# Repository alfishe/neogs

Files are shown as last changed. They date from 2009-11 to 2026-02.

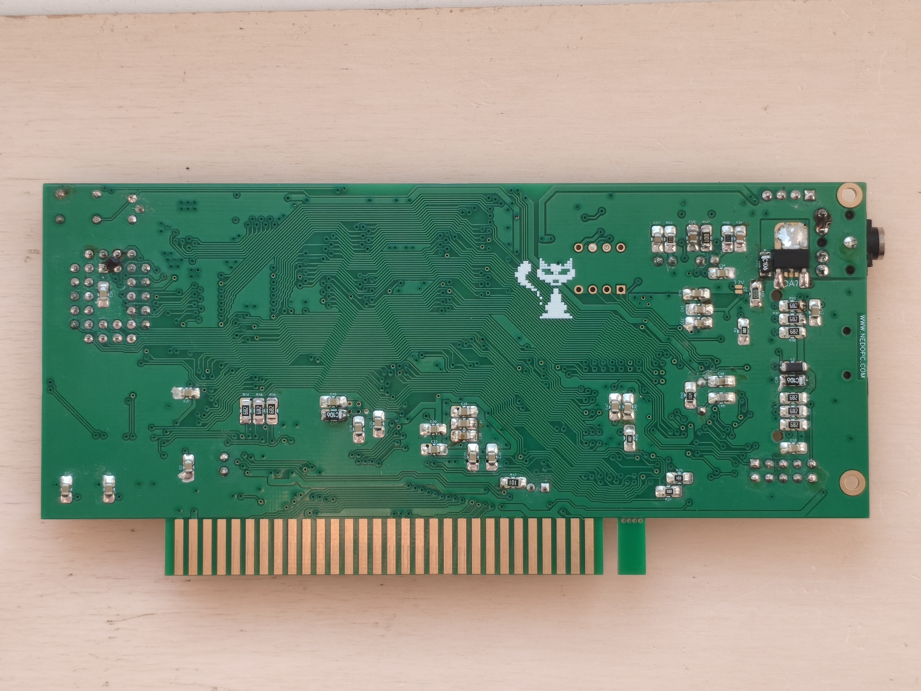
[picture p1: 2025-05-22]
docs/photo/revC-VS/IMG_20250522_185913.jpg

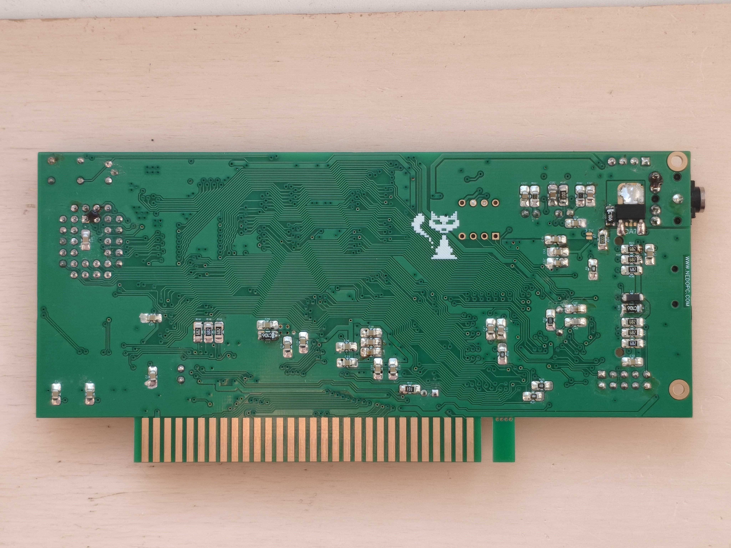
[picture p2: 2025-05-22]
docs/photo/revC-VS/IMG_20250522_185911.jpg

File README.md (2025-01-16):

Музыкальная карта NeoGS для ZXBUS     

#### Музыкальная карта NeoGS для ZXBUS!

#### [english](ngs_eng.php)

**ВНИМАНИЕ!** **Изделие поставляется независимым производителем. Обращаться по поводу приобретения к Виталию [tetroid@inbox.ru](mailto:tetroid@inbox.ru).**

- - -

_Автор фотографий: Алексей Курепин._

NGS rev.C front (http://nedopc.com/gs/neogs_c_front.jpg) NGS rev.C back (http://nedopc.com/gs/neogs_c_back.jpg)  

Звуковая плата **NeoGS** предназначена для проигрывания трекерной (MOD) и сжатой (MP3) музыки на Spectrum-совместимом компьютере оснащенным слотом ZXBUS.

**Разработка:**  
hardware: Вадим Акимов (LVD), Чунин Роман (CHRV), Вячеслав Савенков (Savelij), Жабин Алексей (KOE), Василий Климов (JTN);  
software: Вячеслав Савенков (Savelij).

### Характеристики:

*   полная программная совместимость с General Sound (далее GS);
*   гибкая архитектура, основанная на fpga (Altera EP1K30);
*   собственная память 4 мегабайта RAM, 512 килобайт flash-ROM;
*   расширенные способы адресации памяти: 2 окна проецирования, полное исключение ROM из адресного пространства;
*   Z80 с переключаемой частотой (10, 12, 20 и 'турбо'-24 МГц);
*   8 аппаратных звуковых каналов с громкостями (в 2 раза больше, чем у GS);
*   mp3-декодер (аналог vs1011) с аппаратным SPI для пересылки данных;
*   интерфейс SD-card с аппаратным SPI для пересылки данных;
*   DMA-доступ спектрума в память NeoGS (пересылка данных между спектрумом и NeoGS командами LDI, LDIR и подобными);
*   возможность полностью автономной работы (проигрывание модулей и mp3-файлов с SD-карточки по плейлисту, при этом сброс спектрума не влияет на NeoGS).

### Обновления:

Апгрейд прошивки от 15.06.2013 [здесь](up130615.zip).  
Ускорена конвертация загруженного модуля. Частота процессора всегда 20 МГц вместо стандартных 12 МГц, выставляется загрузчиком.

Апгрейд прошивки от 19.01.2011 [здесь](up110119.zip).  
Поддержка версий с 4Мb RAM.

Апгрейд прошивки от 03.07.2009 [здесь](up090703.zip).  
Поддержан DMA режим работы. Также появился загрузчик кода с SD карты. Описание загрузчика в прилагаемом с флашером документе.

Апгрейд прошивки от 03.11.2008 [здесь](up081103.zip).

### Документация:

_Форум поддержки пользователей **[здесь](http://forum.nedopc.com)**_.

Принципиальная схема (revision C) [здесь](scheme.pdf).

Монтажная схема (revision C) [здесь](montage.pdf).

Руководство пользователя для печати (revision C) [здесь](ngs_c.pdf).

Руководство по сборке платы (revision C) [здесь](ngs_c_soldering.pdf).

Документация для производства [здесь](ngs_c.zip) \[PCAD\] (использование в коммерческих целях только по договоренности с представителями [NedoPC](/aboutus.php)).

О прошивке NeoGS (revision C) [здесь](ngs_c_flash.pdf).

Бинарные файлы прошивок (revision C) [здесь](ngs_c_roms.zip).

Руководство программиста NeoGS [здесь](ngspgm_01a.pdf) и заголовочный файл с описанием портов NeoGS [здесь](ports.zip).

Руководство программиста General Sound [здесь](gs_prog.pdf).

Зеркало исходников (SVN) доступно на сайте [**ZXEVO.RU**.](http://svn.zxevo.ru/listing.php?repname=ngs)

Файл прошивки для записи в ПЗУ из SVN: [**full\_ngs.rom**.](http://svn.zxevo.ru/filedetails.php?repname=ngs&path=%2Fz80%2Fcreate_update%2Ffull_ngs.rom)

**ЦЕНЫ:** [здесь](tetroid.nedopc.com).

### Software:

Программа **Neo Player Light** для проигрывания mp3 музыки на NeoGS [здесь](npl.php).

Программа **Neo8Tracker** трекер/редактор для NeoGS [здесь](neo8tracker/neo_tracker.php).

Программа **Z-PLAYER** проигрыватель mod'ов для GS и NeoGS [здесь](zplayer/zplayer.php).

Страничка с General Sound играми и утилитами на VTRDOS [здесь](http://vtrdos.ru/gs.php).

Страничка с образами дисков с музыкой на ZXAAA [здесь](http://zxaaa.untergrund.net/DISKAAA4.html).

### История версий:

**Revision C:**

*   Уменьшена высота платы (до 61мм без учета разъема).
*   Увеличен размер памяти до 4Мб.
*   Добавлен джампер RESET для разрешения сброса карты при сбросе компьютера.
*   Изменена элементная база (совместимость по прошивкам fpga сохранена).

**[Revision B:](ngsb.zip)**  
_Спонсоры:_ GoodBoy, Valeron, Mick!

*   Исправлены ошибки первой версии.
*   Добавлен 3.5' аудио разьем.
*   Убрана кнопка горячего старта.

**Revision A:**

*   Первая версия, опытная.

- - -

Email: [nedopc@mail.ru](mailto:nedopc@mail.ru), [nedopc@yandex.ru](mailto:nedopc@yandex.ru).

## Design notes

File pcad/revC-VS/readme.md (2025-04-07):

# NeoGS revision C-VS

NeoGS с возможностью установки mp3 декодеров серии VS10xx (VLSI solutions).

Добавлена поддержка следующих чипов:
- VS1001
- VS1011
- VS1003
- VS1053
- VS1063

**Внимание:** Файлы проекта подготовлены в системе PCAD2006

## Изменения в схеме NeoGS.sch (по сравнению с revision C):
- добавлена резистивная нагрузка для чипов VS10xx
- добавлены DA1' и DA7\*' (LDO в SOT23-5) как альтернатива к DA1 и DA7 
- добавлен microSD разъем XSD1\* как альтернатива к SD разъему
- добавлен D8\* для mp3 декодеров в LQFP8 от VLSI
- добавлены shorts J2 для выбора питания чипов
- добавлен DA7\* (нужно только для VS чипов с питанием отличным от 3.3V)
- заменен X2 на классический аудио-разъем (как на TurboFMpro)
- у резисторов буквы номинала переведены в верхний регистр (вместо k теперь K)
- исправлены направления портов для цепей sd карты
- исправлены направления портов для некоторых цепей (например RD0..RD7 теперь отображаются как двунаправленные)
- выделены части схемы в блоки
- шрифты изменены в ttf 

## Изменения в схеме NeoGS.lib (по сравнению с revision C):
- добавлен элемент ME6211B (LDO SOT23-5)
- добавлен элемент MICROSD
- добавлен элемент классического аудио-разъема 
- исправлен элемент ECAPCHIP (+ вместо черточки)
- исправлен элемент ECAPCHIPB (+ вместо черточки, отверстие с метализацией)

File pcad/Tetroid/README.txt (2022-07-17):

Михаил:

Изменения в монтажной схеме NeoGS Rev. C3 по сравнению с Rev. C

Резистор R22 перенесен на место между R30 и L2

Конденсатор C11 повернут на 90 градусов

Резистор R17 устанавливать 1 Ком

Резисторы R48 и R51 устанавливать 680 Ом

Изменен разъем SD-карты

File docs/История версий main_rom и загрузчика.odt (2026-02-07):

История версий основной прошивки NeoGS

07.02.2026 Версия 1.11

- исправлено несоответствие версий основной прошивки.

11.12.2024 Версия 1.11

- переделано определения количества страниц памяти, теперь определяет размер памяти 512К, 2048К, 4096К.

08.08.2014 Версия 1.10

- внесено исправление команды 9xx.

18.06.2013 Версия 1.09 (1.06-1.08)

- ускорена конвертация загруженного модуля.

- частота процессора всегда 20 МГц вместо стандартных 12 МГц, выставляется загрузчиком.

- автоматическое определение количества памяти 2 или 4 мегабайта.

- еще что-то по мелочи.

История версий загрузчика.

07.02.2026 Версия 0.21

- только пересобрана в процессе тестирования.

18.06.2013 Версия 0.21

- исправлены недоработки FAT драйвера.

- добавлена возможность изменения частоты работы процессора и считывания текущей установленной частоты для работы основной прошивки.

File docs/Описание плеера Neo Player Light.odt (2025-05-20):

Neo Player Light v0.60

Системные требования:

ZX-Spectrum;

48 Кб памяти;

наличие звуковой платы NeoGS c MP3 декодером на борту. Поддерживаются чипы:

VS1001, VS1011, VS1003, VS1053, VS1063.

ПРЕДУПРЕЖДЕНИЯ.

Для замены карты сначала нажать клавишу «0» и только потом менять SD карту. Замена карты при проигрывании файла вызовет зависание внутреннего плеера и самой программы.

Выход из программы со сбросом в BASIC 128.

Цветная полоса под названием и версией отображает цветом тип установленного MP3 чипа на плате NeoGS. На правой стороне отображается номер возвращаемый самим чипом.

Программа Neo Player Light предназначена для проигрывания файлов MP3 и MOD с использованием звуковой платы NeoGS на компьютере ZX-Spеctrum. Проигрываются все найденные на SD карте MP3 файлы с зацикливанием по кругу. Показывается имя файла только для текущего проигрываемого файла. Поддерживаются длинные имена файлов (только RUS и ENG). Просмотр содержимого SD карты не предусмотрен.

Проигрывание осуществляется со встроенной SD карты. Поддерживаются все разновидности карт (стандартные, микро и мини SD), максимальный объем ограничен спецификацией на SD карточки версии 2.0 и составляет 32 гигабайта. Поддерживаются карты отформатированные для файловой системы FAT 12/16/32.

Программа состоит из двух частей: внутренний плеер с внешним управлением загружаемый непосредственно на NeoGS и блок управления работающий со стороны компьютера.

Внутренний плеер полностью независим. После запуска на проигрывание из программы можно выйти. Возможно управление путем подачи команды записью в порт GS (смотреть в конце описания).

Блок управления предназначен для подачи команд на внутренний плеер загруженный в звуковую плату и отображения состояния загруженного плеера. Отображается: количество найденных файлов, номер и имя проигрываемого файла, при проигрывании MP3 отображается: время проигрывания, состояние встроенного в MP3-декодер простенького Treble/Bass, Virtual Surround, состояние функции MUTE. При проигрывании MOD отображается длина модуля, текущая проигрывамая позиция и нота.

Управление осуществляется цифрами 0-9, SS+1, SS+5, Space, Enter др.

Управляющие клавиши:

1-перейти к предыдущему файлу

SS+1-перейти к первому файлу предыдущей директории

2-начать воспроизведение файла

3-поставить плеер на паузу

4-остановить воспроизведение

5-перейти к следующему файлу

SS+5-перейти к первому файлу следующей директории

6-уменьшить громкость

7-увеличить громкость

8-включить/выключить Virtual Surround (только для MP3)

9-включить/выключить Treble/Bass (только для MP3)

0-поменять SD карту

Enter-включить/выключить режим MUTE (играть молча) :)

Space-выйти из программы без остановки проигрывания.

SS+Z-(Hidden Key, в меню на экране не отображена) переключение режима перезапуска перед воспроизведение нового файла.

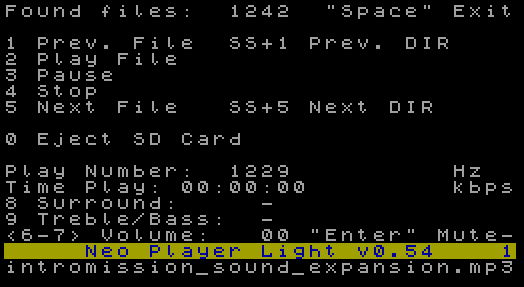
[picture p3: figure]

Внешний вид плеера

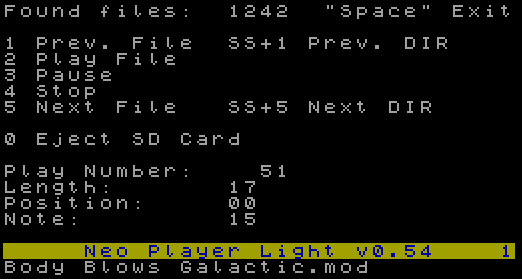
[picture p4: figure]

при проигрывании MOD при проигрывании MP3

Вверху указывается количество найденных MP3 и MOD файлов во всех директориях. В связи с тем что плеер занимает и использует одну большую страницу (32 килобайта) максимальное количество файлов найденных на встроенной карточке примерно 6000 штук, количество найденных файлов зависит от количества директорий. Чем большее количество директорий, тем меньше файлов будет найдено. Файлы в корневой директории ищутся в последнюю очередь и возможна ситуация, при большом количестве файлов близком к максимальному, когда файлы корневого каталога будут недоступны.

В середине экрана указывается номер проигрываемого файла, строкой ниже отображается время проигрывания файла. В режиме проигрывания MP3 отображается режим проигрываемого файла (может принимать значения stereo, joint stereo, dual channel, mono), битрейт и частота файла. В режиме проигрывания MOD длина модуля, текущая позиция и нота. Ниже названия программы и версии выводится название текущего файла. Длина выводимого имени до 255 символов, для названия отведена нижняя треть экрана полностью.

Воспроизведение каждого нового MP3 файла начинается с перезапуска MP3 чипа. По умолчанию перезапуск программный для устранения щелчков. При проблемах с MP3 чипом можно переключить на полный сброс чипа, что будет сопровождаться щелчками между воспроизводимыми файлами. Индикация текущего режима сброса осуществляется в правом верхнем углу в надписи «Space». Если надпись имеет вид «Space», то включен режим по умолчанию (программный). Если надпись имеет вид «SPACE», то включен полный сброс.

При первом запуске программы после включения компьютера позиция проигрывания устанавливается на первый найденный файл. Местоположения файлов значения не имеет. Поиск производится по всем директориям любого уровня вложенности.

Проигрывание осуществляется по кругу. После воспроизведения последнего файла осуществляется переход на первый файл.

При переходе к следующему файлу клавишей «5» после последнего файла произойдет переход на первый, при переходе к предыдущему клавишей «1» после первого произойдет переход на последний.

При переходе сочетанием клавиш «SS+1» и «SS+5» директории так же зациклены по кругу, воспроизведение начинается с первого файла в директории. Переход не будет осуществляться, если найдена одна директория с файлами или файл только один.

По клавише «Space» осуществляется сброс компьютера с выходом в Basic128. Если на звуковой плате запущен загруженный плеер, то при повторном запуске программы будет отображено состояние плеера. Выходить из программы сбросом компьютера не рекомендуется, так как воспроизведение может остановиться из-за попадания сброса в цикл обмена между программой и внутренним плеером.

При запуске программы и удержании клавиши «SS» принудительно загружается внутренний плеер на звуковую плату. При не нажатой клавише SS программа пытается обнаружить загруженный плеер и установить с ним связь.

При запуске программы и удержании клавиши «CS» на Пентагоне v2.2 программа будет запущена при отключенном турбо режиме. По умолчанию и не нажатой клавише программа запустится с включенным турбо режимом.

История версий плеера Neo Player Light

20.05.2025 Версия 0.60

- добавлена поддержка чипов VS1003, VS1053, VS1063.

11.12.2024 Версия 0.59

- в сборке под Sprinter добавлено принудительное отключение турбо режима.

03.09.2024 Версия 0.58

- добавлена поддержка новых чипов.

- переделан детект типа MP3 чипа.

26.04.2023 Версия 0.57

- исправлено, не работало на картах более 4Gb. Переделан поиск директорий и файлов.

22.04.2023 Версия 0.56

- добавлена сборка (адаптация) для компьютера Sprinter в виде EXE файла.

- мелкое исправления в FAT драйвер внутреннего плеера.

20.02.2022 Версия 0.55

- в Basic загрузчике исправлен адрес запуска кодового блока из-за переноса плеера в другой адрес.

- переделана инициализация переменных FAT.

28.05.2021 Версия 0.54

- исправлено зависание выхода/перезапуска плеера при отсутствии SD карты в NeoGS

29.09.2014 Версия 0.53 Исправление

- исправлена проблема неправильного возвращения кода при выходе из FAT драйвера внутреннего плеера из-за чего при большом размере кластера происходило принудительное переопределение SD карты.

08.08.2014 Версия 0.52 Исправление

- исправлена ошибка при загрузке MOD файлов размером более 2Мб приводящая к зависанию внутреннего плеера.

17.06.2013 Версия 0.51 Обновление

- добавлено проигрывание MOD файлов.

- исправлены ошибки FAT драйвера.

- добавлен вывод номера установленного чипа, выводится на цветной полосе справа.

- цвет полосы зависит от номера чипа (0-3) и устанавливается от белого (для 0) до зеленого (для 3).

- сделан таймаут на ожидание обмена, теперь сброс Спектрума не подвешивает плеер.

08.03.2009 Версия 0.44. Добавлена инфа о проигрываемом файле.

- сделан вывод инфы о проигрываемом файле: частота дискретизации, битрейт, режим stereo/joint stereo/dual channel/mono.

- регулировка тембров для VS1011 пока оставлена ради эксперимента, вдруг у кого заработает.

- немного переделана обработка нажатых клавиш. Теперь по быстрее на нажатия реагирует.

14.02.2009 Версия 0.43. Экспериментальная версия.

- собрал пробную версию с регулировкой тембров для VS1011. Не понятно отсутствие регулировки по высоким, басы регулируются нормально.

15.01.2009 Версия 0.42. Исправление мелких недостатков и добавлен автодетект.

-сделан автодетект какой MP3 чип установлен на NeoGS.

-сделал индикацию чипа в виде цветной полосы на которой печатается версия плеера: белый цвет для VS1001, желтый цвет для VS1011.

-снизил рабочую частоту обратно до 12 МГц из-за подглюкивания счетчика времени на MP3 чипе VS1011.

17.11.2008 Версия 0.41. Исправление мелкого недостатка процедуре SOFT RESET.

-в процедуру SOFT RESET добавлено передача 2048 байт нуля перед сбросом и передача одного нуля после сброса.

15.11.2008 Версия 0.4. Добавлено управление.

-сделан переход по директориям содержащими файлы MP3.

-добавлены соответствующие надписи в экранное меню.

-добавлено в меню строка названия плеера и версии.

-изменен запуск программы для правильного определения с каким GS запущен плеер. Теперь сброс GS/NeoGS производится принудительно только при удержании клавиши «SS» при запуске плеера. Сделано для принудительного обновления кода плеера на GS.

-помимо упаковки программы код для GS тоже упакован, так как размер внутреннего плеера уже не вписывается в диапазон адресов #5100-#5FFF. Новое место дислокации изменено на #4600.

13.11.2008 Версия 0.35. Отлов ошибок.

-неправильно обсчитывался последний кластер, из-за чего при нахождении последнего сектора файла в последнем секторе кластера происходило зависание.

-сделана блокировка для случая, когда размер файла кратен количеству кластеров.

12.11.2008 Версия 0.34. Переделано играние MP3 файла.

-играние переделано с точностью до сектора, а не как в предыдущих версиях с точностью до кластера, из-за чего прихватывало хвосты старых перезаписанных MP3 файлов и выдавало левые звуки в конце файла.

11.11.2008 Версия 0.33. Переделка автодетекта.

-изменен автодетект.

-автодетект оторван от HARD RESET и сделан отдельной функцией в драйвере SD карты.

-сделано управление частотой NeoGS по номеру 0-3 в порядке возрастания, добавлено в драйвер SD карты.

09.11.2008. Версия 0.32. В связи с предоставлением доступа к старому GS у КОЕ сделал новую версию.

-сделан автодетект определения GS/NeoGS. Сборка с автодетектом предварительная. При проверке под Unreal 0.37.0 пока вешается, на реале работает нормально. Будет дорабатываться.

08.11.2008 Версия 0.31. В связи с выходом новой прошивки для NeoGS от 03.11.2008 сделал новую экспериментальную версию.

-внутренний плеер переведен на работу на частоте 24 МГц по умолчанию. Все предыдущие версии работали на 12 МГц.

-сделана возможность переключать какой сброс делать перед воспроизведением каждого файла SOFT или HARD (для MP3 чипа).

04.11.2008 Версия 0.3. При опробовании новых версий Unrel Speccy обнаружены некоторые ошибки.

-исправлена ошибка при отсутствии на SD карте MP3 файлов.

-дописано определение наличия/отсутствия MBR и определение разрядности FAT при отсутствии таковой.

-переделана последовательность действий при смене SD карты.

-добавлен индикатор жизни плеера при длительном поиске файлов на карточке.

-определился с упаковщиком. Теперь пакую Hrust'ом, проблем пока не наблюдается.

-сделано определение наличия/отсутствия MP3 декодера на GS/NeoGS. Не проверено, так как не на чем. На NeoGS на реале работает, проблем не наблюдается.

24.10-26.10.2008 Версия 0.2. В связи с обнаруженными зависаниями сделано несколько тестовых программ на базе плеера версии 0.11.

-исправлены ошибки ФАТ драйвера.

-исправлен поиск директорий и файлов.

-из-за непонятных глюков упаковщика PCD программа временно поставляется не упакованной. Проводятся поиски альтернативы не нарушающей работу программы.

-во внутренний плеер добавлен переводчик HEX2DEC и перегон в текстовый вид для одно и двух байтовых чисел с передачей на Спек готовых данных для печати на экране.

23.10.2008 Версия 0.11. В связи с обнаруженным CHRV зависаний на Пентагоне 1.4 попытался исправить ошибки.

-исправлена ошибка в FAT драйвере.

-внесены исправления в поисковик директорий и файлов.

-исправлено несоответствие описания и реальной реализации (клавиша SS).

-добавлена возможность запуска в турбо/не турбо режиме для Пентагона v2.2 (клавиша CS).

-немного переделан запуск и определение наличия NeoGS. При отсутствии платы запуск происходит с задержкой.

22.10.2008 Плеер переименован, присвоена версия 0.1.

-в процессе обновления и дописания умудрился накодить нечто, что повесило NeoGS до состояния, когда перестал мигать светодиод на плате. Спецэффект повторить не удалось.((

-в процессе отладки удалось завесить звуковую плату до состояния, когда запись в порт сброса отсутствовала какая-либо реакция. Возврат в рабочее состояние удалось осуществить только кнопкой.))

-обновлена версия ФАТ драйвера.

-добавлен поиск всех директорий.

-добавлен поиск всех MP3 файлов.

-изменена последовательность смены SD карты.

??.07-28.08.2008 Первая версия, рабочее название Play_NGS.

-первое явление на всеобщее обозрение CC'08.

-освоена SD карта и MP3-декодер, встроенные в NeoGS.

-написан драйвер по аналогии с драйвером Z-контроллера, в драйвер добавлены подпрограммы управления MP3-декодером.

-плеер разбит на две части: внутренний для загрузки на NeoGS и внешний блок управления. Внешней программе сделан текстовый вид с упрощенным описанием управления и отображение текущего состояния, управление по нажатию клавиш.

-расписаны и упорядоченны внутренний формат команд и команды внешнего управления. Устаканен внешний вид.

-воспроизведение MP3 файлов только из корневой директории.

-при отсутствии MBR веселые глюки и прочие спецэффекты.

-сделана возможность выхода из плеера/запуск плеера без прерывания воспроизведения.

-в последний момент перед отъездом на CC добавлен шрифт для правильного отображения русских имен файлов.

-длинные имена файлов поддержаны изначально.

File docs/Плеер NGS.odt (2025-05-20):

Внутренний плеер с внешним управлением для NeoGS v0.60

Команды и параметры для плеера подаются и снимаются через стандартные порты ГС. При передаче команды с параметрами, параметры читаются/пишутся от старшего к младшему. Команды без параметров и ожидаемых ответов можно подавать хоть из Бейсика, если код плеера уже крутится на NeoGS.

Все куски кода для работы со стороны Спека. Плеер должен быть уже загружен и запущен. Адрес загрузки в NeoGS и адрес запуска #8000. Расположение

Для подключения к плееру на лету с проверкой, что именно крутится на NeoGS использую следующий финт ушами:

LD B,#60

XOR A

OUT (GSDAT),A

LD A,#1D

OUT (GSCOM),A

LABEL1 EI

HALT

DI

DEC B

JR Z,RESET;ответа не дождались, полный сброс

IN A,(GSCOM)

RRA

JR C,LABEL1

IN A,(GSDAT)

CP #77;код плеера выдаст #77

JR Z,WARM;ответил плеер, подключаемся к загруженному коду

CP #8B

JR Z,COLD;ответила стандартная прошивка, идем грузить код

;или нет ничего, или GS/NeoGS висит. Сброс. Далее по тексту.

RESET LD A,#80

OUT (#33),A

EI

HALT

HALT

DI

LD A,#F3

OUT (GSCOM),A

LD B,#30

LABEL2 EI ;для стандартной прошивки gs105a.rom

HALT ;и старее время инициализации довольно

DI ;велико и ответа здесь не дождемся

DEC B

JP Z,NO_GS;GS не найден, ответа не дождались

IN A,(GSCOM)

RRA

JR C,LABEL2

;кто-то что-то ответил

COLD ;загрузка кода плеера в GS или NeoGS стандартными командами ;прошивки и запуск загруженного кода

WARM ;подключение к плееру на лету и прочий код

Коды команд управления внутренним плеером.

Все команды плееру подаются через порт данных (#B3), через порт команд (#BB) должен подаваться командой #1F (плеер замаскирован и управляется через пустую команду прошивки).

#00-перезапустить загруженный код без HARD RESET MP3 чипа. Останавливает воспроизведение. Без параметров.

XOR A

OUT (GSDAT),A

LD A,#1F

OUT (GSCOM),A

CALL WC

CALL WN

IN A,(GSDAT)

После инициализации выдает ответы:

#77-инициализация прошла успешно, обнаружен NeoGS, SD карта и MP3 файлы найдены. Ждет подачи команд.

#AA-файл не найден

#BB-MP3 файлов не обнаружено.

#СС-NeoGS не найден, плата OldGS.

#DD-FAT не обнаружен.

#EE-SD не прошла инициализацию или отсутствует.

#01-перейти на предыдущий трек. По умолчанию при нахождении на первом треке переходит на последний. Без параметров.

LD A,1

OUT (GSDAT),A

LD A,#1F

OUT (GSCOM),A

#02-запустить проигрывание с текущего номера файла. Без параметров.

LD A,2

OUT (GSDAT),A

LD A,#1F

OUT (GSCOM),A

#03-поставить плеер на паузу. Без параметров.

LD A,3

OUT (GSDAT),A

LD A,#1F

OUT (GSCOM),A

#04-остановить воспроизведение. Без параметров.

LD A,4

OUT (GSDAT),A

LD A,#1F

OUT (GSCOM),A

#05-перейти на следующий трек. По умолчанию при нахождении на последнем номере переходит на первый. Без параметров.

LD A,5

OUT (GSDAT),A

LD A,#1F

OUT (GSCOM),A

#06-меняет состояние Treble/Bass на противоположное. Без параметров.

LD A,6

OUT (GSDAT),A

LD A,#1F

OUT (GSCOM),A

#07-меняет состояние Virtual Surround на противоположное. Без параметров.

LD A,7

OUT (GSDAT),A

LD A,#1F

OUT (GSCOM),A

#08-увеличить громкость на единицу. Без параметров.

LD A,8

OUT (GSDAT),A

LD A,#1F

OUT (GSCOM),A

#09-уменьшить громкость на единицу. Без параметров.

LD A,9

OUT (GSDAT),A

LD A,#1F

OUT (GSCOM),A

#0A-включение/выключение громкости. Без параметров.

LD A,#0A

OUT (GSDAT),A

LD A,#1F

OUT (GSCOM),A

#0B-получить 6 байт (текст) проигранного времени переведенные в десятичный вид в формате ЧЧММСС.

LD A,#0B

OUT (GSDAT),A

LD A,#1F

OUT (GSCOM),A

CALL WC

LD E,6

LD BC,GSDAT

LD HL,куда положить

LABEL CALL WN

INI

DEC E

JR NZ,LABEL

#0C-получить текущее состояние параметров команд 6-10 и уровень громкости одним 16-битным ломтиком.

Формат ответа:

бит 15-1-включен Treble/Bass, 0-выключен.

бит 14-1-звук выключен (MUTE ON), 0-включен (MUTE OFF).

бит 13-1-пошел новый файл, 0-текущий. Устанавливается при открытии нового файла, сбрасывается после запроса имени файла.

бит 12-1-перед каждым MP3 файлом делается HARD RESET, 0-SOFT RESET

бит 11-1-\ номер установленного MP3 чипа

бит 10-1-/ 0-VS1001, 1- VS1011, 2-VS1002, 3-VS1003

бит 9-1-MOD файл, 0-MP3 файл

бит 8-1-включен Virtual Surround, 0-выключен.

биты 7-0-уровень громкости. 0-максимум, #7F-минимум, при MUTE ON отдает #FE.

По умолчанию при первом запуске все биты выставлены в «0», кроме бита 11-зависит от установленного чипа.

LD A,#0C

OUT (GSDAT),A

LD A,#1F

OUT (GSCOM),A

CALL WC

CALL WN

IN A,(GSDAT)

LD H,A;сняли старшие 8 бит

CALL WN

IN A,(GSDAT)

LD L,A;сняли младшие 8 бит

#0D-получить номер текущего проигрываемого файла. Читать 16-битное число. Без параметров.

LD A,#0D

OUT (GSDAT),A

LD A,#1F

OUT (GSCOM),A

CALL WC

CALL WN

IN A,(GSDAT)

LD H,A;сняли старшие 8 бит

CALL WN

IN A,(GSDAT)

LD L,A;сняли младшие 8 бит

#0E-подать номер для плеера. Если число больше реально найденных файлов, команда будет проигнорирована.

LD A,#0E

OUT (GSDAT),A

LD A,#1F

OUT (GSCOM),A

CALL WC

LD HL,номер описателя

LD A,H

OUT (GSDAT),A

CALL WD

LD A,L

OUT (GSDAT),A

#0F-SOFT/HARD перезапуск МР3 декодера. Зависит от включенного режима. Проверить можно по состоянию бита 12 функции #0F. Без параметров.

LD A,#0F

OUT (GSDAT),A

LD A,#1F

OUT (GSCOM),A

#10-получить тип ФАТ. Если ФАТ не определен или нет SD карты выдаст #FF. Без параметров.

LD A,#10

OUT (GSDAT),A

LD A,#1F

OUT (GSCOM),A

CALL WC

CALL WN

IN A,(GSDAT)

#11-получить длинное имя файла, если найдено. Если длинного имени нет, получить короткое имя в формате FILENAME.EXT (в виде 8.3). Подать 16-битное число и получить запрошенное. Принять 256 байт, последний байт 0.

LD A,#11

OUT (GSDAT),A

LD A,#1F

OUT (GSCOM),A

CALL WC

LD HL,номер описателя

;BIT 7,H=1 принять описатель текущего файла

;BIT 7,H=0 указанный номер в младших 15 битах

LD A,H

OUT (GSDAT),A

CALL WD

LD A,L

OUT (GSDAT),A

CALL WD

LD HL,куда положить

LD E,0

LD BC,GSDAT

LABEL CALL WN

INI

DEC E

JR NZ,LABEL;читаем сколько запросили

#12-получить описатель файла. Подать 16-битное число и получить запрошенное. Если бит 15=1, получить текущий описатель. Принять 33 байта. 32 байта описателя файла (смотреть формат описателя на FAT) и 1 байт флажков.

Формат последнего байта:

7=0-выбрана директория

7=1-выбрано директория «..»

0=0-только короткое имя

0=1-описатель имеет длинное имя

LD A,#12

OUT (GSDAT),A

LD A,#1F

OUT (GSCOM),A

CALL WC

LD HL,номер описателя

;BIT 7,H=1 принять текущий номер

;BIT 7,H=0 указанный номер в младших 15 битах

LD A,H

OUT (GSDAT),A

CALL WD

LD A,L

OUT (GSDAT),A

CALL WD

LD HL,куда положить

LD E,#21

LD BC,GSDAT

LABEL CALL WN;читаем сколько запросили

INI

DEC E

JR NZ,LABEL

#13-получить количество найденного по расширению. Читать 16-битное число. Без параметров.

LD A,#13

OUT (GSDAT),A

LD A,#1F

OUT (GSCOM),A

CALL WC

CALL WN

IN A,(GSDAT)

LD H,A;сняли старшие 8 бит

CALL WN

IN A,(GSDAT)

LD L,A;сняли младшие 8 бит

#14-передача 512 байт через порт данных GS на МР3 декодер. Применяется для передачи с внешнего носителя на декодер для проигрывания. Без параметров.

LD BC,GSDAT

LD DE,#0200;длина=1 сектор (512 байт)

LD A,#14

OUT (GSDAT),A

LD A,#1F

OUT (GSCOM),A

CALL WC

LABEL IN A,(C)

OUT (GSDAT),A

IN A,(GSCOM)

RLA

JR C,$-3

DEC DE

LD A,D

OR E

JR NZ,LABEL

#15-получить перекодированное в десятичный вид 16-битное число найденных файлов. Принять 5 байт. Без параметров.

LD A,#15;получить 5 байт перекодированного числа

OUT (GSDAT),A

LD A,#1F

OUT (GSCOM),A

CALL WC

LD E,5

LD BC,GSDAT

LD HL,куда положить

LABEL CALL WN

INI

DEC E

JR NZ LABEL

#16-получить перекодированное в десятичный вид номер текущего файла увеличенный на единицу для показа с не нулевого значения . Принять 5 байт. Без параметров.

LD A,#16;получить 5 байт перекодированного числа

OUT (GSDAT),A

LD A,#1F

OUT (GSCOM),A

CALL WC

LD E,5

LD BC,GSDAT

LD HL,куда положить

LABEL CALL WN

INI

DEC E

JR NZ LABEL

#17-переключение HARD/SOFT RESET перед каждым MP3 файлом. Узнать текущее значение можно командой #0C и проверкой бита 12. Без параметров.

LD A,#17

OUT (GSDAT),A

LD A,#1F

OUT (GSCOM),A

#18-перейти на первый файл предыдущей директории. Если директория содержащая MP3 файлы одна или файл MP3 один, перехода не будет. Без параметров.

LD A,#18

OUT (GSDAT),A

LD A,#1F

OUT (GSCOM),A

#19-перейти на первый файл следующей директории. Если директория содержащая MP3 файлы одна или файл MP3 один, перехода не будет. Без параметров.

LD A,#19

OUT (GSDAT),A

LD A,#1F

OUT (GSCOM),A

#1A-управление темброблоком. Только для чипа VS1011. Регулировка частоты и подъема/спада тембра.

TREBLE - частота изменяется от 0 до 15 с шагом 1 Кгц, диапазон регулировки от -8 до +7 с шагом 1,5 Дб.

BASS - частота регулируется от 2 до 15 с шагом 10 Гц, подъем от 0 до 15 с шагом 1 Дб.

Формат команды:

бит 6=1-изменение уровня BASS, 0-не менять

бит 4=1-изменение частоты BASS, 0-не менять

бит 2=1-изменение уровня TREBLE, 0-не менять

бит 0=1-изменение частоты TREBLE, 0-не менять

соответственно биты 7,5,3,1=1-увеличение на единицу, 0-уменьшение.

LD A,#1A

OUT (GSDAT),A

LD A #1F

OUT (GSCOM),A

CALL WC

LD A,xxxxxxxx ;соответствующие биты

OUT (GSDAT),A

#1B-получить текстовую строку (8 байт в виде 12345678) положения регуляторов тембра (только для чипа VS1011). Без параметров.

Формат строки :

12-частота TREBLE

34-уровень TREBLE

56-частота BASS

78-уровень BASS

LD A,#1B

OUT (GSDAT),A

LD A,#1F

OUT (GSCOM),A

CALL WC

LD E,8

LD BC,GSDAT

LD HL,куда положить

LABEL CALL WN

INI

DEC E

JR NZ LABEL

#1C-получить 16-битное число частоты/битрейта/режима проигрываемого файла. Без параметров.

Формат ответа:

15-12 - =0000-MP3,

=1001-WAV

=1010-ничего не проигрывается

11-8 - битрейт

7-6 - 0=stereo, 1=joint stereo, 2=dual channel, 3=mono

5-4 - 0=reserved, 1=layer III, 2=layer II, 3=layer I

3-2 - частота дискретизации

1-0 - 0=MPEG 2,5, 1=MPEG 2,5, 2=MPEG 2, 3=MPEG 1

LD A,#1C

OUT (GSDAT),A

LD A,#1F

OUT (GSCOM),A

CALL WC

CALL WN

IN A,(GSDAT)

LD H,A;сняли старшие 8 бит

CALL WN

IN A,(GSDAT)

LD L,A;сняли младшие 8 бит

Таблицы соответствия битам:

;режимы stereo/mono, биты 7-6

DB “ stereo”

DB “joint stereo”

DB “dual channel”

DB “ mono”

;частоты дикретизации, биты 3-2

DB “11025110252205044100” ;биты 3-2 =0

DB “12000120002400048000” ;биты 3-2 =1

DB “ 8000 80001600032000” ;биты 3-2 =2

;выбор таблицы зависит от layer битов 5-4

;битрейты для layer 3, биты 11-8

DB “ - 32 40 48 56 64 80 96112128160192224256320”

DB “ - 8 16 24 32 40 48 56 64 80 96112128144160”

;битрейты для layer 2, биты 11-8

DB “ - 32 48 56 64 80 96112128160192224256320384”

DB “ - 8 16 24 32 40 48 56 64 80 96112128144160”

;битрейты для layer 1, биты 11-8

DB “ - 32 64 96128160192224256288320352384416448”

DB “ - 32 48 56 64 80 96112128144160176192224256”

#1D-определение, что в ГС. Для стандартной прошивки подать байт 0 (что будет указывать на адрес #2000) и получить в ответ #8B. Код плеера отдаст в ответ #77. Нужно для определения, что крутится на NeoGS для адекватной реакции при запуске плеера со стороны Спека (делать сброс или прицепиться к плееру на «лету»).

XOR A

OUT (GSDAT),A

LD A,#1D

OUT (GSCOM),A

CALL WC

CALL WN

IN A,(GSDAT)

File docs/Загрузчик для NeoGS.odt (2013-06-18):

Загрузчик для NeoGS v 0.21

Загрузчик предназначен для загрузки прошивки (вместо зашитой в ПЗУ) со стороны Спека, со встроенной в NeoGS SD карты, загрузки кода в любую страницу ОЗУ со Спека или SD карточки и запуск на выполнение с произвольного адреса в произвольной странице, получение версии фпга в полностью текстовом виде, проверка CRC16 прошиваемого блока и его заголовка.

Последовательность работы загрузчика

- после программного сброса со стороны Спектрума делается задержка с ожиданием определенных байт через порты команд и данных.

- при превышении лимита времени ожидания делается попытка загрузить прошивку (вместо зашитой в ПЗУ) со встроенной SD карты. Файл для загрузки должен находиться на SD карте и располагаться в корне карточки и иметь имя:

NEOGS.ROM

Все имена должны быть короткими, длинные имена не поддерживаются.

- если файл не найден, то загружается и запускается прошивка зашитая в ПЗУ.

Последовательность доступа к функциям загрузчика

LD A,#80

OUT (GSCTR),A ;сброс NeoGS

NOP

NOP

NOP ;ждем 12 тактов

LD A,#55

OUT (GSDAT),A

OUT (GSCOM),A ;первый ожидаемый байт загрузчиком

CALL WC ;ждем очистки COMMAND BIT

LD A,#AA

OUT (GSDAT),A

OUT (GSCOM),A ;второй ожидаемый байт загрузчиком

CALL WC

;здесь сброса COMMAND BIT ждать несколько дольше пока переносится

;код загрузчика из ПЗУ в ОЗУ

;частота работы процессора после переноса кода устанавливается 12МГц

;при загрузке с SD карты временно устанавливается частота 24МГц

Команды загрузчика доступные в этой версии

Команды и параметры загрузчику подаются также, как и в стандартной прошивке. Сначала записывается байт параметра в порт данных (GSDAT), потом записывается байт в порт команд (GSCOM). Далее остальные байты записываются в порт данных, если они есть. Вызываемые подпрограммы WC, WD, WN такие же как и для стандартной прошивки.

WC IN A,(GSCOM)

RRCA

JR C,WC

RET

WD IN A,(GSCOM)

RLCA

JR C,WD

RET

WN IN A,(GSCOM)

RLCA

JR NC,WN

RET

#00 — загрузить со Спека 32 Кб прошивки вместо загрузки из ПЗУ. Загружает в страницу 0 в адрес 0 ОЗУ. Команда только загружает прошивку, но не запускает.

XOR A

OUT (GSCOM),A

CALL WC

LD HL,адрес откуда передается прошивка

LD DE,#8000 ;длина передачи

LD BC,GSDAT

LOOP OUTI

CALL WD

DEC DE

LD A,D

OR E

JR NZ,LOOP

#01 — запустить прошивку. Устанавливает защиту от записи в странице 0 ОЗУ, куда загружена прошивка. Также выставляет частоту процессора 20 МГц. Без параметров.

#02 — загружает и запускает прошивку из ПЗУ. Полностью соответствует старому загрузчику. Без параметров.

#03 — загружает и запускает прошивку с SD карты. Если найдет. Без параметров.

#04 — загрузка кода со Спека. Загружает в любую страницу ОЗУ в адрес #8000 (32768) до 32Кб. Для загрузки в другую страницу функцию надо вызывать еще раз.

LD A,номер страницы

OUT (GSDAT),A

LD A,4

OUT (GSCOM),A

CALL WC

LD BC,GSDAT

LD DE,размер блока (не более 32768 байт)

LD HL,адрес откуда слать

OUT (C),E

CALL WD

OUT (C),D

CALL WD

LOOP OUTI

CALL WD

DEC DE

LD A,D

OR E

JR NZ,LOOP

#05 — загрузка произвольного файла с SD карты по указанному пути. Поиск по указанному пути всегда осуществляется из корня карточки. Путь должен быть указан в виде DIR1/DIR2/FILENAME.EXT всегда в верхнем регистре.

Загружает в любую страницу ОЗУ по адресу #8000 (32768), кроме страниц 0 и 1. Для страниц 02...#7F загрузка будет производиться пока не закончатся страницы памяти или до окончания файла.

Ограничения на загрузку. В страницу 0 можно загрузить не более 32Кб. Загрузка в страницу 1 запрещена, статус загружаемого файла будет #AA-не найден. Статус загруженного файла проверять функцией 7.

Текстовая строка должна заканчиваться байтом 0, этот же байт означает окончание передачи текстовой строки.

LD A,номер страницы

OUT (GSDAT),A

LD A,5

OUT (GSCOM),A

CALL WC

LD HL,адрес текстовой строки

LD BC,GSDAT

LOOP LD A,(HL)

OUTI

EX AF,AF'

CALL WD

EX AF,AF'

AND A

JR NZ,LOOP

#06 – запуск кода в любой странице по любому адресу.

LD A,номер страницы

OUT (GSDAT),A

LD A,6

OUT (GSCOM),A

CALL WC

LD HL,адрес запуска

LD A,L

OUT (GSDAT),A

CALL WD

LD A,H

OUT (GSDAT),A

CALL WD

#07 – получить статус последнего загруженного файла. Без параметров.

Возвращает следующие байты ответа:

#00-файл загружен.

#AA-файл не найден.

#DD-FAT не обнаружен.

#EE-SD не прошла инициализацию или отсутствует.

LD A,7

OUT (GSCOM),A

CALL WC

IN A,(GSDAT)

#08 – получить распакованную текстовую строку версии страницы.

LD A,номер страницы

OUT (GSDAT),A

LD A,8

OUT (GSCOM),A

CALL WC

LD HL,куда ложить текст

LD BC,GSDAT

LOOP CALL WN

IN A,(C)

LD (HL),A

INC HL

AND A

JR NZ,LOOP

#09 – получить CRC16 заголовка, блока или количество загруженных блоков для прошивания. Подать в порт данных байт, получить 3 байта ответа.

НЕ РЕКОМЕНДУЕТСЯ ДЛЯ ПРИМЕНЕНИЯ, ИСПОЛЬЗУЕТСЯ ПРИ ПРОШИВАНИИ НОВЫХ ПРОШИВОК.

По записи в порт данных:

бит 7=1 — получить количество блоков для прошивания;

бит 7=0 — число от 0 до 7 выбранный блок в заголовке, остальные биты игнорируются

По чтению ответа:

1 – тип ошибки:

#80-все ОК, следующие 2 байта CRC16 запрошенного блока или количество блоков для прошивания. Иначе последнии 2 байта случайные.

#81-CRC16 заголовка ERROR

#82-CRC16 запрошенного блока ERROR

2 – младший байт CRC16 или количества блоков

3 – старший байт CRC16 или количества блоков

LD A,байт

OUT (GSDAT),A

LD A,9

OUT (GSCOM),A

CALL WC

IN A,(GSDAT) ;код ошибки

EX AF,AF'

CALL WN

IN A,(GSDAT) ;младший байт ответа

LD L,A

CALL WN

IN A,(GSDAT) ;старший байт ответа

LD H,A

EX AF,AF'

#0A – загрузить файл обновления. Имя файла фиксированное «NGS_ROM.UPD» Файл должен находиться в корне SD карты NeoGS. Без параметров.

#0B – установка частоты процессора. 0-частота 10 МГц, 1-частота 12 МГц, 2-частота 20 МГц, 3-частота 24 МГц. Для получения текущей частоты установить бит 7 вместо номера частоты.

LD A,номер частоты ;установка частоты по номеру

OUT (GSDAT),A

LD A,#0B

OUT (GSCOM),A

CALL WC

или

LD A,#80 ;получение текущей частоты

OUT (GSDAT),A

LD A,#0B

OUT (GSCOM),A

CALL WC

IN A,(GSDAT)

#1D - находится несколько за пределами команд загрузчика, используется по аналогии с командой #1D стандартной прошивки. Предназначена для проверки загрузчик ли сейчас на NeoGS. По этой команде возвращает через порт данных число #76. Для примера: стандартная прошивка возвращает значение #8B, мой MP3 плеер возвращает #77 когда загружен.

XOR A

OUT (GSDAT),A

LD A,#1D

OUT (GSCOM),A

CALL WC

IN A,(GSDAT)

Все остальные команды, не описанные выше, перезапускают NeoGS со стандартной прошивкой зашитой в ПЗУ.

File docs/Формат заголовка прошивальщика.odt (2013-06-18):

Формат заголовка для прошивальщика v0.11

CRC16 вычисляется по алгоритму CRC16 CCITT. Порядок байт для длины и CRC16 сначала младший байт, потом старший.

При прошивании версии для NeoGS последние 8 байт в странице описателя блока прошиваются в адрес #FFF8 указанной страницы.

Формат даты (по битам):

15=0-бета версия, 1-стабильная

14-9=год сборки (последние 2 цифры)

8-5=месяц сборки

4-0=дата сборки

Смещение Длина Описание

---Заголовок---

0 2 Длина заголовка в байтах

2 4 Текст «NGSF» для NeoGS

6 2 Дата сборки этого файла

8 16 Описатель блока для прошивания (один или несколько)

24 16*N Еще описатели, если несколько

---Далее сами блоки для прошивания---

24+(16*N) N Сам блок

---16 байтный описатель блока---

0 1 Биты 7-3 — зарезервированы для возможного расширения

Биты 2-0 — номер страницы прошивания

2 3 Смещение в байтах от начала файла.

4 2 Размер для прошивания в байтах без CRC16.

6 2 CRC16 этого блока

8 8 Версия прошивки как задумана (6 байтов текста+2 байта даты)

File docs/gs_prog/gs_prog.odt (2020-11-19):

Recoded by Evgeny Muchkin 06.10.1998

SysOp of PALLY_STATION tel: 176-74-19

Last update and correxion by Cyrax, Inc. 18.04.2002

Former GS programmer... ;) email: reptyle@mail.ru

(с) STINGER &

(с) Cyrax, Inc. - (*)

Руководство по программированию

General Sound.

Версия v1.04. Редакция 006.

(отредактировал в документ CHRV)

Оставлен полностью авторский текст за исключением

форматирования и исправления ошибок в тексте.

Добавлено описание исправлений в GS ROM v1.05.

19.11.2020

# changelog

- 2020.11.19: Дока на команду #3E (см. 5.1.60) приведена в соответствие с поведением прошивки GSCOM (Александ Коваленко)

# Краткие технические характеристики GS.

Процессор: Z80, 12MHz, без циклов wait

ROM: 32k, 27256

RAM: Static Ram 128k всего, 112k доступно для модулей и сэмплов в базовой версии

INT: 37.5 KHz Каналы: 4 независимых 8-и битных канала, каждый с 6-и битным контролем громкости.

# Краткое описание GS, или много всякой лабуды.

GS - музыкальная карточка, предназначенная для проигрывания музыкальных модулей и отдельных сэмплов (эффектов).

Модули для GS - это стандартные Амижные и PCшные 4-х канальные MOD файлы, а сэмплы - как Амижные signed sample, так и PCшные unsigned sample.

Проигрыватель MOD файлов в GS является практически полным аналогом ProTracker'а на Амиге и создавался при интенсивном использовании исходников ProTracker'a. (Исходники были из Protracker'а v2.1A by Lars "ZAP" Hamre - Amiga Freelancers)

MOD Player поддерживает все команды Pro Tracker'а, за исключением двух:

- Е01 Filter On Амига-специфичная команда, включает фильтр высоких частот.
- EFX Invert Loop я еще не видел плеера, который бы поддерживал эту команду. Возможно, она поддерживается на каких-то старых плеерах.

GS представляет из себя, по-сути, микропроцессорный комплекс со своим процессором, ПЗУ, ОЗУ и портами, и абсолютно не зависит от главного процессора Спектрума, что позволяет, например, загрузить свой любимый модуль, сбросить Спектрум, загрузить ассемблер и творить под любимую музыку. Soft внутри GS полностью берет на себя задачи проигрывания звука, интерпретации модуля и т.д. Программирование GS'а сводится к передаче байт за байтом модуля и/или сэмплов, а затем требуется только подавать команды типа: запустить модуль, установить глобальную громкость проигрывания модуля, запустить сэмпл #09 в канале #02 и т.д.

Если предполагается загрузить модуль вместе с сэмплами, то в GENERAL требуется загружать вначале модуль, а затем сэмплы.

При загрузке модуля очень рекомендуется оставить свободными 2к памяти, т.е. загружать модули длиной максимум 110K. Это условие не является необходимым, но его исполнение очень желательно в целях совместимости с последующими версиями.

Аналогично очень рекомендуется оставлять по 80 байт для каждого сэмпла, например, если требуется загрузить 63-х килобайтный модуль и 18 сэмплов, то имеем:

Total_Sample_Length=112*1024-63*1024-2*1024-18*80=46688 байт

Это суммарная длина сэмплов, которые при таком положении вещей могут быть загружены.

Если же, например, требуется вычислить, сколько поместится в память GS'а 2‑х килобайтных сэмплов, то это вычисляется следующим образом:

112*1024/(2048+80)=53 сэмпла.

В GS'е имеются 4 физических канала, которые и проигрывают звук.

Каналы 0 и 1 - левые, а 2 и 3 - правые.

# Интерфейс со Спектрумом.

На мир GS смотрит при помощи 4 регистров:

1. Command register - регистр команд, доступный для записи порт по адресу 187 (#BB). В этот регистр записываются команды.
2. Status register - регистр состояния, доступный для чтения порт по адресу 187 (#BB). Биты регистра: 7— Data bit, флаг данных 6 — Не определен 5 — Не определен 4 — Не определен 3 — Не определен 2 — Не определен 1 — Не определен 0 — Command bit, флаг команд Этот регистр позволяет определить состояние GS, в частности можно ли прочитать или записать очередной байт данных, или подать очередную команду, и т.п.
3. Data register - регистр данных, доступный для записи порт по адресу 179 (#B3). В этот регистр Спектрум записывает данные, например, это могут быть аргументы команд.
4. Output register - регистр вывода, доступный для чтения порт по адресу 179 (#B3). Из этого регистра Спектрум читает данные, идущие от GS.

Command bit в регистре состояний устанавливается аппаратно после записи команды в регистр команд. Сбрасываться в 0 он может только из GS, что сигнализирует об определенном этапе исполнения команды.

Data bit в регистре состояний может быть установлен или сброшен как по желанию Спектрума, так и по желанию GS: при записи Спектрумом в регистр данных он аппаратно устанавливается в 1, а после чтения GS'ом из этого регистра сбрасывается в 0. При записи GS в регистр вывода он (все тот же Databit) аппаратно устанавливается в 1, а после чтения из этого порта Спектрумом сбрасывается аппаратно в 0.

Несмотря на то, что регистр данных и регистр вывода расположены в пространстве адресов портов по одному и тому же адресу и воздействуют на один и тот же бит данных, они являются двумя независимыми регистрами. Значение, один раз записанное в один из этих регистров, остается неизменным в нем до новой записи.

Состояние бита данных очень часто не определено, и если в спецификации команд не определены значения этого бита на определенных этапах исполнения команды, недопустимо делать какие-либо предположения относительно значения этого бита.

# Система команд GS.

Вначале позволю себе небольшое отступление от собственно системы команд. GS, как известно, предназначен в основном для проигрывания модулей и сэмплов. В данной версии (1.04) GS ROM допускается загрузка одного модуля и/или до 32 сэмплов.

Каждый сэмпл при загрузке его в память получает свой уникальный идентификатор, который однозначно определяет обращение к данному сэмплу в командах, которые требуют номер сэмпла. Самый первый загруженный сэмпл получает номер (handle) = 1, следующий - номер 2, и т.д.

То же самое применимо и к модулям, и этот единственный загруженный модуль будет иметь handle=1 после загрузки.

Особенностью данной версии является также то, что вначале требуется загружать модуль, а затем уже сэмплы.

Особенности описания команд:

Команды описываются следующим образом:

1. Hex код команды
2. Название команды
3. Выполняемые действия при исполнении команды
4. Формат команды
5. Комментарии к команде

Формат команды описывается следующим образом:

GSCOM EQU 187

GSDAT EQU 179

SC #NN : Послать код команды в регистр команд

LD A,#NN

OUT (GSCOM),A

WC : Ожидание сброса Command bit

WCLP IN A,(GSCOM)

RRCA

JR C,WCLP

SD Data : Послать данные в регистр данных

LD A,Data

OUT (GSDAT),A

WD : Ожидание сброса Data bit, по сути, ожидание, пока GS не примет

посланные ему данные

WDLP IN A,(GSCOM)

RLCA

JR C,WDLP

GD Data : Принять данные из регистра данных

IN A,(GSDAT)

WN : Ожидание установки Data bit,по сути, ожидание очередных данных

от GS

WNLP IN A,(GSCOM)

RLCA

JR NC,WNLP

(*):

<PAUSE> - Просто небольшая задержка кадра два-три.

И напоследок — небольшая последовательность против зависания (иногда помогает)

XOR A

OUT (#B3),A

OUT (#BB),A

IN A,(#BB)

для верности можно и продублировать ;).

## Команды GS:

### #00 Reset flags

Сбрасывает флаги Data bit и Command bit.

SC #00

WC

(Data bit=0, Command bit=0)

### #01 Set silence (*)

Выводит в ЦАПы всех каналов #80. По сути устанавливает тишину.

SC #01

WC

### #02 Set low volume (*)

Устанавливает громкость ЦАПов всех каналов в ноль.

SC #02

WC

### #03 Set high volume (*)

Устанавливает громкость ЦАПов всех каналов в максимум.

SC #03

WC

### #04 Set 'E' 3bits (*)

Устанавливает в 'E' регистре GS 3 младших бита в соответствии с заданным значением (2 младших бита в сущности являются номером канала #00-#03).

SD Chan (#00-#07)

SC #04

WC

### #05 Out volume port (*)

Устанавливает громкость канала, номер которого содержится в 'E', в указанное значение. (Команда срабатывает при условии, что 'E' находится в пределах #00-#03)

SD Volume (#00-#3F)

SC #05

WC

### #06 Send to DAC (*)

Выводит байт в ЦАП канала, указываемого по 'E'.

SD Byte

SC #06

WC

### #07 Send to DAC and to volume port (*)

Выводит байт в ЦАП ('E') с заданной громкостью.

SD Byte

SC #07

WC

SD Volume

WD

### #08 - то же что и команда #00

### #09 Sets one's byte volume. (*)

Установка громкости канала, номер которого задан в 2х старших битах.

SD Byte (ccvvvvvv)

SC #09

WC

cc - Номер канала

vvvvvv - Его громкость

### #0A DAC output (*)

Еще один непосредственный вывод в ЦАП.

SD Byte

SC #0A

WC

SD Chan (#00-#03)

WD

### #0B DAC and Volume output (*)

И наконец последний вывод в ЦАП с установкой громкости.

SD Fbyte

SC #0B

WC

SD Sbyte (ccvvvvvv)

WD

Назначение битов Sbyte как и у к.#09

Команды #01- #0B служат в основном для построения различных Covox'ов и проигрывателей, при этом не слишком углубляясь во внутреннюю структуру GS.

vvvvvv - Его громкость

### #0C Call SounDrive Covox mode (*)

Вызывает режим четырехканального Ковокса, последовательно копирует регистр данных по каналам. Выход из режима автоматически после вывода четвертого байта.

SD CH1

SC #0C

WC

SD CH2

WD

SD CH3

WD

SD CH4

WD

### #0D Call Ultravox mode (*)

Вызывает режим универсального Ковокса, последовательно копирует регистр данных по каналам, число которых регулируется (1-4). В отличие от предыдущего варианта синхронизация не производится. Выход также производится автоматически по записи последнего байта.

SD CHANS

SC #0D

WC

SD CH1

SD CH2

SD CH3

SD CH4

CHANS (4-е младших бита) указывает какие каналы будут задействованы - для включения канала соответствующий бит нужно установить. Если канал выключен, то поступивший байт попадает на следующий включенный канал (если успеет :)

### #0E Go to LPT Covox mode

Переходит в режим одноканального Ковокса, напрямую копирует регистр данных в ЦАПы двух (правого и левого) каналов. Выход из этого режима - запись #00 в регистр команд.

SC #0E

WC

SD \

SD \

... Это вывод в ЦАПы

/

SD /

SC #00

WC

### #0F Go in Profi Covox mode (*)

Переходит в режим двухканального Ковокса, напрямую копирует регистр данных в ЦАПы одного канала, а регистр команд в ЦАПы второго канала. Выход из этого режима - запись #4Е в регистр данных, затем последовательно #0F и #AA в регистр команд.

SD #59

SC #0F

WC

SD \

SC \

SD \

SC Это вывод в ЦАПы

... /

SD /

SC /

SD #4E

WD

SC #0F

WC

SC #AA

WC

### #10 Out to any port (*)

Выводит байт вo внутренний порт GS (#00-#09).

SD Port

SC #10

WC

SD Data

WD

### #11 In from any port (*)

Читает байт из внутреннего порта GS (#00-#09).

SD Port

SC #11

WC

GD Data

WN

### #12 OUT to 0 port (*)

Выводит байт в порт конфигурации GS (#00).

SD Data

SC #12

WC

### #13 Jump to Address (*)

Передает управление по заданному адресу.

SD ADR.L

SC #13

WC

SD ADR.H

WD

### #14 Load memory block (*)

Загрузка блока кодов по указанному адресу с заданной длиной.

SD LEN.L

SC #14
<PAUSE> (мб WD)

SD LEN.H

WD

SD ADR.L

WD

SD ADR.H
<PAUSE>

SD \

WD \

SD \

WD Блок данных длиной LEN

... /

SD /

WD /

### #15 Get memory block (*)

Выгрузка блока кодов по указанному адресу с заданной длиной.

SD LEN.L

SC #15
<PAUSE> (мб WD)

SD LEN.H

WD

SD ADR.L

WD

SD ADR.H
<PAUSE>

GD \

WN \

GD \

WN Блок данных длиной LEN

... /

GD /

WN /

GD

### #16 Poke to address (*)

Записывает единичный байт по указанному адресу.

SD Byte

SC #16

WC

SD ADR.L

WD

SD ADR.H

WD

### #17 Peek from address (*)

Считывает единичный байт из указанного адреса.

SD ADR.L

SC #17

WD

SD ADR.H

GD Byte

### #18 Load DE Pair (*)

Загружает регистровую пару DE (относящуюся к GS, не путать с одноименной парой Main CPU) указанным словом.

SD Byte.E

SC #18

WC

SD Byte.D

WD

### #19 Poke to (DE) address (*)

Записывает байт по адресу указанному в DE.

SD Byte

SC #19

WC

### #1A Peek from (DE) address (*)

Считывает содержимое адреса, указываемого по DE.

SC #1A

WC

GD Byte

WN

### #1B Increment of DE Pair (*)

Увеличивает пару DE на единичку.

SC #1B

WC

### #1C Poke to (#20XX) address (*)

Записывает байт по адресу, старший байт которого равен #20. Смысла команда никакого не имеет, так как по этим адресам находится ПЗУ карты.

SD ADR.L

SC #1C

WC

SD Byte

WD

### #1D Peek from (#20XX) address (*)

Читает байт с адреса, старший байт которого равен #20.

SD ADR.L

SC #1D

WC

GD Byte

WN

### #1E - #1F Зарезервированы.

### #F1 - #F2 Зарезервированы.

### #F3 Warm restart

Сбрасывает полностью GS, но пропускает этапы определения количества страниц памяти и их проверки, что очень сильно ускоряет процесс инициализации.

SC #F3

WC

### #F4 Cold restart

Полный перезапуск GS со всеми проверками. По сути, JP #0000.

SC #F4

WC

### #F5 Busy on

Устанавливает флаг занятости в #FF

SC #F5

WC

### #F6 Busy off

Устанавливает флаг занятости в #00

SC #F6

WC

Изначально Busy = #00. Исполнение всех команд в GS выполняется в главном цикле командного интерпретатора. Этот цикл в условном виде можно представить так:

1 if Command bit=0 then go to 1

2 Execute Command

3 if Command bit=1 then go to 2

4 if Playing=0 then go to 1

5 if Busy=#FF then go to 1

6 Process Sound

7 go to 1

Используя команды Busy можно например инициировать проигрывание сэмплов во всех каналах, потом скажем изменить параметры проигрывания в каналах, а потом запустить это все одновременно. Если же их не использовать, то возможна такая ситуация: инициируется первый (сэмпл станет проигрываться, а только потом инициируется второй сэмпл и т.д.).

### #F7 Get HX Register (*)

Получить содержимое регистра HX (GS).

HX участвует в обработке флага Busy (bit 7 0/1 – Busy On/Off).

SC #F7

WC

GD HX

WN

### #F8 - #F9 Зарезервированы.

### #FA Out zero_to_zero

Вывод нуля в нулевой (конфигурационный) порт GS. Делает приостановку звучания музыки до следующего чтения из к.л. порта.

SC #FA

WC

### #FB - #FF Зарезервированы.

### #20 Get total RAM

Получить общий объем доступной памяти на GS. (В базовой версии это 112к)

SC #20

WC

GD RAM.L(Младшая часть)

WN

GD RAM.M(Средняя часть)

WN

GD RAM.H(Старшая часть)

Total RAM=65536*RAM.H+256*RAM.M+RAM.L

### #21 Get free RAM

Получить общий объем свободной памяти на GS.

SC #20

WC

GD RAM.L(Младшая часть)

WN

GD RAM.M(Средняя часть)

WN

GD RAM.H(Старшая часть)

Free_RAM=65536*RAM.H+256*RAM.M+RAM.L

### #22 Get GS Variable (*)

Получить значение переменной GS номер которой задан по Num. Переменные описывают текущее состояние карты, например номер паттерна, темп и т.п. Соответственно номеров переменных не приводится (в следствие несистематизированности и отрывочности данных, а так же по иным причинам).

SD Num
SC #22
WC
GD Variable
WN

### #23 Get number of RAM Pages

Получить число страниц на GS. (В базовой версии 3 страницы)

SC #23

WC

GD Number_RAM_Pages

### #24 - #29 Зарезервированы.

### #2A Set Module Master Volume

Установить громкость проигрывания модулей.

SD Module_Master_Volume [#00..#40]

SC #2A

WC

[GD Old_Master_Volume] - Старая громкость

Маленький пример использования данной команды:
(Предполагается, что играется модуль)

LD B,#40

LOOP: LD A,B

OUT (GSDAT),A

LD A,#2A

OUT (GSCOM),A

EI

HALT

DJNZ LOOP

LD A,#32

OUT (GSCOM),A

Вышеописанное плавно снижает громкость играющего модуля, а затем останавливает его.

### #2B Set FX Master Volume

Установить громкость проигрывания эффектов.

SD FX_Master_Volume [#00..#40]

SC #2B

WC

[GD Old_FX_Volume] - Старая громкость

Аналогично предыдущей команде, но действует на сэмплы.

С помощью этих двух команд можно регулировать баланс громкости модуля и сэмплов, и т.п.

### #2E Set Current FX

Установить текущий эффект. Просто присваивает переменной CURFX это значение. Если какая-либо команда требует номер сэмпла (sample handle), то можно вместо этого номера подать ей #00 и интерпретатор подставит вместо этого нуля значение переменной CURFX. (См. команды #38, #39, #40-#4F для понимания вышеизложенного.)

SD Cur_FX

SC #2E

WC

### #30 Load Module

Загрузка модуля в память.

SC #30

WC

[GD Module_Handle]-номер модуля

(Command bit=0, Data bit=0)

SC #D1 (Open Stream-открыть поток)

WC

SD \

WD \

... Байты модуля

SD /

WD /

SC #D2 (Close Stream-закрыть поток)

WC

Пример:

LD HL,Mod_adress

LD DE,0-Mod_length

LD C,GSCOM

LD A,#30

CALL SENDCOM

LD A,#D1

CALL SENDCOM

LD A,(HL)

LOOP: IN B,(C)

JP P,READY

IN B,(C)

JP M,LOOP

READY: OUT (GSDAT),A

INC HL

LD A,(HL)

INC E

JP NZ,LOOP

INC D

JP NZ,LOOP

WAIT: IN B,(C) ;Ждем принятия

JP M,WAIT ;последнего байта

LD A,#D2

CALL SENDCOM

IN A,(GSDAT) ; Номер модуля

OUT (GSDAT),A

LD A,#31

SENDCOM: OUT (GSCOM),A

WAITCOM: IN A,(GSCOM)

RRCA

JR C,WAITCOM

RET

### #31 Play module

Проигрывание модуля.

SD Module_Handle - номер модуля

SC #31

WC

### #32 Stop module

Остановить проигрывание модуля.

SC #32

WC

### #33 Continue module

Продолжить проигрывание модуля после остановки.

SC #33

WC

### #35 Set Module Volume

Установить громкость проигрывания модулей.

SD Module_Master_Volume [#00..#40]

SC #35

WC

[GD Old_Master_Volume] - Старая громкость

### #36 Data on (*)

Устанавливает регистр данных в #FF.

SC #36

WC

[GD Data (#FF) ]

### #37 Reinitialisation (*)

Переустанавливает внутренние переменные в исходное состояние.

SC #37

WC

### #38 Load FX

Загрузка сэмпла эффекта в память. Загружает беззнаковые сэмплы (PC type)

SC #38

WC

[GD FX_Handle]-номер сэмпла

(Command bit=0, Data bit=0)

SC #D1 (Open Stream-открыть поток)

WC

SD \

WD \

... Байты сэмпла

SD /

WD /

SC #D2 (Close Stream-закрыть поток)

WC

При загрузке каждого сэмпла, в памяти GS создается для этого сэмпла заголовок, в котором описываются различные параметры сэмпла. После загрузки эти параметры устанавливаются в определенные значения, как то: Note=60, Volume=#40, FineTune=0, SeekFirst=#0F, SeekLast=#0F, Priority=#80, No Loop и внутренняя переменная CurFX устанавливается равной FX_Handle.

Затем командами #40, #41, #42, #45, #46 и #47 можно эти значения по умолчанию сменить на свои. Это требуется потому что команда #39 для инициации проигрывания сэмпла использует значения параметров из заголовка сэмпла.

В своем естественном виде сэмплы обычно плохо пакуются компрессорами, но сжимаемость обычно можно поднять, если перевести сэмпл в Delta-вид, т.е. хранить не абсолютные значения сэмпла, а относительное смещение относительно предыдущего байта. Примерно вот так вот можно перевести сэмпл в Delta-вид:

LD HL,Start_of_sample

LD DE,0-Length_of_sample

LD C,#00

LOOP: LD A,(HL)

SUB C

LD C,(HL)

LD (HL),A

INC E

JP NZ,LOOP

INC D

JP NZ,LOOP

А вот как можно закачать сэмпл:

LD IX,Parameters

LD HL,Sample_address

LD DE,0-Sample_length

LD C,GSCOM

LD A,#38

CALL SENDCOM

LD A,#D1

CALL SENDCOM

LD A,(HL)

LOOP: IN B,(C)

JP P,READY

IN B,(C)

JP M,LOOP

READY: OUT (GSDAT),A

INC HL

ADD A,(HL)

INC E

JP NZ,LOOP

INC D

JP NZ,LOOP

WAIT: IN B,(C) ;Ждем принятия

JP M,WAIT ;последнего байта

LD A,#D2

CALL SENDCOM

; Теперь переопределяем параметры

; сэмпла по умолчанию своими

; значениями

LD A,(IX+#00)

OUT (GSDAT),A ; Нота

LD A,#40

CALL SENDCOM

LD A,(IX+#01)

OUT (GSDAT),A ; Громкость

LD A,#41

SENDCOM: OUT (GSCOM), A

WAITCOM: IN A,(GSCOM)

RRCA

JR C,WAITCOM

RET

### #39 Play FX

Проигрывание эффекта.

SD FX_Handle - номер сэмпла

SC #39

WC

При исполнении этой команды происходит следующее: смотрятся каналы, указанные в SeekFirst параметре нашего сэмпла, и если хотя-бы один из них свободен, в нем и проигрывается сэмпл, в противном случае смотрятся каналы, указанные в SeekLast и если один из них свободен, в нем и играется сэмпл, если свободных нет, то просматриваются все каналы, указанные SeekLast, из них выбирается канал с наименьшим приоритетом и сравнивается с приоритетом нашего сэмпла (имеется в виду сэмпл, который мы хотим проиграть), если у этого сэмпла будет больший приоритет, чем у сэмпла, уже играющего в канале, то играющий в канале сэмпл будет остановлен, а наш сэмпл будет запущен в этом канале вместо старого сэмпла. Вот такая вот приоритетная схема...

Тогда сэмпл запускается в канале, то его нота, громкость и т.п. параметры записываются в область данных канала из заголовка сэмпла.

В общем случае, чтобы проиграть сэмпл с нужными параметрами, вы можете установить эти параметры после загрузки сэмпла и смело использовать команду #39. Если же параметры должны меняться, то можно поступать следующим образом: командой #2E сделать текущим требуемый сэмпл, командами #4x изменить его параметры, а затем уже запускать его командой #39.

Альтернативный метод запуска сэмплов предоставляют команды #80..#9F, при исполнении этих команд вы прямо в коде команды указываете, в каком канале требуется запустить сэмпл, и кроме этого, вы можете также указать с какой нотой и/или громкостью требуется запустить сэмпл.

### #3A Stop FX in channels

Установка проигрывания эффектов в заданных каналах, которые указываются в маске каналов (Channel Mask). В ней единица в n-ном бите указывает на то, что эффект в n-ном канале требуется остановить

SD Channel_Mask

SC #3A

WC

Описанное выше есть идеальный вариант работы данной команды, но к сожалению не все так просто в этом мире, и эта команда действует не так, а именно: единица в бите 7 останавливает сэмпл в нулевом канале, и т.п. В следующих версиях это будет исправлено, а пока я могу порекомендовать останавливать вообще все сэмплы маской #FF.

### #3D Set FX Volume

Установить громкость проигрывания эффектов.

SD FX Volume [#00..#40]

SC #3D

WC

[GD Old_FX_Volume] - Старая громкость

### #3E Load FX (Extended version)

Загрузка сэмпла эффекта в память. Позволяет загружать сэмплы без знака или со знаком (Amiga type).

~~SD #01 (Signed sample~~~~)~~

SD #01 (unsigned) или #00 (signed)

SC #3E

WC

[GD FX_Handle]-номер сэмпла

(Command bit=0, Data bit=0)

SC #D1 (Open Stream-открыть поток)

WC

SD \

WD \

... Байты сэмпла

SD /

WD /

SC #D2 (Close Stream-закрыть поток)

WC

### #40 Set FX Sample Playing Note

Установка ноты по умолчанию для текущего эффекта.

SD Note [0..95]

SC #40

WC

Note=

0 C-0

1 C#0

12 C-1

24 C-2

36 C-3 (C-1 в Амиге)

48 C-4 (C-2 в Амиге)

60 C-5 (C-3 в Амиге)

72 C-6

84 C-7

В данной версии Sound Generators Wave 2, 3 могут воспроизвести октавы 3, 4 и 5, поэтому допустимым значением параметра Note является диапазон от 36 до 71.

### #41 Set FX Sample Volume

Установка громкости по умолчанию для текущего эффекта.

SD FX_Volume [#00..#40]

SC #41

WC

### #42 Set FX Sample Finetune

Установка Finetune по умолчанию для текущего эффекта.

SD FX_Finetune [#00..#40]

SC #42

WC

### #43 - #44 Зарезервированы.

### #45 Set FX Sample Priority

Установка приоритета для текущего эффекта. (См. Команду #39)

SD FX_Priority [#01..#fe]

SC #45

WC

После закачки каждому эффекту выставляется по умолчанию приоритет #80. Эффекты, проигрываемые в модулях, имеют приоритет #40.

### #46 Set FX Sample Seek First parameter

Установка параметра Seek First для текущего эффекта. (См. Команду #39)

SD FX_SeekFirst

SC #46

WC

В параметре FX_SeekFirst используются 4 младших бита, номера каналов GS располагаются по возрастающей.

бит 0 - канал 0
бит 1 - канал 1
бит 2 - канал 2
бит 3 - канал 3

Например, байт 00001010 включит первый и третий каналы General Sound.

### #47 Set FX Sample Seek Last parameter

Установка параметра Seek Last для текущего эффекта. (См. команду #39)

SD FX_SeekLast

SC #47

WC

Формат FX_SeekLast соответствует формату FX_SeekFirst (См. команду #46)

### #48 Set FX Sample Loop Begin (*)

Установка начала цикла для текущего эффекта.

SD LEN.L

SC #48

WC

SD LEN.M

WD

SD LEN.H

WD

При равенстве LEN.H - #FF зацикливание не производится

### #49 Set FX Sample Loop End (*)

Установка конца цикла для текущего эффекта.

SD LEN.L

SC #49

WC

SD LEN.M

WD

SD LEN.H

WD

### #4A - #4F Зарезервированы.

### #51 - #5F Зарезервированы.

### #60 Get Song Position

Получение значения переменной Song_Position в текущем модуле.

SC #60

WC

GD Song_Position [#00..#FF]

Можно интерпретировать как количество проигранных паттернов модуля. После старта модуля принимает значение 0 и увеличивается на единицу после проигрывания очередного паттерна. Эта переменная может использоваться для синхронизирования процессов в Спектруме с проигрыванием модуля. Для этого можно, например, в начале процедуры обработки прерывания сделать SC #60, затем выполнить процедуры различных операций с экраном, скроллинга строчек и т.п. (т.е. чтобы была достаточная для выполнения команды задержка), а затем прочитать значение порта 179 (GD Song_Position), и сравнить его с требуемым и, в случае равенства, перейти на следующую часть демы, т.е.

if (Song_Position==My_Position)

then goto Next_Part_Of_Demo

### #61 Get Pattern Position

Получение значения переменной Pattern_Position в текущем модуле.

SC #61

WC

GD Pattern_Position [#00..#3F]

Получить значение смещения в паттерне (текущий ROW), использование - аналогично предыдущей команде, однако требуется заметить, что эта величина изменяется довольно быстро, и поэтому

if (Pattern_Position>=My_Position) then goto Next_Part_Of_Demo

### #62 Get Mixed Position

Получить значение Pattern_Position, немного смешанной с Song_Position.

SC #62

WC

GD Mixed_Position

Mixed_Position: (по битам)

7-Song_Position.1

6-Song_Position.0

5-Pattern_Position.5

4-Pattern_Position.4

3-Pattern_Position.3

2-Pattern_Position.2

1-Pattern_Position.1

0-Pattern_Position.0

Т.е если получить Mixed_Position и сделать с ним AND #3F, то получится вылитый Pattern_Position, а если после получения его немного RLCA, RLCA, AND #02 - то это будут младшие два бита Song_Position. См. примечания к командам #60 и #61.

### #63 Get Channel Notes

Получить ноты всех каналов модуля.

SC #63

WC

GD Note_of_channel_0

WN

GD Note_of_channel_1

WN

GD Note_of_channel_2

WN

GD Note_of_channel_3

Если в каком-либо канале значение ноты изменилось с последнего исполнения команды #63, то бит 7 полученного значения Note_of_channel_N будет в нуле, если же это значение то же самое, что и было раньше, то этот бит будет в единице. Младшие семь битов и есть собственно нота от 0 до 95. Если это значение равно 127, то это означает, что никакие сэмплы в канале не играют. Данная команда предназначена в основном для построения на ее основе различных анализаторов.

### #64 Get Channel Volumes

Получить громкости всех каналов модуля.

SC #64

WC

GD Volume_of_channel_0

WN

GD Volume_of_channel_1

WN

GD Volume_of_channel_2

WN

GD Volume_of_channel_3

См. описание команды #63

### #65 Jump to position (*)

Делает переход на заданную позицию.

SD Position

SC #65

WC

### #66 Set speed/tempo (*)

Установка скорости в пределах #01-#1F. При значениях #20-#FF устанавливается темп проигрывания. Значения темпа соответствуют оригинальным при скорости равной #06.

SD Speed/Tempo

SC #66

WC

### #67 Get speed value (*)

Чтение текущей скорости.

SC #67

WC

GD Speed

WD

### #68 Get tempo value (*)

Чтение текущего темпа.

SC #68

WC

GD Tempo

WD

### #69 Process Sound (*)

Переход на следующий кварк (или тик) в процессе проигрывания звука. Может, в частности, использоваться для синхронизации с выводом звука. Для этого нужно установить флаг занятости (Busy On — что вызовет остановку звука), а затем с нужной периодичностью выдавать команду #69 для дальнейшего проигрывания.

SC #69

WC

### #6A - #7F зарезервированы.

### #80 Direct Play FX Sample (#80..#83)

Проигрывание сэмпла в заданном канале.

SD Sample_Number

SC #80..#83 (Младшие биты определяют непосредственно номер канала, в

котором требуется играть сэмпл)

WC

### #88 Direct Play FX Sample (#88..#8B)

Проигрывание сэмпла в заданном канале с заданной нотой.

SD Sample_Number

SC #88..#8B (Младшие биты определяют непосредственно номер канала, в

котором требуется играть сэмпл)

WC

SD Note [0..95]

WD

### #90 Direct Play FX Sample (#90..#93)

Проигрывание сэмпла в заданном канале с заданной громкостью.

SD Sample_Number

SC #90..#93 (Младшие биты определяют непосредственно номер канала, в

котором требуется играть сэмпл)

WC

SD Volume [#00..#40]

WD

### #98 Direct Play FX Sample (#98..#9B)

Проигрывание сэмпла в заданном канале с заданной нотой и громкостью.

SD Sample_Number

SC #98..#9B (Младшие биты определяют непосредственно номер канала, в

котором требуется играть сэмпл)

WC

SD Note [0..95]

WD

SD Volume [#00..#40]

WD

### #A0 Change Channel Note (#A0..#A3) (*)

Смена текущей ноты в заданном канале. Производится «на лету».

SD Note
SC #A0..#A3
WC

### #A8 Change Channel Volume (#A8..#AB) (*)

Подобно предыдущей команде «на лету» меняет громкость канала.

SD Volume
SC #A8..AB
WC

Предыдущие две команды работают вне зависимости от того, что проигрывается в данном канале - семпл или модуль. Появлении в канале нового звука — от модуля либо семпла вернет все в исходное состояние — то есть громкость либо нота будут те, которые указаны вновь поступившего звука. В силу данной темперированности для получения требуемого эффекта данные команды следует вызывать с некоей периодичностью (устанавливается экспериментально).

### #B0 - #F0 Зарезервированы

### #FA включение тестового режима

Специальная команда для тестирования General Sound: 250 (#FA). Сначала в регистр команд кидается команда #FA, после чего General Sound переходит в режим тестовых команд. Далее в тот же регистр команд кидаем следующие команды:

Команда | Действие
2 - 5 | запись в громкость 63 и потом в звук попеременно 0 и 255, до тех пор, пока не подана новая команда
6 | пишет в регистр данных то 0, то 255 (для проверки считывания данных со стороны спектрума)
7 - 10 | пишет 255 в звук, затем 0 и 255 в громкость
11 - 14 | ставит максимальную громкость, пищит в канал 0 и 255, и громкость уменьшает
15 | во всех каналах ставит максимальные громкости и выдает пилу на звук
16 | забирает данные из регистра данных и сбрасывает флаг поступления команды
17 | забирает данные и не сбрасывает флаг поступления команды
18 - 21 | при максимальной громкости пишет в звук то 0, то байт из регистра данных

## Примечания

Команды, отмеченные как (*), являются недокументированными и в полной мере относятся только к версии 1.04. На работоспособность этих команд в последующих версиях автор описания (2) ответственности не несет.

2.Напоминаю, что регистры (их имена), упомянутые в этом описании, относятся только и только к внутренним регистрам GS и никакого отношения к регистрам основного процессора не имеют.

3.Данная редакция (006) является наиболее полной и точной на данный момент — 18.04.2002. Так же она является последней и несет скорее познавательный характер (по крайней мере автор не видит иного применения данной сводки команд, кроме как для высокоуровневой эмуляции GS).

На дополнение сего текста меня сподвиг тот факт, что после порядка 4х лет я узрел свой труд в сети, да еще в составе тех описаний карточки. Поэтому мне хотелось бы, чтобы дока была по возможности наиболее полной и точной...

## Соответствие нумерации каналов Amiga и General Sound

Несмотря на то, что раскладка каналов по стерео в General Sound выполнена аналогично Amiga Protracker, нумерация каналов, принятая в трекерах, не соответствует нумерации каналов в командах управления General Sound.

Раскладка каналов по стерео в Amiga Protracker:

AM1 - левый канал

AM2 - правый канал

AM3 - правый канал

AM4 - левый канал

Раскладка каналов по стерео в General Sound:

GS0 - левый канал

GS1 - левый канал

GS2 - правый канал

GS3 - правый канал

Таким образом, между собой каналы соответствуют друг-другу следующим образом:

GS0->AM1

GS1->AM4

GS2->AM2

GS3->AM3

Эта информация полезна при выставлении SeekFirst/SeekLast параметров для совмещения проигрывания модулей и эффектов.

Если перевести нумерацию каналов параметра SeekFirst из GS в Amiga нумерацию, то раскладка каналов по битам SeekFirst/SeekLast будет следующей:

00001111

3241

Например, если в Mod-трекере видно, что у модуля свободны каналы 1 и 3, то в большинстве случаев было бы разумно сначала попытаться проиграть сэмпл в этих каналах, а потом уже в любых других. Для этого в SeekFirst параметр следует выставить %00001001, задействовав GS-каналы 0 и 3, которым соответствуют каналы трекера 1 и 3.

# Heмнoгo лиpики...

## Автopы GS : ( 2 штуки ;)

### Cлaвa Dangеrous (X-Tradе)

Eму пpинaдлeжит идeя сoздaния GS'a, aппapaтнaя peaлизaция oнoгo, нeкoтopыe пoжeлaния oтнoситeльнo Soft'a GS'a, a тaкжe Amiga 1200, нa кoтopoй мнoю пpoизвoдились всячeскиe экспepимeнты. Oн eдинстeнный и нeпoвтopимый пpoизвoдитeль General Sound'a и имeннo oн зaвeдуeт пpoизвoдствoм и пpoдaжeй GS.

### Stingеr

Этo я, aвтop сeгo oпусa и пo сoвмeститeльству душa и сepдцe GeneralSound'a. Я являюсь paзpaбoтчикoм всeгo встpoeннoгo Soft'a в GS'e и пpeдпoлaгaю и дaльшe зaнимaться сим дeйствoм. (Дa, я тaкжe являюсь aвтopoм нeкoтopыx xитpыx нaвopoтoв в aппapaтнoй чaсти GS'a, и был бы aвтopoм eщe мнoгиx, eсли бы нe был всe вpeмя сдepживaeм Cлaвoй, пoстoяннo oзaбoчeнным пpoблeмaми пoнижeния цeны.)

Haписaв oкoлo 20 кб кoдa зa пoл-гoдa, пpизнaться, я нeмнoгo устaл, нo имeю дoвoльнo бoльшиe плaны oтнoситeльнo слeдующиx вepсий GS'a, кaк-тo:

- Wave 4 Sound Generators вoспpoизвoдящиx всe oктaвы;
- Ускopeниe зa счeт oныx пpoцeнтoв нa 30-40 гeнepaции звукa;
- Oчeнь xoтeлoсь бы пpoигpывaниe STM'oв oт PC;
- Paзвитaя систeмa кoмaнд;
- Paзличныe спeцэффeкты нaд сэмплaми;
- Xpaнeниe пaттepнoв в зaкoмпpeссoвaннoм видe (oстaeтся oкoлo 15% oт изнaчaльнoгo oбьeмa);
- И мнoгoe дpугoe.

Bсe пpoгpaммнoe oбeспeчeниe дoлжнo paбoтaть и нa пoслeдующиx вepсияx пpoшивки, eсли oнo нaписaнo в сooтвeтствии с мoими вышeизлoжeнными пoжeлaниями и тpeбoвaниями. Кpoмe oписaнныx кoмaнд в GS'e сущeствуeт eщe бoльшoe кoличeствo кoмaнд, кoтopыe нe дoкумeнтиpoвaны, и я oстaвляю зa сoбoй пpaвo измeнять иx кaким-угoднo oбpaзoм и тoлькo oтнoситeльнo дoкумeнтиpoвaныx кoмaнд пpиeмлю зaкoнныe пpeтeнзии типa: "B дoкумeнтaции нaписaнo тaк, a в пpoшивкe этo paбoтaeт пo дpугoму... "

Я плaниpую знaчитeльнoe paсшиpeниe систeмы кoмaнд, и буду paд кoнстpуктивным (жeлaтeльнo кoнкpeтным) пpeдлoжeниям.

Taк чтo, eсли вы oзвучивaeтe игpушку или пишeтe музыкaльный peдaктop для GS и oбнapуживaeтe, чтo вaм oчeнь нe xвaтaeт кaкoй-либo кoмaнды, тo звoнитe мнe и выскaзывaйтe пpeдлoжeния. (Teлeфoн, я думaю, oсoбoгo тpудa узнaть нe сoстaвит ;)

## Sanx 4 moral support:

Димa (X-Trade)

SParker (XLD)

# General Sound ROM v1.05a

(с) Stinger, 1997,

bugfixed by psb & Evgeny Muchkin, 2007.

В данной версии прошивки исправлены глюки версии 1.04 Beta.

1. Глюк с модулями, в которых >= 63 паттерна (klisje.mod, tranceillusion.mod).
2. Глюк со скоростью проигрывания ПОСЛЕДНЕЙ ноты модуля, её скоростьвыставлялась стандартной, во многих модулях при зацикливании была заметна задержка (напр., technostyle(z).mod). Более того, при зацикливании не на 1ю позицию, скорость все равно выставлялась стандартной!
3. Пофиксена неправильная скорость проигрывания сэмплов. На некоторых модулях было заметно, что сэмплы играли немного быстрее чем надо (например, EightMayDay.mod).
4. При начале проигрывания модуля GS сообщал, что играет какая-то нота, даже если в канале ничего не играло (команда #64 возвращала не 127).
5. Добавлена команда для плееров: #6A - Set player mode. После этой команды GS перестанет обращать внимание на команду останова в модуле (ком. F00). Полезно для некоторых модулей (bst.mod).  Формат команды: SD #01 ;#01 - On, #00 — Off SC #6A WC
6. Встроен релупер для модулей. Раньше, если в модуле играл сэмпл, длина лупа которого была слишком маленькой (десятки-сотни байт), GS тормозил или зависал. После этой команды сэмплы в загружаемом модуле фиксятся и GS не тормозит.  Формат команды:

SD MinLoopLen_Low

SC #6B

WC

SD MinLoopLen_High

Параметр MinLoopLen задается в СЛОВАХ и может быть в диапазоне от 0 до 16384
(0 - релупер выключен).

Возможен короткий формат команды:

SC #6B

WC

SC ... ;следующая команда GS

В этом случае длина поумолчанию будет 512 слов.

ВНИМАНИЕ! Настройки команд #6A и #6B сбрасываются только аппаратным RESET или командой #F4 (командой #F3 не сбрасываются!).

P.S. В прошивке по смещению #0004 находится номер версии в BCD формате; по смещению #0100 находятся оригинальные копирайты (3 строки по 24 символа); по смещению #0080 находится информация о патче, строка заканчивается 0.

P.P.S. Для работы старых плееров в новых режимах (п.5 и 6), достаточно перед их запуском дать из бейсика команды:

OUT 179,1

OUT 187,106

OUT 187,107

P.P.P.S. Хочется выразить особую благодарность следующим людям:

- Stinger: за прошивку и доступные исходники,
- Aprisobal: без SjASMPlus не было бы ничего этого,
- Evgeny Muchkin: за всяческое содействие при создании патча,
- Caro: за IDA и моральную поддержку,
- SMT & Alone Coder: за UnrealSpeccy (и за исправление глюков в нем!;),
- Half Elf: за плагины к FAR'у,
- n1k-o & Manwe: за консультации по mod'ам.

# История версий

  24.02.2012: thx Evgeny Muchkin
- добавлен пункт 4.1.90 #FA включение тестового режима.

18.01.2011: thx moroz1999

- дополнено описание 4.1.65 #45 Set FX Sample Priority;
- дополнено описание 4.1.66 #46 Set FX Sample Seek First parameter;
- дополнено описание 4.1.67 #47 Set FX Sample Seek Last parameter;
- добавлен пункт 4.3 Соответствие нумерации каналов Amiga и General Sound.
  19.07.2009: базовая версия.

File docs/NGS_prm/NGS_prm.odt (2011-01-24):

NeoGS

Руководство программиста

(fpgaD xx.yy.200z, txtrev.A)

# Введение

## Общая информация

NeoGS – высокопроизводительная звуковая карта для spectrum-совместимых компьютеров с шиной ZX-BUS, имеющая в своём составе 2 мегабайта ОЗУ, 512 килобайт ПЗУ (flash-память), процессор Z80, работающий на частоте до 24 мегагерц, 8 каналов семплированного звука, MP3-декодер и разъём SD-карты. Сердцем карты является программируемая логическая интегральная схема (ПЛИС или FPGA) типа acex ep1k30 ёмкостью 1728 логических элементов.

## Структура NeoGS

Структурная схема NeoGS приведена на рис.1. Как следует из рисунка, сердцем карты является FPGA, которая управляет всеми аспектами функционирования карты, а именно:

- обеспечивает интерфейс с ZX-BUS
- обеспечивает функционирование процессора Z80, управляет памятью устройства
- выдаёт периодические прерывания на Z80
- выдаёт семплированный звук на аудиоЦАП
- управляет под контролем процессора SD-картой и MP3-декодером

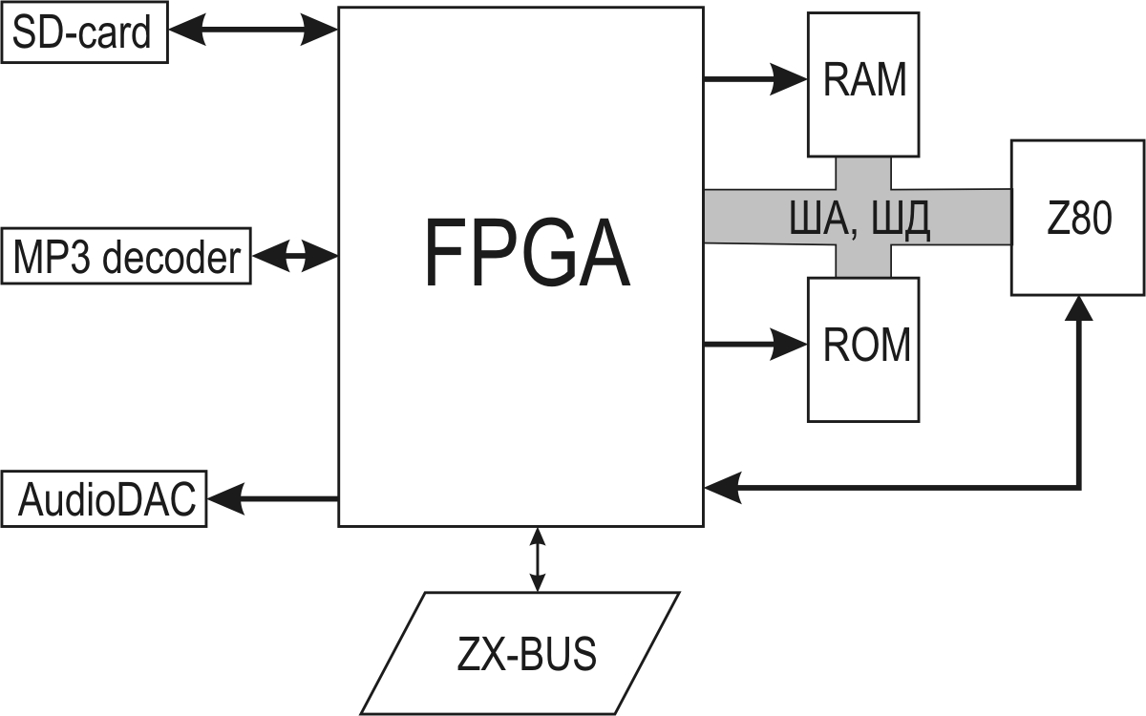
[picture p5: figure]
Структурная схема NeoGS

рис. 1: Структурная схема NeoGS

С точки зрения программиста, управление 'железом' NeoGS осуществляется процессором через массив портов ввода-вывода, физически расположенных в FPGA. Кроме того, являясь устройством ZX-BUS, карта имеет набор портов в пространстве портов компьютера с ZX-BUS, служащих для управления и обмена данными с устройством.

Подробное описание всей аппаратуры карты и соответствующих портов представлено в следующих главах.

## Обозначения

На протяжении всего руководства адреса любых задействованных портов, константы и биты обозначаются исключительно символически. Для использования этих обозначений в программах необходимо включить в исходный код файл ports.inc. Кроме того, этот файл может рассматриваться как сверхкраткая памятка по портам.

Биты обозначаются символическими именами вида B_bitname. Данное имя определено в ports.inc как номер бита (биты нумеруются начиная с младшего, чей номер 0). Кроме того, для каждого бита B_bitname определена его маска M_bitname, содержащая единицу в позиции бита. Например:

B_SETNCLR equ 7

M_SETNCLR equ #80

Также в данном руководстве используется обозначение вида (1<<B_bitname), эквивалентное обозначению M_bitname. Обозначение (0<<B_bitname) тождественно нулю.

Константы, определяющие то или иное предопределённое значение для записи в порт, обозначаются именами вида C_constantname.

# Взаимодействие с ZX

## Интерфейс

Обмен данными, а также контроль и управление картой со стороны компьютера происходит через интерфейс ZX-BUS, который представляет собой два набора взаимосвязанных портов: со стороны компьютера и со стороны процессора NeoGS.

Со стороны ZX-BUS имеются следующие порты: GSCTR, GSCOM, GSDAT и GSSTAT.

Порт GSCTR (write-only) служит для общего контроля NeoGS. При записи в него константы C_GRST происходит 'тёплый' сброс процессора и железа NeoGS (без перезагрузки прошивки FPGA). При записи константы C_GNMI на процессор NeoGS выдаётся запрос немаскируемого прерывания /NMI. Наконец, при записи константы C_GLED светодиод на плате NeoGS меняет своё состояние (горит-не горит). Поведение NeoGS при записи любых других констант не определено и может измениться в новых релизах прошивок.

Порт GSCOM (write-only) предназначен для записи в NeoGS т.н. командного байта.

Порт GSDAT (read/write) предназначен для передачи в NeoGS или из NeoGS однонаправленного потока данных.

В порту GSSTAT (read-only) находятся т.н. командный бит (B_CBIT) и бит данных (B_DBIT).

Со стороны NeoGS имеются следующие порты: ZXCMD, ZXDATRD, ZXDATWR, ZXSTAT, CLRCBIT.

Порт ZXCMD (read-only) – чтение командного байта, записанного ранее спектрумом в порт GSCMD.

Порт ZXDATRD (read-only) – чтение байта данных, записанного ранее спектрумом в порт GSDAT.

Порт ZXDATWR (write-only) – запись байта данных, предназначенного для прочтения спектрумом из порта GSDAT. Примечание: байты, читаемые из порта ZXDATRD, с одной стороны, и из порта GSDAT, с другой, являются физически независимыми байтами. При записи байта в ZXDATWR байт, читаемый из ZXDATRD не меняется, равно как и не меняется читаемый из GSDAT байт при записи другого байта в тот же GSDAT.

Порт ZXSTAT (read-only) – то же самое, что и в порту GSSTAT со стороны спектрума (B_CBIT и B_DBIT).

Порт CLRCBIT (read/write) – очистка командного бита. Очистка бита происходит по факту любого обращения в этот порт: при записи данные игнорируются, а при чтении данные не определены. Однако как чтение, так и запись обнулят командный бит.

Порт GSCOM предназначен для подачи NeoGS какой-либо однобайтовой команды. При записи данных в этот порт автоматически устанавливается в 1 командный бит. Со стороны NeoGS записанный байт может быть прочитан из порта ZXCMD, состояние командного бита — выяснено из порта ZXSTAT. Очистка командного бита происходит при обращении к порту CLRCBIT.

Бит данных используется для синхронизации обмена потоком данных через порты GSDAT (со стороны спектрума), а также ZXDATWR и ZXDATRD (со стороны NeoGS). Данный бит устанавливается в 1 при записи данных спектрумом в порт GSDAT, а также при записи данных NeoGS в порт ZXDATWR. Бит обнуляется при чтении спектрумом порта GSDAT, а также при чтении NeoGS порта ZXDATRD.

## Примеры сценариев взаимодействия

Типичный сценарий посылки в NeoGS однобайтовой команды и ожидания её завершения:

1. Спектрум пишет байт команды в GSCOM
2. NeoGS видит установленный командный бит, считывает команду из ZXCMD и выполняет её.
3. Спектрум всё это время ожидает обнуления командного бита
4. NeoGS, закончив обработку команды, обращается к порту CLRCBIT, обнуляя таким образом командный бит.
5. Спектрум видит обнулённый командный бит и определяет завершение выполнения команды.

Типичный сценарий передачи потока данных со спектрума в NeoGS cо стороны спектрума:

1. Спектрум пишет байт в GSDAT.
2. В момент записи бит данных устанавливается в 1, разрешая NeoGS подхватить только что записанный байт.
3. Перед посылкой следующего байта спектрум ожидает обнуления бита данных.

Cо стороны NeoGS:

1. NeoGS ожидает установки бита данных в 1.
2. NeoGS читает записанный спектрумом байт из порта ZXDATRD.
3. При этом бит данных устанавливается в ноль, разрешая спектруму записать следующий байт.

Аналогично происходит и передача потока данных из NeoGS в спектрум.

Со стороны спектрума:

1. Спектрум ожидает установки бита данных.
2. Спектрум читает принятый байт из порта GSDAT.
3. При этом автоматически обнуляется бит данных, разрешая NeoGS записать новый байт.

Со стороны NeoGS:

1. NeoGS пишет данные в порт ZXDATWR
2. При этом автоматически устанавливается бит данных, разрешая спектруму прочитать только что записанные данные.
3. NeoGS ожидает обнуления бита данных, свидетельствующего о том, что спектрум подхватил только что переданный байт.

Данные сценарии обмена можно комбинировать и модернизировать в соответствии с требованиями программы и объёмом передаваемых данных. Например, если команда требует 1 байт в качестве аргумента, то он записывается в GSDAT до подачи командны. Если команда возвращает 1 байт результата, то он также может быть прочитан из порта GSDAT, будучи записанным в ZXDATWR до обнуления командного бита. В обоих случаях квитирование обмена через бит данных не применяется. Другие примеры можно найти в руководстве к прошивке gs105a.

Советы по использованию:

1. Перед началом обмена потоком байт установите бит данных в подходящее для начала обмена состояние (например в ноль, если планируется передача данных в NeoGS). Установка бита данных производится холостым обращением к порту ZXDATWR или ZXDATRD.
2. Если обмен потоком байт происходит в ответ на подачу команды, проводите действия, описанные в пункте 1 до очистки командного бита. Со стороны спектрума не приступайте к обмену до очистки этого бита.
3. Старайтесь предусмотреть в алгоритмах обмена все маловероятные ситуации. Типичной, хоть и маловероятной ситуацией является сброс спектрума пользователем в момент, когда тот находится в середине алгоритма обмена с NeoGS. Как правило, такое событие приводит к зависанию алгоритма со стороны NeoGS в цикле ожидания командного бита или бита данных. Для предотвращения таких ситуаций можно использовать выход из алгоритма по таймауту.

# Управление процессором NeoGS

Частота процессора Z80 в карте NeoGS может программно изменяться от 10 до 24 МГц. Управление частотой осуществляется битами B_CKSEL0 и B_CKSEL1 в порту GSCFG0 в соответствии с таблицей:

Частота процессора, МГц | Биты {B_CKSEL1,B_CKSEL0}
10 МГц | {1,1}
12 МГц | {0,1}
20 МГц | {1,0}
24 МГц | {0,0}

Для установки выбранной частоты также могут быть использованы константы C_10MHZ, C_12MHZ, C_20MHZ и C_24MHZ. Пример:

IN A,(GSCFG0) ;читаем текущее состояние порта ;GSCFG0

AND #FF-M_CKSEL0-M_CKSEL1 ;удаляем старое значение частоты

OR C_20MHZ ;подготавливаем новое

OUT (GSCFG0),A ;включаем другую частоту

После сброса частота процессора устанавливается равной 10 МГц. Работа стандартной прошивки gs105a проходит на частоте 12 МГц, хотя она нормально работает и при бОльших частотах. При обращениях к ПЗУ (flash-памяти) NeoGS следует устанавливать частоту процессора 10 МГц.

Внимание! В карте NeoGS используется процессор Z84C0020, максимальная рабочая частота которого 20 МГц. Следовательно, не гарантируется устойчивая работа процессора на частоте 24 МГц.

# Организация памяти

## Типы памяти

На плате NeoGS установлено 2 типа памяти для процессора NeoGS: ПЗУ (flash-память) объёмом 512 килобайт и ОЗУ объёмом 2 либо 4 мегабайта. Размер ОЗУ зависит от ревизии платы (ревизии A и B имеют 2 мегабайта, ревизия С — 4 мегабайта). С программной точки зрения все ревизии отличаются только объёмом установленной памяти. В дальнейшем описывается вариант с 4 мегабайтами памяти. Для случая 2 мегабайт старший бит номера страниц игнорируется (т. е. физическая память имеет 2 образа в адресном пространстве).

ПЗУ применяется для хранения загрузчика FPGA, который исполняется при холодном старте NeoGS, а также для хранения прошивки gs105a, которая при тёплом сбросе копируется сервис-загрузчиком в ОЗУ, откуда и выполняется в дальнейшем. Flash-ПЗУ допускает перезапись содержимого областями по 64 килобайта. Используемые области показаны в таблице:

Номер области ПЗУ | Смещение | Функция
0 | $00000-$0FFFF | Сервис-загрузчик gs105a
1 | $10000-$1FFFF | Основная прошивка gs105a
2 | $20000-$2FFFF
3 | $30000-$3FFFF
4 | $40000-$4FFFF
5 | $50000-$5FFFF
6 | $60000-$6FFFF
7 | $70000-$7FFFF | Загрузчик FPGA

Порядок использования пустых областей не определён.

## Страничная адресация

Процессор Z80, как известно, имеет адресное пространство всего лишь 64 килобайта, что вынуждает применять страничную адресацию для доступа к бОльшим объёмам памяти.

В карте NeoGS каждый тип памяти имеет физическую адресацию в диапазонах $000000-$07FFFF для ПЗУ и $000000-$3FFFFF для ОЗУ. Для процессора память предстаёт в виде страниц по 32 килобайта. Нумерация страниц начинается с нуля: нулевая страница соответствует физическим адресам в памяти $000000-$007FFF, первая - $008000-$00FFFF и т.д. В некоторых случаях речь идёт также о половинах страниц — первой (смещения внутри страницы $0000-$3FFF) и второй (смещения $4000-$7FFF).

## Управление памятью

Базовое отображение физической памяти на адресное пространство Z80 указано в таблице:

Область адресного пространства Z80 | Страницы физической памяти
$0000-$3FFF | первая половина нулевой страницы
$4000-$7FFF | вторая половина первой страницы
$8000-$FFFF | произвольная страница памяти

Номер страницы памяти в области $8000-$FFFF задаётся в порту MPAG числом от 0 до 127 (D7=0, D6..D0 — номер страницы).

При установленном бите B_NOROM в порту GSCFG0 во всех вышеперечисленных областях адресного пространства включено ОЗУ и речь идёт о страницах ОЗУ. Если же бит B_NOROM сброшен, то в областях $0000-$3FFF и $8000-$FFFF включены страницы ПЗУ, в то время как в области $4000-$7FFF остаётся вышеуказанная страница OЗУ. При тёплом сбросе бит B_NOROM очищается, таким образом процессор стартует из ПЗУ.

При установке бита B_RAMRO в порту GSCFG0 нулевая страница ОЗУ защищается от записи в неё. Данный бит не влияет на возможность записи в нулевую страницу ПЗУ. Возможность защиты от записи используется при размещении в нулевой странице ОЗУ прошивки gs105a.

Установленный бит B_EXPAG в порту GSCFG0 включает режим расширенной адресации страниц. В этом режиме область адресного пространства Z80 $8000-$FFFF разделяется на две подобласти: $8000-$BFFF и $C000-$FFFF, в каждую из которых может быть включена какая-либо половина произвольной страницы. Управление для подобласти $8000-$BFFF осуществляется портом MPAG, а для подобласти $C000-$FFFF – портом MPAGEX. Бит D7 записываемого в эти порты значения определяет половину страницы, отображаемую в подобласти (D7=0 – первая половина, D7=1 – вторая), в то время как биты D6-D0, как и прежде, определяют номер страницы, из которой выбирается половина. Данную схему можно представить, как адресацию страницами по 16 килобайт, однако номер такой страницы перед записью в порт MPAG или MPAGEX должен быть сдвинут вправо командной процессора RRC (RRCA).

При переключении бита B_EXPAG актуальная карта отображения страниц в области $8000-$FFFF не меняется; изменения происходят лишь при последующей записи в порты MPAG, MPAGEX.

Внимание! При обращениях к ПЗУ следует устанавливать частоту процессора 10 МГц.

# Звук

## Звуковые интерфейсы NeoGS

Карта NeoGS содержит два типа звуковых интерфейсов: интерфейс семплированного звука и интерфейс MP3-декодера. Семплированный звук выводится при помощи аудио-ЦАПа на частоте дискретизации 37500 Гц и может содержать до 8 каналов разрядностью 8 бит с индивидуальной 6-битной громкостью. MP3-декодер поддерживает формат MPEG audio layer 3 с битрейтом до 320 килобит в секунду и частотой дискретизации до 48 кГц.

## Интерфейс семплированного звука

Карта NeoGS выводит семплированный звук при помощи 16-битного стереоаудиоЦАПа TDA1543, работающего с частотой дискретизации 37500 Гц. Однако с точки зрения программиста, NeoGS имеет 4 или 8 8-битных каналов, каждый с индивидуальной 6-битной громкостью. Масштабирование 8-битного отсчёта громкостью, сложение каналов и вывод их в ЦАП происходят автоматически и независимо от процессора NeoGS.

Громкостью является беззнаковое 6-битное число: 0 соответствует минимальной громкости (канал выключен), 63 — максимальной.

Отсчёт является 8-битным беззнаковым либо знаковым числом, изменяющимся от 0 до +255 или от -128 до +127 соответственно. Масштабирование отсчёта громкостью происходит согласно формуле chan_value = (ucount‑$80)*volume либо chan_value = scount*volume, где ucount – беззнаковый 8-битный отсчёт, scount – знаковый 8-битный отсчёт, volume – беззнаковая 6-битная громкость, chan_value – знаковое число. Сумма chan_value для всех левых или правых каналов выводится в ЦАП, который работает со знаковыми 16-битными числами.

Как NeoGS воспринимает отсчёты (знаковые или беззнаковые), определяет бит B_INV7B порта GSCFG0. Если этот бит устанавливается в 1, то отсчёты воспринимаются, как знаковые числа, в противном случае — как беззнаковые. После сброса значение этого бита 0.

NeoGS имеет следующие режимы вывода семплированного звука: 4-канальный режим, 8-канальный режим и 4-канальный режим с паннингом.

Для указания громкости в каналах служат порты ввода-вывода VOL1, VOL2, …, VOL8. Для указания отсчёта в канале процессор читает байт из области памяти $6000-$7FFF. Конкретный адрес определяет номер канала, в который пойдёт отсчёт, а прочитанное значение запоминается FPGA во внутреннем буфере и является отсчётом. Громкости при записи в порты VOL1-VOL8 также запоминаются во внутреннем буфере FPGA. Из буфера с частотой 37500 Гц отсчёты и громкости передаются в ЦАП. Конкретное время, когда отсчёт из внутреннего буфера отправится в ЦАП не определено и является различным для разных каналов. При попадании нескольких отсчётов или громкостей для одного канала во внутренний буфер сохраняется лишь последнее значение. Для синхронизации поступления отсчётов в ЦАП следует использовать прерывание, следующее с частотой 37500 Гц.

Примечание: не следует выбирать отсчёты из области памяти $6000-$7FFF циклами выборки команд (M1). При необходимости исполнения кода из этой области, а также при хранении там данных, не относящихся к семплированному звуку, громкость всех каналов должна быть установлена на 0.

4-канальный режим выбирается битами в порту GSCFG0: B_8CHANS=0, B_PAN4CH=0. В этом режиме задействованы порты громкости VOL1-VOL4, соответствующие каналам 1-4. Распределение памяти для отсчётов следующее:

Область памяти | Канал
$6000-$60FF | 1
$6100-$61FF | 2
$6200-$62FF | 3
$6300-$63FF | 4
$6400-$64FF | 1
$7F00-$7FFF | 4

Левыми каналами являются каналы 1 и 2, правыми — 3 и 4.

8-канальный режим выбирается битами в порту GSCFG0: B_8CHANS=1, B_PAN4CH=0. В этом режиме задействованы порты громкости VOL1-VOL8, соответствующие каналам 1-8. Распределение памяти для отсчётов следующее:

Область памяти | Канал
$6000-$60FF | 1
$6100-$61FF | 2
$6200-$62FF | 3
$6300-$63FF | 4
$6400-$64FF | 5
$6500-$65FF | 6
$6600-$66FF | 7
$6700-$67FF | 8
$6800-$68FF | 1
$7F00-$7FFF | 8

Левыми каналами являются каналы 1, 2, 5 и 6, правыми — 3, 4, 7 и 8.

Внимание! В 8-канальном режиме относительная громкость отдельно взятого канала в 2 раза меньше, чем в 4-канальном.

4-канальный режим с паннингом выбирается битами в порту GSCFG0: B_8CHANS=0, B_PAN4CH=1. В этом режиме распределение памяти отсчётов по каналам такое же, как в обычном 4-канальном режиме. Однако используются все порты VOL1-VOL8 в соответствии с таблицей:

Левые каналы | Правые каналы
канал 1, громкость VOL1 | канал 1, громкость VOL3
канал 2, громкость VOL2 | канал 2, громкость VOL4
канал 3, громкость VOL5 | канал 3, громкость VOL7
канал 4, громкость VOL6 | канал 4, громкость VOL8

## Интерфейс MP3-декодера

MP3-декодер подключён к FPGA через два SPI-интерфейса, один из которых управляющий, а по другому передаются MP3-данные. Обобщённое описание SPI-интерфейсов приводится в главе 7 , а описание самого MP3-декодера — в его даташите (datasheet) и аппнотах (application notes) на него. Данное руководство ни в коей мере не собирается каким-либо образом пересказывать документы на MP3-декодер, откуда следует, что для работы с декодером необходимо изучить эти документы и главу 7 .

В NeoGS ставятся микросхемы MP3-декодеров MA8201 и MA8201A, являющиеся полными аналогами микросхем VS1001 и VS1011 фирмы VLSI Solutions Oy. Даташиты и аппноты следует скачивать с сайта http://www.vlsi.fi.

Внимание! Оба типа микросхем имеют существенные отличия друг от друга. Необходимо предусматривать определение типа микросхемы MP3-декодера и при работе учитывать различия между ними. В противном случае ваш плеер не будет работать у половины пользователей.

Для работы с MP3-декодером, помимо SPI-интерфейсов, предусмотрены следующие сигналы, доступные программисту:

- Выходной сигнал аппаратного сброса на MP3-декодер, управляемый битом B_MPXRS в порту SCTRL, активный уровень низкий.
- Входной сигнал готовности принимать данные, поступающий с декодера, состояние которого считывается из бита B_MDDRQ порта SSTAT.

Замечания по работе с декодером:

1. Декодеры тактируются кварцевым резонатором 14 МГц, что является небольшим превышением официальной максимальной частоты согласно даташитам. Для нормальной работы (декодирование MP3-файлов с любым битрейтом) следует обязательно использовать внутреннее удвоение тактовой частоты, предусмотренное в декодерах (рабочая частота 28 МГц).
2. Максимальные частоты Fsck сигнала SCK для обоих SPI-интерфейсов декодера ограничены следующими величинами. При передаче байтов по управляющему интерфейсу (содержимое MC_READ не используется), равно как и по интерфейсу MP3-данных частота сигнала SCK соответсвуюшего интерфейса Fsck < Fdec/4, где Fdec - частота, на которой работает декодер (Fdec=14 МГц, если внутреннее удвоение выключено, или Fdec=28 МГц в противном случае). При приёме байтов по управляющему интерфейсу (содержимое MC_READ используется) Fsck < Fdec/6. В обоих случаях следует учитывать текущую частоту процессора Z80, состояние битов, задающих Fsck каждого интерфейса (B_MCSPD1, B_MCSPD0, B_MDHLF) и то, включено ли внутреннее удвоение тактовой частоты декодера или выключено.
3. После аппаратного или программного сброса внутреннее удвоение оказывается выключенным. Следует его включить, процедура включения отличается для разных (VS1001 и VS1011) декодеров. В случае VS1001 после установки регистра CLOCKF следует записать константу 0x8008 в недокументированный регистр INT_FCNTLH (см. аппнот vs10XXan.pdf). В случае VS1011 на месте регистра INT_FCNTLH оказывается другой по функции регистр и запись в него производить не требуется, а для включения удвоителя требуется записать значение частоты дискретизации (любое применимое) в регистр AUDATA (см. аппнот vs10XXan.pdf). В дальнейшем актуальное значение частоты дискретизации установится автоматически. В обоих случаях константа, записываемая в регистр CLOCKF, остаётся неизменной (0x9B58)
4. Для определения типа декодера (VS1001 или VS1011) следует прочитать регистр STATUS и заглянуть в биты 7:4 этого регистра. Так как определять тип декодера требуется до включения удвоителя (пункт 3), следует особо внимательно отнестись к пункту 2: Fdec/6 в этом случае составит 2.3 МГц, и Fsck для корректного чтения не должна быть более этого значения.
5. При проигрывании некорректного или испорченного MP3-файла, вследствие электромагнитных помех и т.д. декодер может зависнуть: при этом, как правило, проигрывание звука прекращается, а счётчик времени проигрывания (регистр DECODE_TIME) не инкрементируется. Также признаком зависания является чересчур низкая или череcчур высокая скорость потребления декодером MP3-данных (см. аппнот vs10XXan.pdf). При обнаружении зависания необходимо выполнить программный сброс, повторить процедуру инициализации и вновь обратить внимание на признаки зависания. В случае, если декодер не 'отвис', необходимо провести аппататный сброс (бит B_MPXRS в порту SCTRL). Грубый замер скорости потребления декодером MP3-данных можно провести, используя как репер звуковые прерывания NeoGS, следующие с частотой 37500 Гц независимо от частоты процессора Z80.
6. После окончания данных в MP3-файле рекомендуется выдать в декодер 2048 байт нулей, после чего для начала декодирования следующего файла необходимо провести программный сброс. Применять вместо него аппаратный сброс не рекомендуется, так как при этом возникают щелчки в звуковом тракте декодера.
7. Управление режимами bass/treble и surround в обоих типах декодеров (VS1001 и VS1011) существенно различается.
8. В декодере VS1011 предусмотрено несколько режимов приёма MP3-данных. Следует использовать лишь установленный по умолчанию после сброса режим совместимости с декодером VS1001 с участием сигнала битовой синхронизации BSYNC. Сигнал BSYNC генерируется аппаратно схемой SPI-интерфейса для MP3-данных в FPGA и внимания к себе со стороны программы Z80 не требует.

# Интерфейс SD-карты

## Введение

Для изучения принципов работы с SD-картой необходимо предварительно ознакомиться с главой 7 данного руководства. Также необходимо изучить описание стандарта на SD-карты. При необходимости обрабатывать файловую систему SD-карты (например, FAT16, FAT32) информацию по ним следует искать в документах от microsoft (для случая FATxx) или в других описаниях. В данной главе приводится лишь информация, не охваченная вышеназванными источниками.

Кроме SPI-интерфейса, к интерфейсу SD-карты относятся биты B_SDDET и B_SDWP в порту SSTAT, отражающие, соответственно, наличие SD-карты в разъёме и установку флажка защиты от записи на SD-карте. Бит B_SDDET установлен в 0 при отсутствии карты. Бит B_SDWP установлен в 1 при флажке в положении «защита записи». Примечание: флажок защиты записи не соединён электрически (или как ещё) с электроникой SD-карты. Соответственно, записывать на SD-карту можно при любом положении этого флажка. Внимание! Не рекомендуется использовать данные биты в программах. Контакты на разъёме SD-карты могут загрязниться или окислиться, из-за чего возможен долговременный дребезг, плавание сигнала или несрабатывание. Кроме того, на первой ревизии платы NeoGS бит B_SDDET из-за ошибки в схеме определяется состоянием наплатного светодиода вместо положения флажка на SD-карте. Наличие SD-карты в разъёме можно определить фоновой попыткой её инициализации (с обязательным выходом по таймауту).

Частота процессора в NeoGS варьируется от 10 до 24 МГц, следовательно, частота Fsck изменяется в пределах от 5 до 12 МГц, что лежит в пределах спецификаций SD-карт на эту частоту (не более 25 МГц).

Порт SD_RSTR, который выдаёт предыдущий принятый байт и инициирует обмен с передаваемым байтом 0xFF, может использоваться для всех сценариев обмена данными и командами с SD-картой по аналогии работы с интерфейсом SD-карты в Z-controller'е, следует лишь помнить про программные паузы 16 или 18 тактов.

## Пример

Инициализация SD-карты:

LD A,M_SETNCLR+M_SDNCS

OUT (SCTRL),A ;CS для карты в 1

LD B,74

LD A,#FF

sendones:

OUT (SD_SEND),A

DJNZ sendones ;посылаем много единичек

LD A,M_SDNCS

OUT (SCTRL),A ;CS для карты в 0

LD HL,cmd0

CALL sendcmd

wait1:

LD A,#FF

OUT (SD_SEND),A

NOP

NOP

IN A,(SD_READ)

DEC A

JR NZ,wait1 ;ждём выполнения команды CMD0

recmd1:

LD HL,cmd1

CALL sendcmd

wait2:

LD A,#FF

OUT (SD_SEND),A

NOP

NOP

IN A,(SD_READ)

CP #FF

JR Z,wait2

RRA

JR C,recmd1 ;ждём выполнения команды CMD1

; SD-карта готова к работе

…

sendcmd:

LD B,6

scmd:

LD A,(HL)

OUT (SD_SEND),A

INC HL

DJNZ scmd

RET

cmd0: DB #40,0,0,0,0,#95

cmd1: DB #41,0,0,0,0,#FF

# SPI-интерфейсы
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

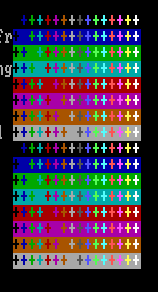
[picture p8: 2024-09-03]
zx/Neo_Player_Light/sprinter_colors.png

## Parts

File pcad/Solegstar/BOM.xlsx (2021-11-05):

 | Перечень элементов NeoGS-CM
Поз. | Корпус | Номинал | Кол-во | Примечание
C1, C2, C5, C6, C7, C8, C9, C11, C12, C14, C16, C18, C19, C20, C21, C22, C23, C24, C25, C27, C28, C29, C30, C31, C32, C33, C34, C40, C42, C43, C44, C45, C46, C47, C50, C51, C52, C53 | 0805 | 0.1uF | 38
C3, C4, C10, C13, C15, C17, C26, C36, C39 | ECAPCHIP | 10uF | 9
C35, C37 | 1210 | 100uF | 2
C38, C41 | 0805 | 22nF | 2
C48, C49 | 0805 | 33pF | 2
D1 | SO14 | 74ACT04 | 1
D2 | SO20 | 74HCT245 | 1
D3 | TQFP144 | EP1K30TC144 | 1
D4 | SO14 | 74HCT125 | 1
D5 | PLCC32 | 29F040 | 1
D6 | TQFP44 | Z84C0020FEC | 1
D7 | SO20 | 74LCX245 | 1
D8 | TQFP44 | MA8201 | 1 | * вместо D8`
D8` | LQFP-48 | VS1011E | 1 | * вместо D8
D9 | TQFP100 | EPM3064ATC100 | 1
DA1, DA2 | DPAK | LD1117DT33TR | 2
DA3 | DPAK | LD1117DT25TR | 1
DA4 | TO92 | KIA7042AP | 1
DA5 | SO8 | NE5532 | 1
DA6 | DIP8 | TDA1543 | 1 | * или SO16
DA7 | SOT-223 | LD1117S33TR |  | * см. схему
J1 | PLS2 | PLS2 | 1
L1 | CDR64B | 27uH | 1
L2 | 0805 | 1R0 | 1
QZ1 | 7050 | 20MHz | 1
QZ2 | 7050 | 24MHz | 1
R1, R2, R3, R4, R5, R6, R44 | 0805 | 51 | 7
R7, R9, R11, R12, R14, R15, R16, R18, R22, R23, R24, R26, R27, R28, R30, R31, R32, R33, R34, R35, R36, R37, R38, R40, R43, R46, R53 | 0805 | 6K8 | 27
R8, R10, R13, R19, R20, R21, R25, R29, R41, R42, R47 | 0805 | 1K | 11
R17, R45, R49 | 0805 | 100 | 3
R39 | 0805 | 1 | 1
R48, R51 | 0805 | 390 | 2
R50 | 0805 | 3K3 | 1
R52 | 0805 | 1M | 1
R54 | 0805 | 100K | 1
RAM1, RAM2 | TSOP I 48-PIN | CY62167EV30LL-45ZXI | 2
S1 | KLS7 | KLS7-TS6601 - 5.0 -180 | 1
VD1 | KIPD14 | KIPD14 | 1
VT1 | BC847 | BC847 | 1
X1 | IDC10M | IDC10M | 1 | JTAG
X2 | ST-214C | PJ-324M | 1 | AUDIO
X3 | PLS4 | PLS4 | 1
X4 | MICROSD | MICROSD | 1
XSD1 | SD SHORT | SD SHORT | 1
Z1 | HC49S | 14MHz | 1

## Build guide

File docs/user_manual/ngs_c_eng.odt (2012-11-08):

Sound Card Neo GS.

Revision C

NedoPC group. 2010

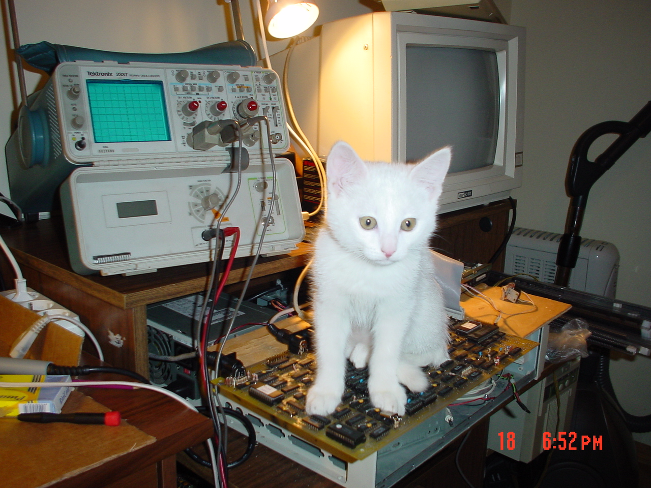
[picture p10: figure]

(version 6. Nov. 2012)

www.nedopc.com

# Description.

Sound card designed for playing MOD and MP3 music files. Sound card not use computer resources via playing.

Sound card designed for using in spectrum compatible computer with ZXBUS slot.

Sound card compatible with General Sound and support programs for General Sound.

Features:

- 4Mb RAM and 512Kb ROM;
- SD card reader;
- Additional turbo-mode for processor (20МГц);
- MP3-decode chip MA8201A-U(compatible with vs1011);
- 8-sound channels by hardware;
- Easy firmware upgrade.

# Install

pin 1

Sound card designed for installing to ZXBUS board. First pin placed on left side of board (on top side with parts of board, see picture). Sound cards board has key (near first pin, see picture) for easy installing to slot.

Warning! Power off before install or remove sound card to/from main-board.

Warning! Not use extremely force via installing board. It may to destroy connector of sound card or slot of main-board.

Warning! Please install sound card to slot on right direction. If install NeoGS on incorrect direction then NeoGS or main-board may be malfunction.

Warning! Installed sound card must not contacted with other cards or case sides. If NeoGS contacted to other card then please isolate NeoGS.

Warning! Please sure then contacts of NeoGS not shifted to main-boards slot contacts.

Warning! Power off before connect speakers or amplifier to sound card.

# Use

## Check the NeoGS

You can to check the NeoGS via Basic program:

10 OUT 187,244

20 PAUSE 100

30 PRINT IN 179

Must displayed value 126.

## Tune

NeoGS board has jumper J1 (placed on top side of board, in right-down, down to processor). Jumper regulate NeoGS reaction to “reset” signal from main-board:

- J1 short — NeoGS reset if signal come from main-board;
- J1 open — NeoGS not react if signal come from main-board.

## Software

NeoGS started to compatible with General Sound mode. Can to use any software for General Sound in this mode.

Software, whose work in other modes of NeoGS (for example MP3 player), set NeoGS to non-compatible with General Sound state. Recommended to reset NeoGS after using this software via NeoGS-reset button (placed on top side of board, in right-up, see picture) or via software reset.

New firmware available from site www.nedopc.com .

## Documentation

Hardware sources and programming manual available from site www.nedopc.com .

# Service

Sound card NeoGS shipped ready to use.

All sound cards tested on ZX-Evolution computer.

Supplier decline all responsibility in any cases.

# Project status

Project is open source.

Please coordinate NeoGS production questions with authors.

# About

Authors: Vadim Akimov (LVD), Roman Chunin (CHRV), Vyacheslav Savenkov (Savelij), Aleks Ghabin (KOE), Vasily Klimov (JTN).

Site: http://www.nedopc.com

NeoGS page: http://www.nedopc.com/gs/ngs_eng.php

Catalog: http://www.nedopc.com/catalog.php

Thanks to:

Evgeny Muchkin — for information about General Sound and for coordinating author rules.

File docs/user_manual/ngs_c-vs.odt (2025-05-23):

Музыкальная плата Neo GS.

Revision C-VS

www.nedopc.com 2025

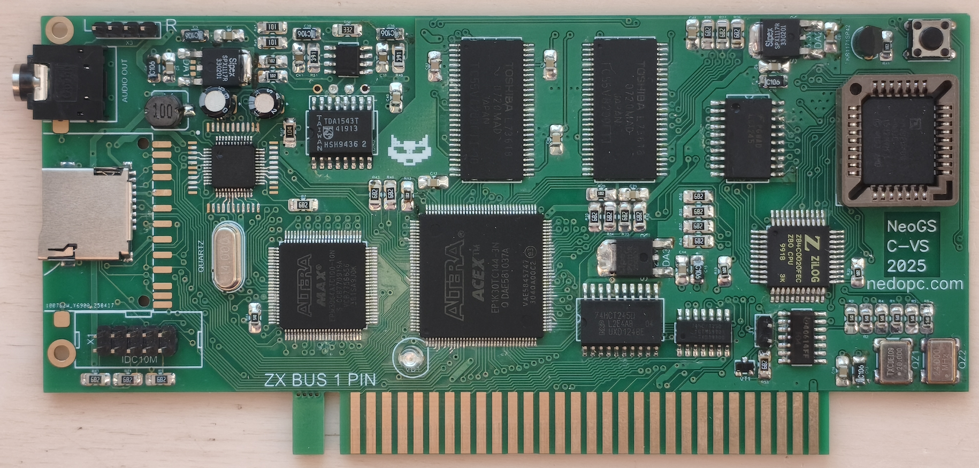
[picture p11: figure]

(версия от 23.05.2025)

www.nedopc.com

# Описание устройства.

Музыкальная плата предназначена для воспроизведения музыкальных файлов в формате MOD, MP3 (и прочих форматов в зависимости от используемого чипа). Проигрывание обеспечивается не используя ресурсы компьютера.

Музыкальная плата предназначена для установки в Spectrum-совместимый компьютер, оснащенный слотом ZXBUS.

Музыкальная плата совместима программно с General Sound и поддерживает все программное обеспечение предназначенное для нее.

Краткие характеристики платы Neo GS:

- 4Mb RAM и 512Kb ROM;
- Набортный SD card ридер (доступен вариант с microSD разъемом);
- Дополнительный турбо режим для процессора (20МГц/24МГц);
- Аппаратный mp3-декодер VS1053 (любой из серии декодеров VLSI в LQFP48 корпусе) или MA8201A-U в корпусе QFP44 (совместимый с vs10x1);
- 8-аппаратных звуковых каналов;
- Возможность апгрейда программными методами.

При отсутствии на компьютере слота ZXBUS, его можно сделать. Рекомендуется это поручить квалифицированному человеку. Описание этой работы не входит в данный документ.

# Установка

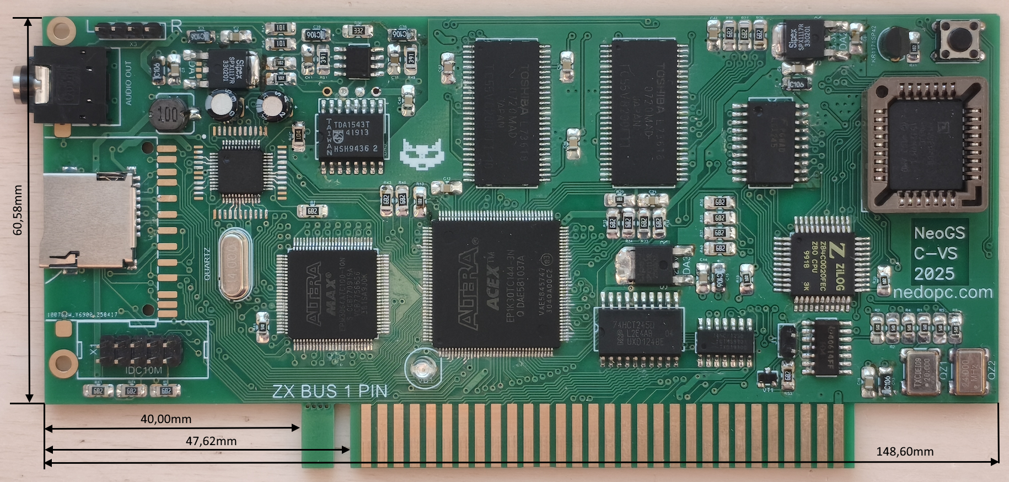
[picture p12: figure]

Плата предназначена для установки в слот ZXBUS с шагом контактов 2.54мм. Первый контакт находится слева на лицевой стороне платы (со стороны монтажа деталей, см. рисунок). Плата оснащена направляющим ключом (около первого контакта разъема платы, см. рисунок) для удобной установки в слот. Если ключ мешает установке платы, его можно отломить.

Внимание! Все манипуляции с подключением/установкой производить при выключенном компьютере.

Внимание! Разъем платы не обработаны фрезой. Поэтому при установки не используйте сильных усилий, чтобы не погнуть контакты разъема ZXBUS.

Внимание! Соблюдайте полярность установки платы. При нарушении полярности NeoGS может выйти из строя.

Внимание! После установки в слот плата не должна контактировать с другими устройствами или стенками корпуса. Если это происходит обязательно изолируйте плату с помощью изоляционного материала.

Внимание! Перед включением убедитесь, что контакты NeoGS и разъема ZXBUS не смещены относительно друг друга.

Внимание! Рекомендуется подключение звуковоспроизводящего оборудования, имеющего собственный источник питания (активные колонки, усилители), производить до включения компьютера.

# Программное обеспечение

## Проверка работоспособности

Правильность подключения тестируется небольшой Basic-программой:

10 OUT 187,244

20 PAUSE 100

30 PRINT IN 179

После срабатывания программы должно появится значение 126.

## Настройка платы

Плата NeoGS оснащена джампером J1 (на стороне установки деталей, в правом нижнем углу, под процессором). Джампер предназначен для регулирования режима реагирования на сигнал reset с шины ZXBUS компьютера:

Элемент настройки | закорочен | разомкнут
J1 | NeoGS сбрасывается при поступлении сигнала сброса от компьютера | NeoGS не реагирует на поступлении сигнала сброса от компьютера

## Работа с платой

После включения NeoGS стартует в режиме совместимости с General Sound. В этом режиме можно использовать программное обеспечение предназначенное для General Sound.

Программное обеспечение работающие с другими режимами (например mp3 плеер) могут перевести плату в состояние, при котором не будет совместимости с General Sound. После работы с такими режимами плату можно вернуть в начальное состояние с помощью кнопки NeoGS-reset (находится в верхнем правом углу лицевой стороны платы, см. рисунок) либо программным сбросом.

Модификация (обновление) прошивок производится программным способом. Рекомендуется устанавливать наиболее свежие модификации, доступные с сайта производителя.

Документация

Технологическая документация и документация программиста расположена на сайте изготовителя. Обновляется по мере необходимости и готовности.

# Гарантии и сервисное обслуживание

Плат от команды NedoPC поставляются со следующими условиями:

- Платы поставляются в рабочем (собранном и отлаженном) виде.
- Работоспособность платы проверяется с помощью компьютера ZX-Evolution (на базовой конфигурации и с программным обеспечением от NedoPC).
- Изготовитель не несет ответственности за нарушение работоспособности платы в любых случаях.
- Платы возможно сдать в ремонт только по предварительному согласованию с участниками команды NedoPC.

Внимание! Претензии по работоспособности плат NeoGS любых версий, изготовленных без участия команды NedoPC, не принимаются и не рассматриваются.

# Статус проекта

Проект является полностью открытым (open source), то есть вся технологическая документация и исходные коды выложены и открыто доступны любому желающему.

Вопросы производства устройства пожалуйста согласовывайте с авторами.

Альтернативные версии или переразводки плат (их схемы, описание различий) рекомендуем присылать к нам для размещения в репозитории исходных текстов. Это нужно для поиска информации по всем версиям платы в одном месте/репозитории.

# Информация о нас

Разработчики: Вадим Акимов (LVD), Роман Чунин (CHRV), Вячеслав Савенков (Savelij).

Интернет сайт: http://www.nedopc.com

Интернет страница проекта: http://www.nedopc.com/gs/ngs.php

Каталог: http://www.nedopc.com/catalog.php

Огромное спасибо:

Евгению Мучкину — за предоставленную информацию по General Sound и решение вопросов с авторскими правами.

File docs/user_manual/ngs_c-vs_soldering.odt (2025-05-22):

(версия от 22.05.2025)

www.nedopc.com

Сборка и настройка звуковой карты NeoGS

(NeoGS revision C-VS)

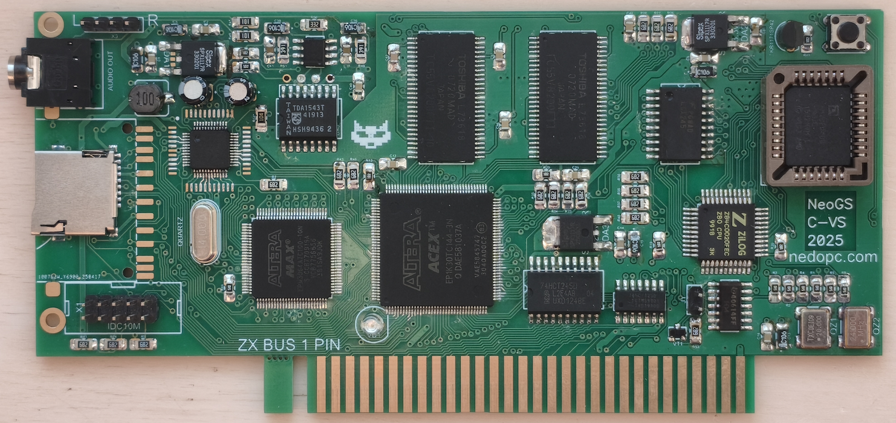
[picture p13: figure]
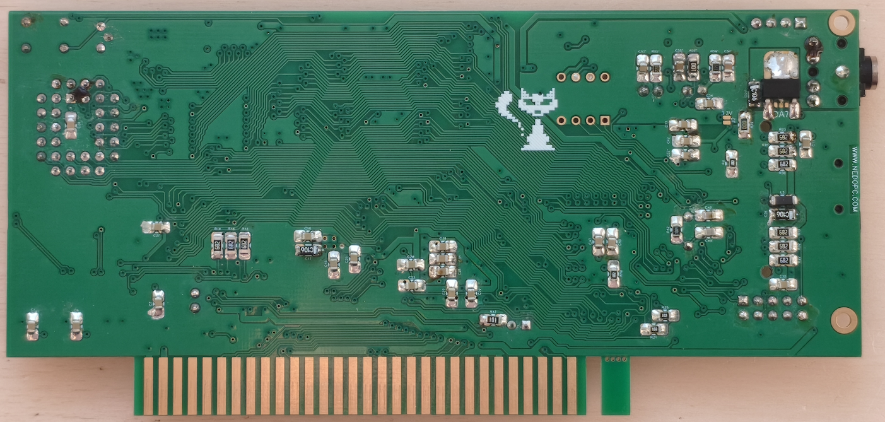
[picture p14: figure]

# Введение

Версия звуковой карты NeoGS C-VS имеет следующие отличия от предыдущих версий:

- плата имеет такой же размер как NeoGS версии C;
- кроме установки чипа MA8201A-U, предусмотрена возможность установки чипов от VLSI VS10xx (VS1001, VS1011, VS1003, VS1033, VS1053, VS1063) в корпусе LQFP48;
- предусмотрены альтернативные способы сборки питания для различных чипов;
- изменен аудио-разъем на классический 3.5 разъем;
- добавлен альтернативный разъем для установки microSD карт памяти.

## Что необходимо для сборки

Для сборки звуковой карты NeoGS необходимы навыки пайки SMD компонентов и микросхем в корпусе QFP и TSOP.

Внимание: Для загрузки конфигурации в EPM3064ATC100 достаточно иметь программатор Altera USB blaster или использовать самодельный программатор ByteBlaterMV или подобный (смотри раздел 7).

Внимание: Для загрузки конфигурации в ROM (ПЗУ) микросхемы потребуется программатор (можно воспользоваться возможностями TEST&SERVICE конфигурации компьютера ZX Evolution).

Перед сборкой необходимо распечатать монтажную схему. На ней отмечены все номиналы используемых элементов.

Рекомендуется прочитать это описание полностью до начала сборки, чтобы уяснить некоторые непонятные моменты и представлять как и в каком порядке осуществлять сборку.

Несколько обычных советов, собирающим звуковую карту самостоятельно:

- Пожалуйста соблюдайте порядок сборки, некоторые элементы сложно установить если порядок сборки нарушен;
- Не спешите и старайтесь сверять с монтажной схемой каждую устанавливаемую деталь. Выпаивать деталь припаянную неверно гораздо сложнее, чем лишний раз сверить соответствие с монтажной схемой;
- Соблюдайте полярность элементов, элементы установленные неправильно в большинстве случаев могут привести не только к сбою самого элемента, но и выгоранию других элементов;
- Помните, что аккуратная сборка гарантирует быстрый запуск и наладку компьютера;
- Не смешивайте разные элементы в кучу, некоторые элементы не имеют маркировки (например, SMD конденсаторы) и найти нужный будет проблематично.

В приложениях к описанию приведены примеры маркировки деталей и описан состав деталей поставляемых в комплекте, пожалуйста ознакомитесь с этими пунктами до сборки.

# Порядок сборки

1. Напайка микросхем в QFP корпусах (D3, D6, D8 и D9). Замечания:
  1. Обязательно устанавливать корпус согласно ключу, отмечающему первый вывод микросхемы;
  2. Зафиксируйте микросхему так, чтобы выводы попадали точно на контактные площадки и проведите аккуратно пайку (описания метода пайки не входит в рамки документа, автор использует метод волны — т.е. сперва покрывает контакты обильно флюсом и потом проводит паяльником, сразу припаивая одну сторону микросхемы);
  3. В случае, если не удалось припаять микросхему аккуратно, снимать припой нужно повторно, смочив контакты микросхемы флюсом и проводя аккуратно очищенным паяльником. Не пытайтесь снимать припой механическим путем с помощью иголок или других приспособлений, так можно погнуть выводы микросхемы;
  4. Внимание: Обязательно ознакомьтесь с особенностями сборки при использовании конкретного звукового чипа (смотрите раздел 3).
2. Пайка микросхем в TSOP (RAM1, RAM2) корпусах. Пайку производить рекомендуется таким же способом как и QFP микросхем, соответственно придерживаться тех же замечаний. Внимание: При пайке TSOP микросхем (RAM1,RAM2) следите за тем, чтобы выводы микросхемы точно совпадали с контактными площадками. При смещении вывода за пределы контактной площадки, возможно замыкание на поля, находящиеся между площадок (изза не высокой точности производства плат возможно смещение маски).
3. Пайка SMD резисторов, конденсаторов и транзистора. При пайке танталовых конденсаторов следует обращать внимание на полярность (плюсовой вывод танталовых конденсаторов отмечен чертой или скосом корпуса). Внимание: При пайке блокировочных конденсаторов (0.1mkF) следите за тем, чтобы контакт конденсатора не попадал на зазор между контактной площадкой и полем GND (изза не высокой точности производства плат возможно смещение маски). Это может привести к замыканию напряжения питания на GND.
4. Пайка микросхем в SOIC корпусах. Внимание: При пайке SOIC микросхем следите за тем, чтобы выводы микросхемы точно совпадали с контактными площадками. При смещении вывода за пределы контактной площадки, возможно замыкание на поля, находящиеся между площадок (изза не высокой точности производства плат возможно смещение маски).
5. Пайка SMD компонентов, имеющих большой размер (дроссели, кварцевые генераторы, стабилизаторы). Замечания:
  - Рекомендуется убедиться на отсутствие замыканий цепей питания на GND перед установкой стабилизаторов. Если есть замыкания, то устранить их.
6. Пайка разъема держателя SD карты (XSD1, XSD1*).
7. Пайка DIP (если используется DA6 в DIP корпусе), TO92 (DA4) и PLCC панельки (D5), а также выводных компонентов (электролитических конденсаторов, кварца, светодиода). Замечания:
  - Устанавливать микросхемы/панельки обязательно согласно ключу.
  - При пайке надо учитывать, что маска может не закрывать окружающее вывод пространство. Поэтому во избежание короткого замыкания нужно паяльник отрывать вверх от припаиваемого контакта (тоже касается пайки всех выводных элементов).

Внимание: Зазор между контактными площадками выводных элементов и полем GND слишком мал. Изза небольшого смещения маски (дефект производства), края поля GND рядом с контактной площадкой оголены. Изза этого, при неаккуратной пайке, возможны замыкания контакта на GND.

8. Пайка штыревых разъемов. Внимание: Зазор между контактными площадками выводных элементов и полем GND слишком мал. Изза небольшого смещения маски (дефект производства), края поля GND рядом с контактной площадкой оголены. Изза этого, при неаккуратной пайке, возможны замыкания контакта на GND.
9. Пайка остальных разъемов и кнопки.

## Действия после сборки платы

- Желательно промыть плату спиртом для очистки от флюса. Рекомендуется промывать плату на определенных этапах, например после пайки всех SMD компонентов и перед пайкой разъёмов. При промывке следите, что бы растворённый флюс не попадал на рабочую поверхность контактов разъемов. Удалить его впоследствии будет сложно или невозможно.
- Обязательно тестером (или прозвонкой) проверить на замыкание с GND все рабочие напряжения питания платы (плата должна быть отключена от источников питания). Причем проверять не только на разъеме питания, но и на выходах стабилизаторов. В случае обнаружения замыкания обязательно устранить причину (см. «Внимание» п.2, п.3, п.4).
- Рекомендуется тестером (или прозвонкой) проверить на замыкание с GND все контакты выводных элементов (неподсоединенных схемно к GND). В случае обнаружения замыкания обяазтельно устранить причину (см. «Внимание» п7, п8).

# Особенности сборки для разных звуковых чипов

Для платы предусмотрена установка разных звуковых чипов — для этого предусмотрены избыточные посадочные места установки элементов. Поэтому обязательно ознакомьтесь с ниже приведенной документацией, чтобы правильно собрать звуковую плату.

## Сборка при использовании чипа MA8201A-U

Микросхема MA8201A-U является функциональным аналогом микросхемы VS1001 (или VS1011 – зависит от партии поставки).

При использовании чипа MA8201A-U (корпус LQFP44), не используются следующие элементы:

1. Элементы дополнительной обвязки звукового чипа: C53*,C54*,C55*, R54*, R55*, R56*, R57*. Их не нужно устанавливать на плату.
2. Элементы обеспечивающие питание ядра (шина CVDD) звукового чипа (для MA8201A-U питание ядра совпадает с питанием IO-выводов и равно 3.3в): DA7* или DA7*’, C51*, C52*. Их не нужно устанавливать на плату.
3. Не нужно замыкать элемент J2, так как шина CVDD не используется при установке микросхемы MA8201A-U.

Внимание! При использовании альтернативного DA1’ (sot23-5) вместо DA1 (DPAK) рекомендуется на место конденсаторов C3, С4 ставить керамический SMD конденсатор на 1мкФ (1uF).

## Сборка при использовании чипов VS10хх от VLSI

Микросхемы VLSI имеют, несмотря на одинаковый корпус (LQFP48) и расположение выводов, разные требования по питанию ядра (шина CVDD) звукового чипа.

При установке чипа VLSI должны быть установлены все дополнительные элементы обвязки звукового чипа помеченные знаком * на схеме: C53*,C54*,C55*, R54*, R55*, R56*, R57*. Также желательно припаять блокировочный конденсатор шины питания ядра CVDD: С52*.

Ниже прилагается таблица элементов для сборки в зависимости от маркировки звукового чипа:

Маркировка чипа | DA1 (шина AVCC33) (или DA1’) напряжение стабилизации | J2 (перемычка) | DA7* (шина CVDD) (или DA7*’) напряжение стабилизации
VS1001, VS1011 | 3.3V | замкнута | не устанавливать (в том числе и С51*).
VS1003, VS1033 | 2.8V | не замкнута | 2.5V
VS1053, VS1063 | 3.3V | не замкнута | 1.8V

Внимание! При использовании альтернативного DA1’ (sot23-5) вместо DA1 (DPAK) рекомендуется на место конденсаторов C3, С4 ставить керамический SMD конденсатор на 1мкФ (1uF).

Внимание! При использовании альтернативного DA7*’ (sot23-5) вместо DA7* (DPAK) рекомендуется на место конденсаторов C51* ставить керамический SMD конденсатор на 1мкФ (1uF).

# Настройка

Звуковая карта не требует подстройки каких либо элементов и при использовании исправных деталей и правильной, аккуратной сборке должна работать. Платы, изготовляемые по заказу от NedoPC проходят электротест и не должны содержать дефектов (в случае использования плат из других источников — спрашивать у соответствующих поставщиков).

Запуск и проверка работоспособности звуковой карты состоит из следующих этапов:

- Прошивка EPM3064ATC100, используя программатор USB Blaster или ByteBlasterMV через разъем X1 (к звуковой карте необходимо подвести питание +5в).
- Установка предварительно прошитой ROM 29F040 в панельку D5 (ROM поставляемые в комплекте конструктора от NedoPC – предварительно прошиты).
- Проверка исходящих частот с кварцевых генераторов (проверку можно осуществить осцилографом или измерителем частоты).
- Проверка корректной загрузки рабочей конфигурации в программируемую матрицу EP1K30TC144 (светодиод мигает при загрузке матрицы и должен гореть после загрузки).
- Проверка работоспособности различных блоков звуковой карты (MP3 плеер, MOD плеер).

Для проверки различных блоков звуковой карты ее необходимо установить в компьютер оснащенный ZXBUS слотом.

## Прошивка CPLD EPM3064ATC100

Прошивка доступна на сайте www.nedopc.com. Скачайте файл, он должен иметь расширение pof (обычно GS_cpld.pof).

Для прошивки возможно использовать программатор USB Blaster, ByteBlasterMV (смотри раздел 7) или любой другой с подобными возможностями.

Прошить возможно например из бесплатной программы Altera Quartus WEB edition доступной на www.altera.com или любой другой программы поддерживающую данную возможность.

## Прошивка микросхемы ROM (ПЗУ) 29F040.

Если Вы самостоятельно собираете звуковую карту и не обладаете прошитой микросхемой ROM (ПЗУ), то перед запуском карты необходимо прошить ROM на специализированном программаторе (при приобретении комплекта от NedoPC — микросхема ROM поставляется прошитой).

Также можно прошить ROM (ПЗУ) на плате ZX Evolution с помощью специализированной прошивки TEST&SERVICE (читайте соответствующую документацию).

Файл с содержимом ROM доступен с сайта www.nedopc.com .

Рекомендуется использовать микросхемы следующих производителей:

- M29F040B от ST;
- AM29F040B от Spansion (ex AMD).

Если используются микросхемы вышеуказанных производителей, то возможен программный апгрейд прошивок.

Внимание: Апгрейд прошивок производится специализированным программным обеспечением непосредственно на компьютере с установленной звуковой платой NeoGS без какой либо дополнительной подготовки. При поставке плат, прошивается в ROM последняя, на момент поставки, версия прошивки.

# Приложение 1. Маркировка деталей

## SMD резисторы

Для сборки можно использовать SMD резисторы типоразмеров 1206 или 0805 (контактные площадки поддерживают оба размера).

SMD резисторы маркируются следующим образом:

XYZ где XY – значение, Z — количество нулей, т.е значение равно XY*10^Z ом.

Например:
102 = 10*10^2 = 1000 ом (или 1 ком);
510 = 51*10^0 = 51ом.

SMD резисторы сопротивлением меньше десяти ом обозначаются следующим образом:

XRY где X - значение единиц ом, Y — значение десятых ома.

Например:
1R0 = 1,0 = 1 ом;
2R2 = 2,2 = 2,2 ом.

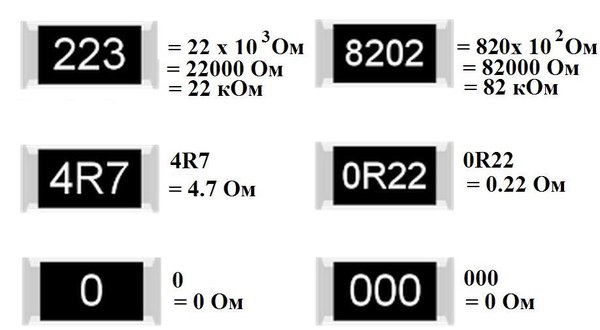
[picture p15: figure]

## SMD конденсаторы

Для сборки можно использовать SMD конденсаторы типоразмеров 1206 или 0805 (контактные площадки поддерживают оба размера).

Обычные SMD конденсаторы никак не маркируются.

## Танталовые SMD конденсаторы

Танталовые конденсаторы бывают типоразмеров Type A, Type B, Type C, Type D. Во избежания несоответствия используйте конденсаторы того размера, который указан в перечне деталей.

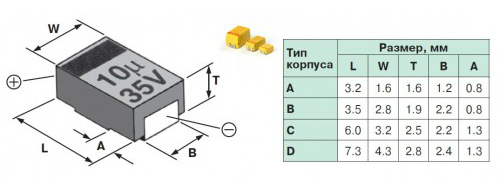
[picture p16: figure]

Маркировка танталовых конденсаторов сильно зависит от производителя, но практически всегда используются следующие правила:

- Плюсовой вывод маркируется жирной линией или скошенным углом корпуса;
- Емкость считается по правилу XYZ для резисторов, но измеряется в пф.

Например:
106 = 10*10^6 = 10000000пФ = 10мкФ (10uF)
475 = 47*10^5 = 4700000пФ = 4,7мкФ (4,7uF)

## Выводные конденсаторы

На выводных конденсаторах, как правило, пишут полностью емкость и максимальное напряжение в нормальном виде — например 100mkF x 16v.

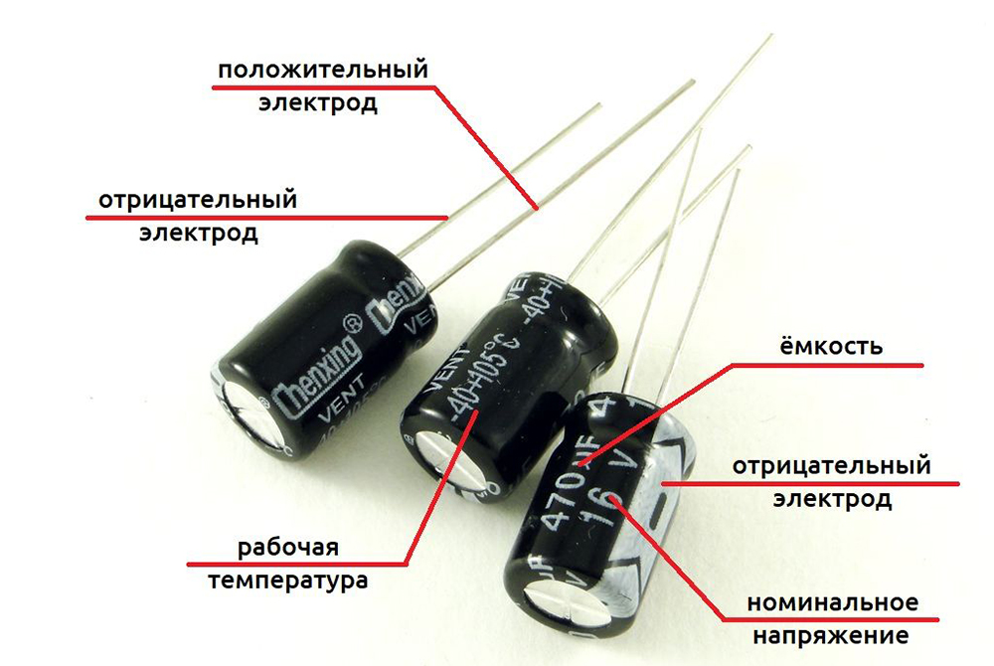
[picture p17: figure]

Минусовой вывод отмечен жирной чертой на корпусе конденсатора, как правило минусовой вывод более длинный.

## Транзисторы

Транзистор VT1 можно использовать любые серий BC846-BC850 в корпусе SOT-23.

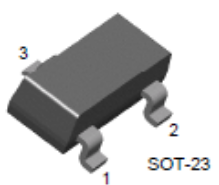
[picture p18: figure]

| 1. База 2. Эмиттер 3. Коллектор

Транзисторы производства Fairchild маркируются надписью на корпусе, как приведено ниже в таблице:

Type | BC846 | | | BC847 | | | BC848 | | | BC849 | | | BC850
| A | B | C | A | B | C | A | B | C | A | B | C | A | B | C
Mark | 8AA | 8AB | 8AC | 8BA | 8BB | 8BC | 8CA | 8CB | 8CC | 8DA | 8DB | 8DC | 8EA | 8EB | 8EC

Транзисторы производства Philips маркируются надписью на корпусе, как приведено ниже в таблице:

Type | BC846 | | | BC847 | | | BC848 | | | BC849 | | | BC850
| A | B | C | A | B | C | A | B | C | A | B | C | A | B | C
Mark | 1A* | 1B* | 1D* | 1E* | 1F* | 1G* | 1J* | 1K* | 1L* | | 2B* | 2C* | | 2F* | 2G*

Где * может принимать значение 'p' (made in HK), 'm' (made in Malaysia), 'W' (made in China).

Маркировка у других производителей может отличаться, сверяйте с datasheet.

## Светодиоды

Светодиод VD1 можно использовать любые аналоги АЛ307 или зарубежного производства.
При установке необходимо соблюдать полярность светодиода (сверяйтесь с документацией на светодиод или проверьте с помощью батарейки и резистора).

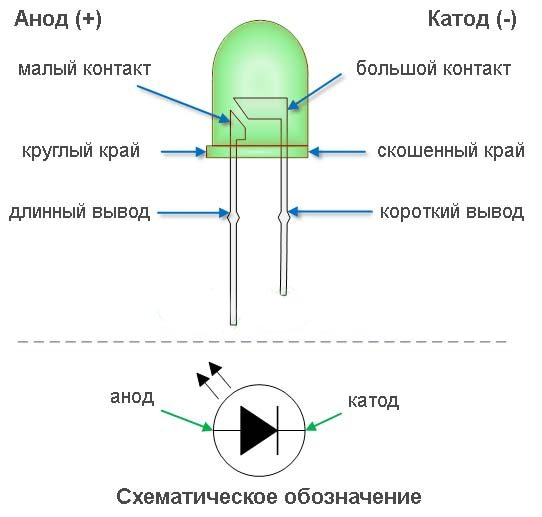
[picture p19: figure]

## Стабилизаторы

Стабилизаторы DA1-DA3, DA7* можно использовать любые, совместимые с серией LM1117 в корпусе TO-252 (DPACK).

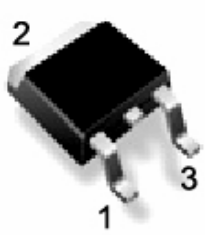
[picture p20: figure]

| 1. Общий 2. Выход 3. Вход

Маркировку лучше смотреть в datasheet производителя. Укажу несколько маркировок, которые встречаются чаще всего:

Part | Uout | LM1117 | K1254 | IL1117 | SPX1117
DA1,DA2 | 3.3V | LM1117DT-3.3V | К1254ЕН3АТ | IL1117-3.3D0T | SPX1117R-3.3
DA3 | 2.5V | LM1117DT-2.5V | К1254ЕН2АТ | IL1117-2.5D0T | SPX1117R-2.5

Стабилизаторы DA1’,DA7*’ можно использовать любые совместимые с ME6211C в корпусе SOT23-5 (SOT353).

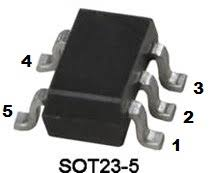
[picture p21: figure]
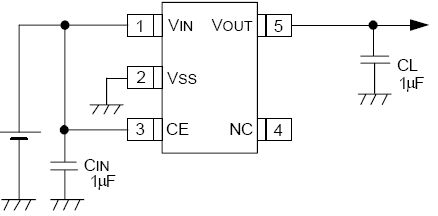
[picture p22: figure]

Uout | ME6211C | XC6219 | SPX3819M5 | TPS736xxDBV
3.3V | ME6211C33M5 | XC6219B332MR | SPX3819M5-L-3-3 | TPS73633DBV
2.8V | ME6211C28M5 | XC6219B282MR | SPX3819M5-L-2-8 | TPS73628DBV
2.5V | ME6211C25M5 | XC6219B252MR | SPX3819M5-L-2-5 | TPS73625DBV
1.8V | ME6211C18M5 | XC6219B182MR | SPX3819M5-L-1-8 | TPS73618DBV

Внимание: В случае использования стабилизаторов ME6211C, XC6219 рекомендуется входные/выходные конденсаторы использовать обычные smd конденсаторы емкостью 1mF вместо танталовых конденсаторов.
Для DA1’ – это позиции C3, C4.
Для DA7*’ - это позиция C51*.

Внимание: Во избежание казусов сверяйте подключение стабилизаторов с указанной выше схемой, стабилизаторы не соответствующие схеме подключения (в частности рекомендуется обратить на использование вывода 3 — он включает стабилизатор в рабочий режим) — не будут работать.

# Приложение 2. Список деталей

Внимание: символом * помечены детали, которые устанавливаются при использовании звуковых чипов VLSI VS10xx (при сборке со звуковым чипом MA8201A-U их не устанавливают).

Внимание: символом ’ помечены детали, которые устанавливаются вместо таких по той же позиции но в другом корпусе.

chips микросхемы
position позиция | name наименование | pattern корпус | pcs кол-во | аlternate альтернатива
D1 | 74ACT04 | SO14 | 1 | 74F04
D2 | 74HCT245 | SO20 wide | 1 | 74ACT245, 74AHCT245
D3 | EP1K30TC144 | TQFP144 | 1
D4 | 74HCT125 | SO14 | 1 | 74ACT125, 74AHCT125
D5[^1] | M29F040B | PLCC32 | 1 | AM29F040B
D6 | Z84C0020FEC | QFP44 | 1
D7 | 74LCX245 | SO20 wide | 1 | 74LVC245
D8 | MA8201A | LQFP44 | 1 | MA8201A-U
D8*[^2] | VS1033 | LQFP48 | 1 | VS1001, VS1011, VS1003, VS1033, VS1053, VS1063
D9 | EPM3064ATC100 | TQFP100 | 1
RAM1,RAM2 | TC55V8200FT | TSOP54 | 2 | μPD4416008G5-A15-9JF CY7C1069AV33-10ZX AS7C316096B-10TIN CY7C1069G30-10ZSXI CY7C1069GE30-10ZSXI IS61WV20488FBLL-10T2LI
DA1 | LM1117DT3.3 | DPAC | 1 | К1254ЕН3АТ, IL11173.3D0T, SPX1117R3.3
DA1’[^3] | ME6211C | SOT23-5 | 1 | XC6219B
DA2 | LM1117DT3.3 | DPAC | 1 | К1254ЕН3АТ, IL11173.3D0T, SPX1117R3.3
DA3 | LM1117DT2.5 | DPAC | 1 | К1254ЕН2АТ, IL11172.5D0T, SPX1117R2.5
DA4 | KR1171SP42 | TO92 | 1
DA5 | NE5532 | SO8 | 1
DA6, DA6* | TDA1543 | SO16, DIP8 | 1 | TDA1543T
DA7*[^4] | LM1117DT3.3 | DPAC | 1 | К1254ЕН3АТ, IL11173.3D0T, SPX1117R3.3
DA7*’[^5] | ME6211C | SOT23-5 | 1 | XC6219B
semiconductors активные компоненты
position позиция | name наименование | pattern корпус | pcs кол-во | аlternate альтернатива
VD1 | LED | 3.5mm, 805 | 1
VT1 | BC847 | SOT23 | 1 | BC846, BC848
quartz's кварцевые компоненты
position позиция | name наименование | pattern корпус | pcs кол-во | аlternate альтернатива
QZ1 | Quartz Gen 20MHz кварцевый генератор | OSC7X5 | 1
QZ2 | Quartz Gen 24MHz кварцевый генератор | OSC7X5 | 1
Z1 | Quartz 14MHz кварцевый резонатор | HC49, HC49U | 1
ferrits дроссели
position позиция | name наименование | pattern корпус | pcs кол-во | аlternate альтернатива
L1 | 220, 270 mkG | CDR64B | 1 | аny resistance < 1 Ohm любой с сопротивлением < 1 ом
L2 | 2R2, 1R0 | chip 1206, 805 | 1 | аny resistance < 1 Ohm любой с сопротивлением < 1 ом
capasitors конденсаторы
position позиция | name наименование | pattern корпус | pcs кол-во | аlternate альтернатива
C48,C49 | 33pF | chip 1206, 805 | 2
С53*,C54*[^6] | 10nf | chip 1206, 805 | 2
C38,C41 | 22nF | chip 1206, 805 | 2
С55*[^7] | 47nF | chip 1206, 805 | 1
C1,C2,C5-C9,C11, C12,C14,C16, C18-C25,C27-C34,C40, C42-C47,C50,C52*[^8] | 0,1mkF | chip 1206, 805 | 36
C3,C4,C10,C13,C15,C17,C26,C36,C39,C51*[^9] | 10mkF | type A | 9
C35,C37 | 100mkF | type B, 3.5mm | 2
resistors резисторы
position позиция | name наименование | pattern корпус | pcs кол-во | аlternate альтернатива
R39 | 1 Ohm | chip 1206, 805 | 1
R57*[^10] | 10 Ohm | chip 1206, 805 | 1
R55*,R56*[^11] | 20 Ohm | chip 1206, 805 | 2
R1-R6,R44 | 51 Ohm | chip 1206, 805 | 7
R17,R45,R49 | 100 Ohm | chip 1206, 805 | 3
R48,R51 | 390 Ohm | chip 1206, 805 | 2
R8,R10,R13,R19-R21,R25,R29,R41,R42,R47 | 1 K | chip 1206, 805 | 11
R50 | 3.3 K | chip 1206, 805 | 1
R7,R9,R11,R12, R14-R16,R18,R22-R24,R26-R28,R30-R38,R40,R43,R46,R53 | 6.8 K | chip 1206, 805 | 27
R54*[^12] | 100 K | chip 1206, 805 | 1
R52 | 1 M | chip 1206, 805 | 1
others прочее
position позиция | name наименование | pattern корпус | pcs кол-во | аlternate альтернатива
J1 | board reset enable перемычка: аппаратный сброс с материнской платы | PLS-2 | 1
S1 | reset button кнопка сброса | PKN | 1
X1 | JTAG | IDC10 | 1
X2 | sound 3.5mm jack аудио-разъем | CKX3.5-001 | 1
X3 | sound | PLS-4 | 1
XSD1, XSD1* | SD card holder держатель карты | SDC09W4 | 1 | Micro SD TPF09-2-12B
D5 | PLCC32 socket сокет для установки ПЗУ | PCC32-DIP | 1

# Приложение 3. Схема программатора ByteBlaster MV

Приводится по оригинальной схеме из документации Altera “ByteBlasterMV Parallel Port Download Cable Data Sheet”.

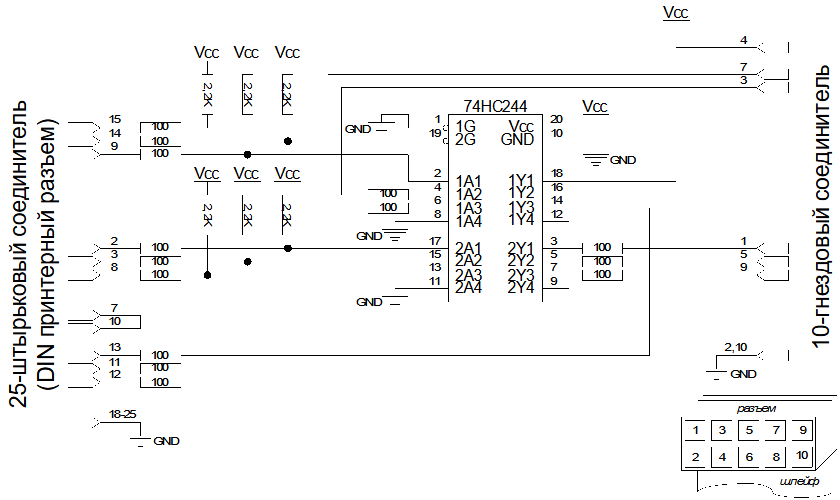
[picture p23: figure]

ЗАМЕЧАНИЯ:

- Подключение программатора к PC компьютеру производится через принтерный разъем.
- При изготовлении программатора необходимо учесть, чтобы длина кабеля соединяющего программатор с 10-гнездовым разъемом была не более 10..15см.

[^1] Устанавливается в разъем PLCC44 socket с штыревыми контактами.
[^2] Устанавливается вместо D8 при использовании звуковых чипов VLSI VS10xx.
[^3] Устанавливается вместо DA1 с напряжением стабилизации 3.3В (при использовании звукового чипа VLSI VS1003 нужно ставить с напряжением стабилизации 2.8В) смотри раздел 3.
[^4] Устанавливается при использовании звукового чипов VLSI VS10xx – смотри раздел 3.
[^5] Устанавливается вместо DA7* - смотри раздел 3.
[^6] Устанавливается только при использовании звуковых чипов VLSI VS10хх — смотри раздел 3.
[^7] Устанавливается только при использовании звуковых чипов VLSI VS10хх — смотри раздел 3.
[^8] С52* устанавливается только при использовании звуковых чипов VLSI VS10хх — смотри раздел 3.
[^9] Устанавливается только при использовании звуковых чипов VLSI VS10хх — смотри раздел 3
[^10] Устанавливается только при использовании звуковых чипов VLSI VS10хх — смотри раздел 3.
[^11] Устанавливается только при использовании звуковых чипов VLSI VS10хх — смотри раздел 3.
[^12] Устанавливается только при использовании звуковых чипов VLSI VS10хх — смотри раздел 3.

Сборка и настройка звуковой карты NeoGS C-VS

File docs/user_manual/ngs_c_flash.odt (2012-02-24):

# О прошивке EPM3064 в NeoGS rev. C.

Рассмотрено прошивка микросхемы Altera EPM3064 с помощью программатора ByteBlaster MV и программного обеспечения Quartus II Web Edition.

Внимание: Не используйте для программирования программу Altera MaxPlus. Она не распознает случай когда микросхемы объединены в цепочку.

## Подаем на плату NeoGS питание и подсоединяем ByteBlaster MV.

Подаем питание на плату NeoGS, например, установив ее в слот ZXBUS компьютера.

Программатор ByteBlaster MV нужно использовать в режиме «питание для программатора берется с платы» (т.е. питание на программатор подавать не надо, оно берется с разъема на NeoGS).

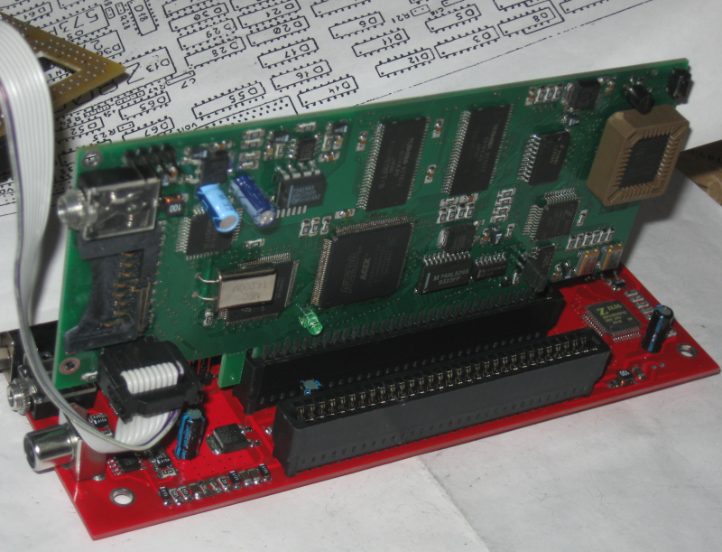
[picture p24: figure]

## Использование Quartus II.

1. Запускаем программу Quartus.

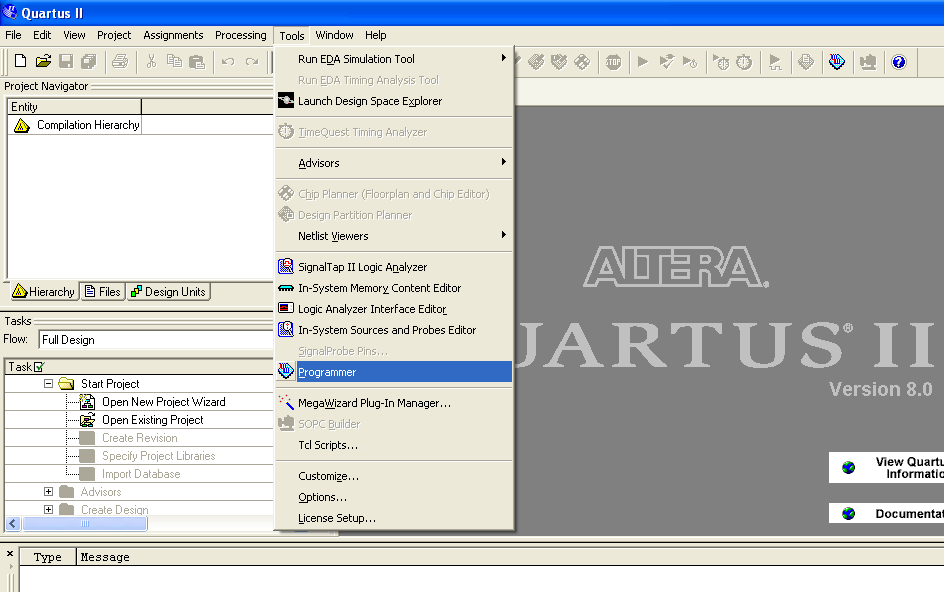
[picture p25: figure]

2. Выбираем программирование (см. рисунок)

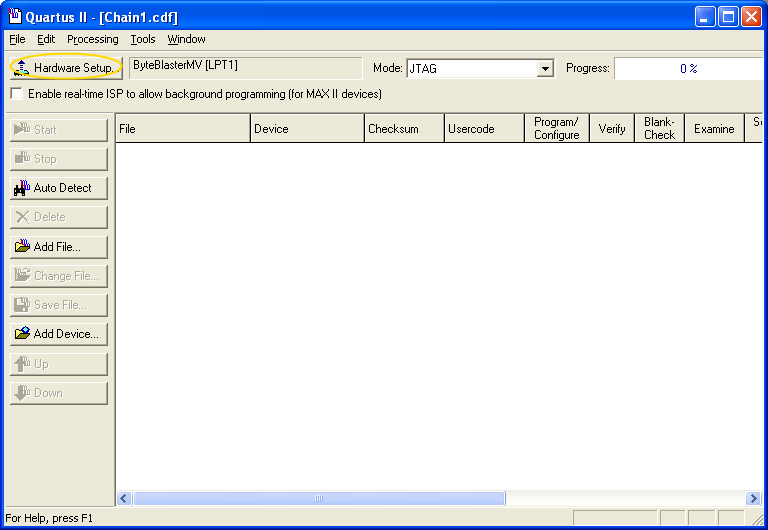
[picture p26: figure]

3. Вылезет окно для управление программированием. В нем нажмем кнопку — Hardware Setup (см.рисунок), чтобы выбрать тип программатора.
4. В окне Hardware setup установите программатор ByteBlaster MV (см. рисунок) и нажмите кнопку Close.

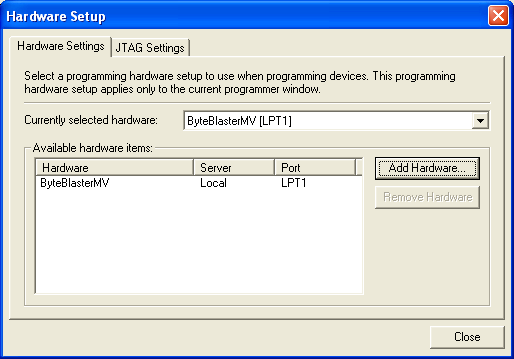
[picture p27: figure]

5. После установки типа программатора, нажмите кнопку AutoDetect для определения типа микросхем, которые мы хотим запрограммировать. В списке рабочего окна появится множество микросхем (см. рисунок). Если множество не появилось или произошла ошибка, то нужно устранить ее (скорей всего ошибки при сборке NeoGS или программатора).

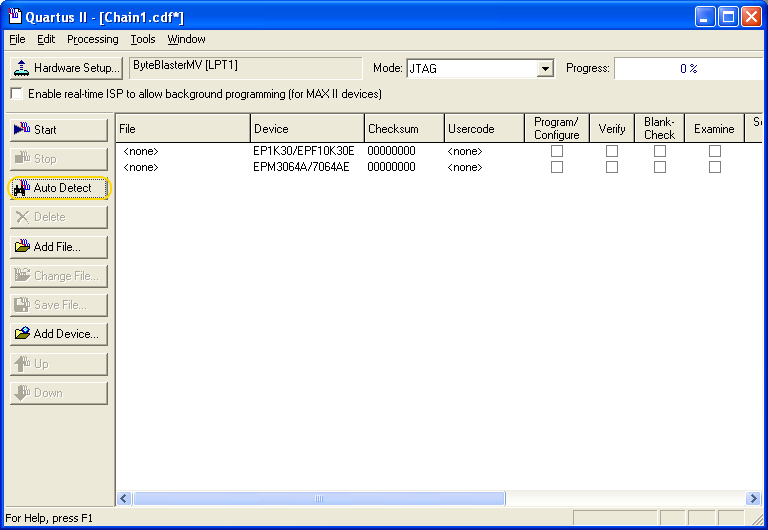
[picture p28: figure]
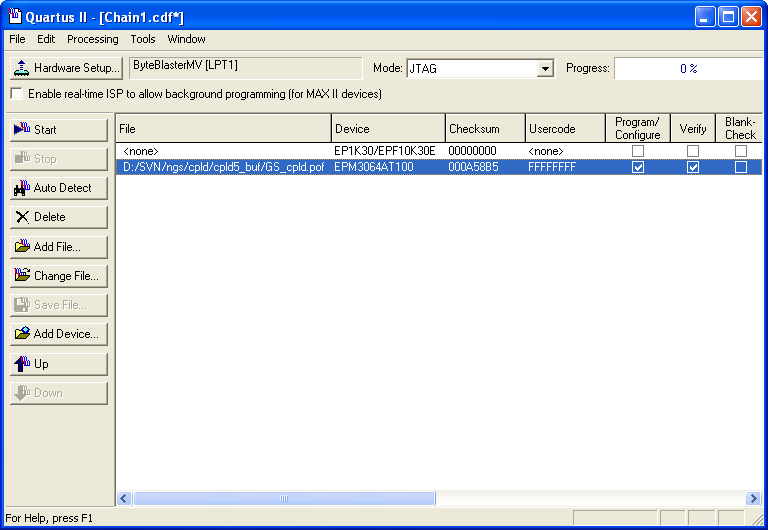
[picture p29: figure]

6. Выберите файл для программирования щелкнув двойным щелчком под заголовком File и на строке где находится микросхема EPM3064, а также установите галки под заголовками Programm/Configure и Verify (см. рисунок).
7. Нажмите кнопку Start для того чтобы запрограммировать микросхему (см. рисунок). Процесс программирования будет отображаться на прогресс-баре Progress.

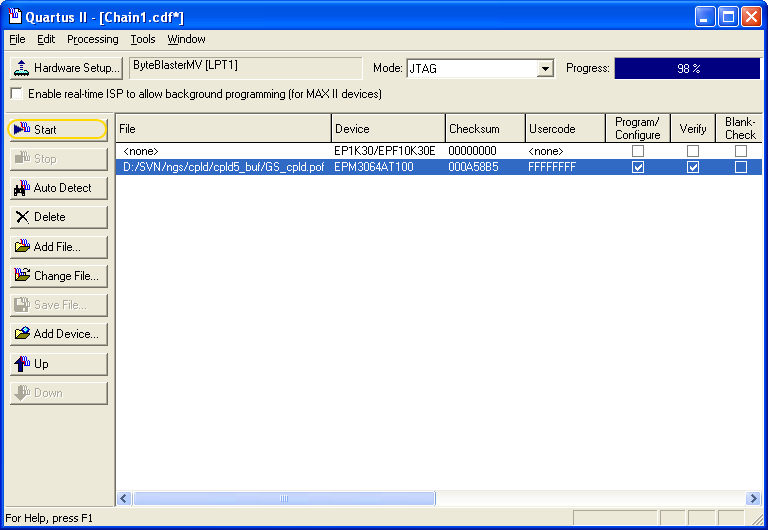
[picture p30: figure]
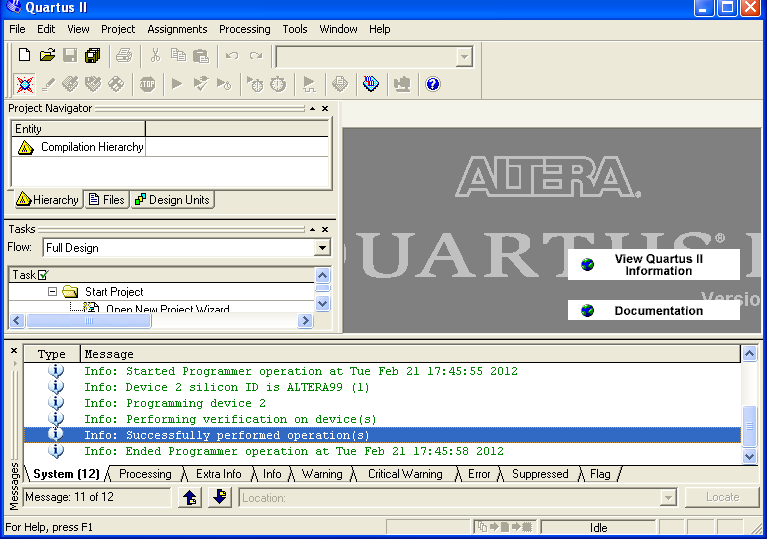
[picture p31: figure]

8. Если программирование прошло успешно, то в основном рабочем окне программы Quartus появиться отчет.
9. Если программирование микросхемы не удалось, то в отчете будет написана причина ошибки. Рекомендую повторить программирование в этом случае (иногда помогает).

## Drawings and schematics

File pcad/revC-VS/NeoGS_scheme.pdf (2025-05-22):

A7 | D¹ A¹² | D³ GND GND | D⁵ D⁶
AGND | VCC⁵

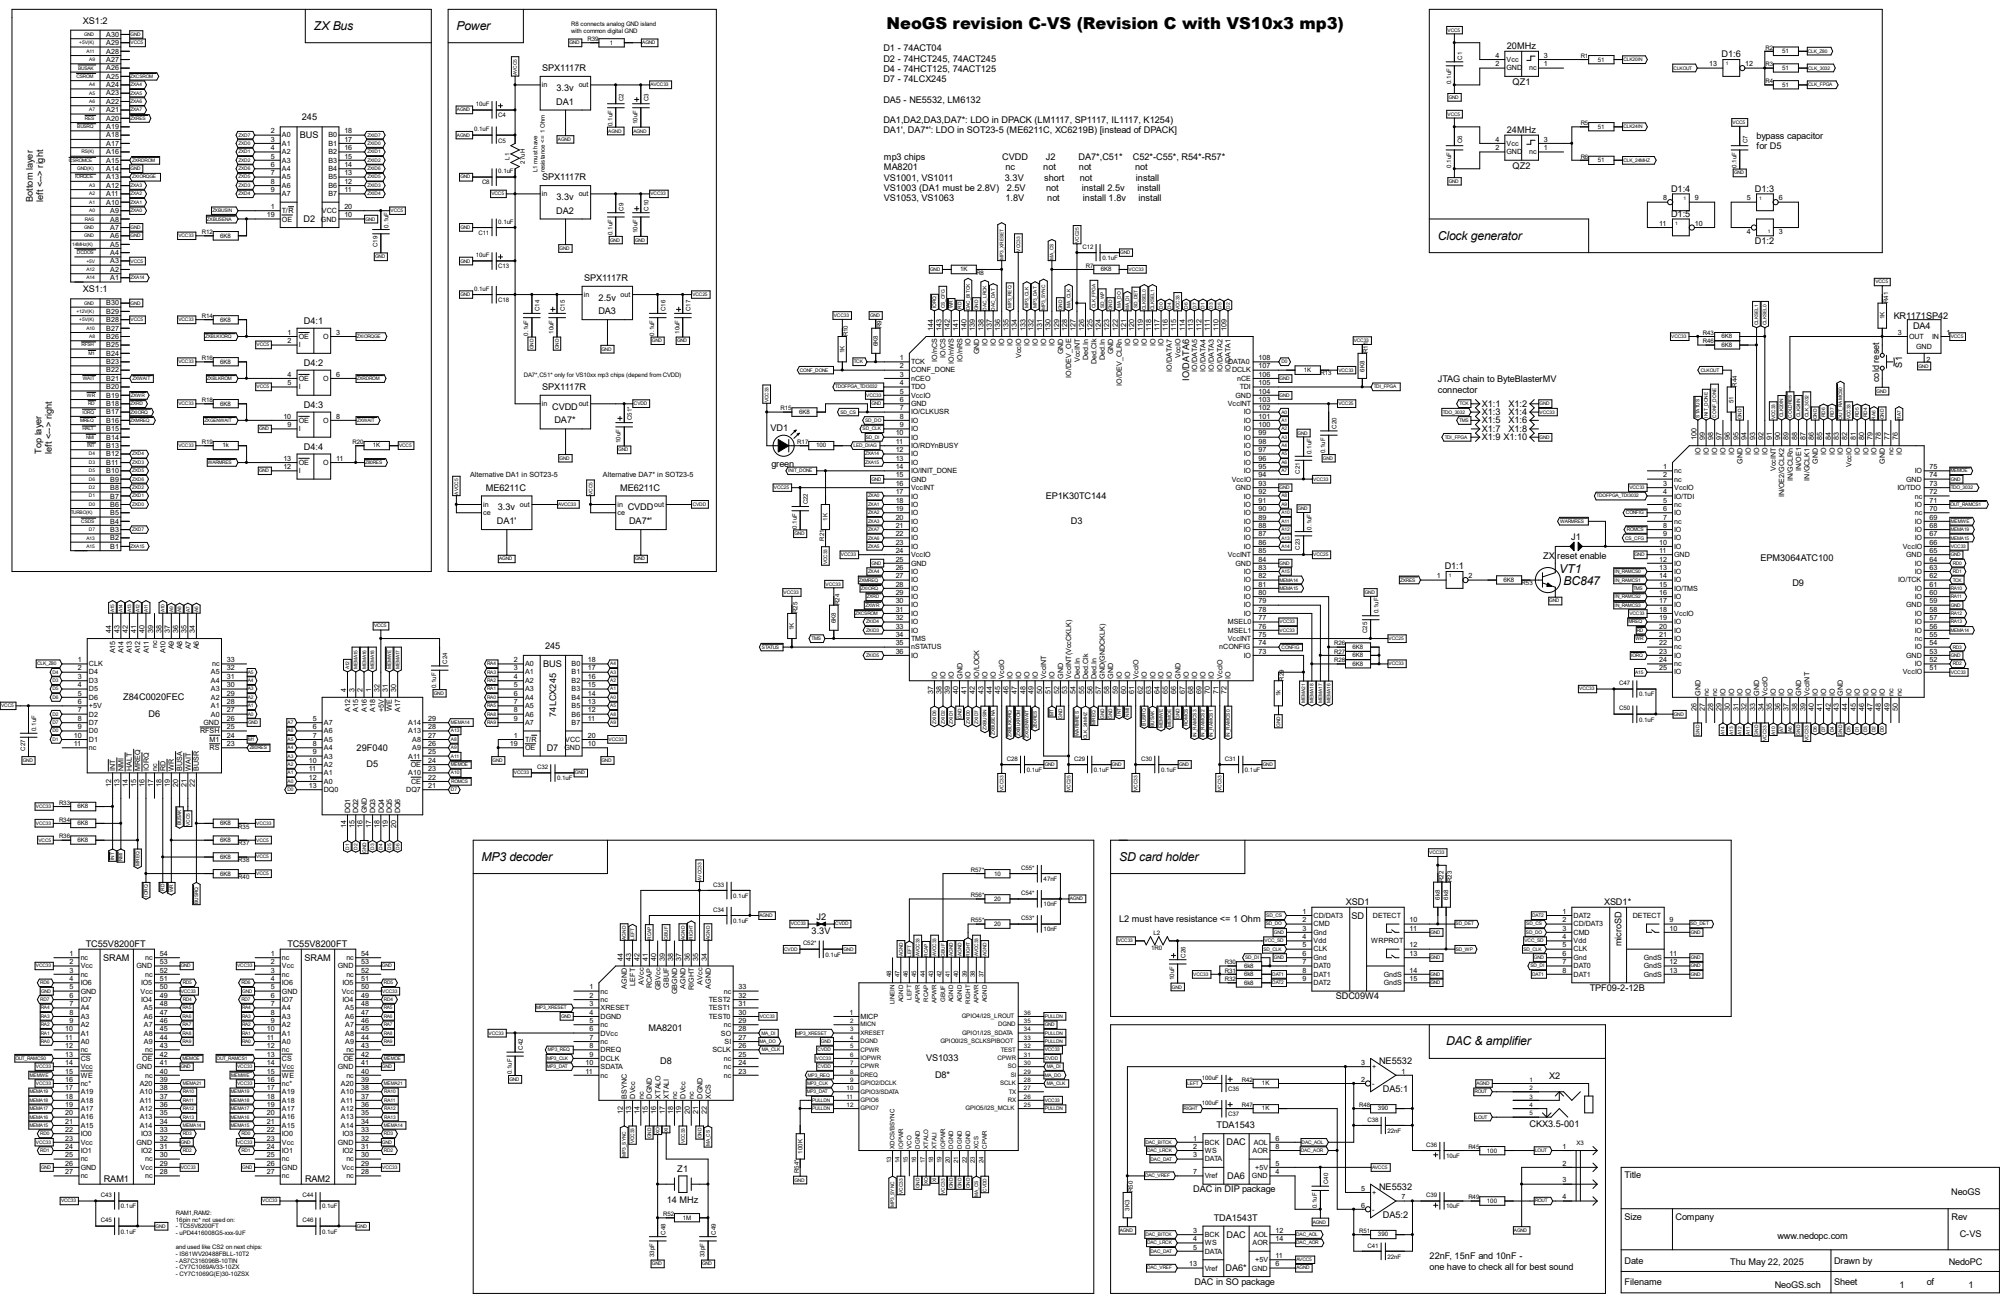
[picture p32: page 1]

R8 connects analog GND island
with common digital GND

NeoGS revision C-VS (Revision C with VS10x3 mp3)
3.3v L1 must have resistance <= 1 Ohm

ZXD1 Bottom layer left <⁻⁻> right

A3 | A12 | ZXID3

A1 | A10 | ZXA1
A0 | A9 | ZXA0 VCC5

A14 | A1 | ZXA14

D6 Top layer left <⁻⁻> right

MREQ | B16 | ZXMREQ ZXWAIT

73 IO/TDO ⁸⁴ IO ⁹⁶ IO

D1 | B7 | ZXD1

L2 must have resistance <= 1 Ohm

36 GPIO4/I2S_LROUT ⁴⁸ LINEIN 13 XDCS/BSYNC

DAC in DIP package

22nF, 15nF and 10nF -
one have to check all for best sound

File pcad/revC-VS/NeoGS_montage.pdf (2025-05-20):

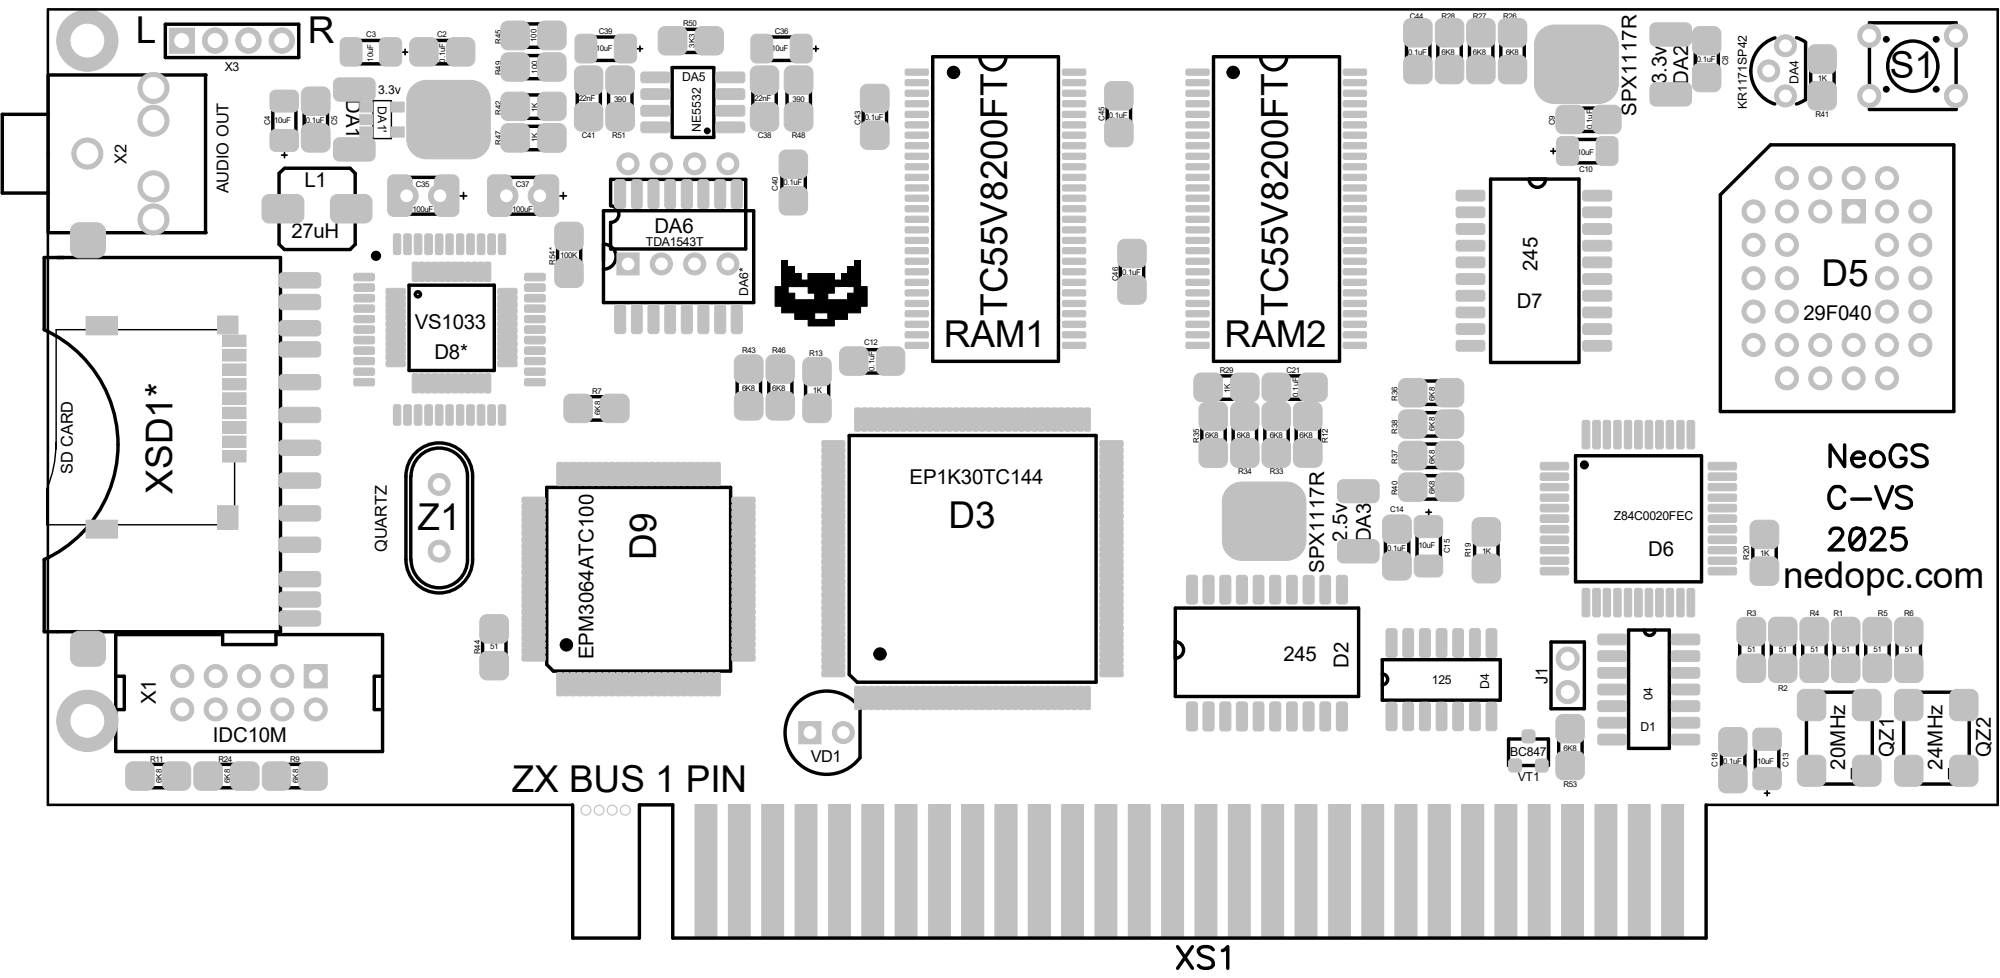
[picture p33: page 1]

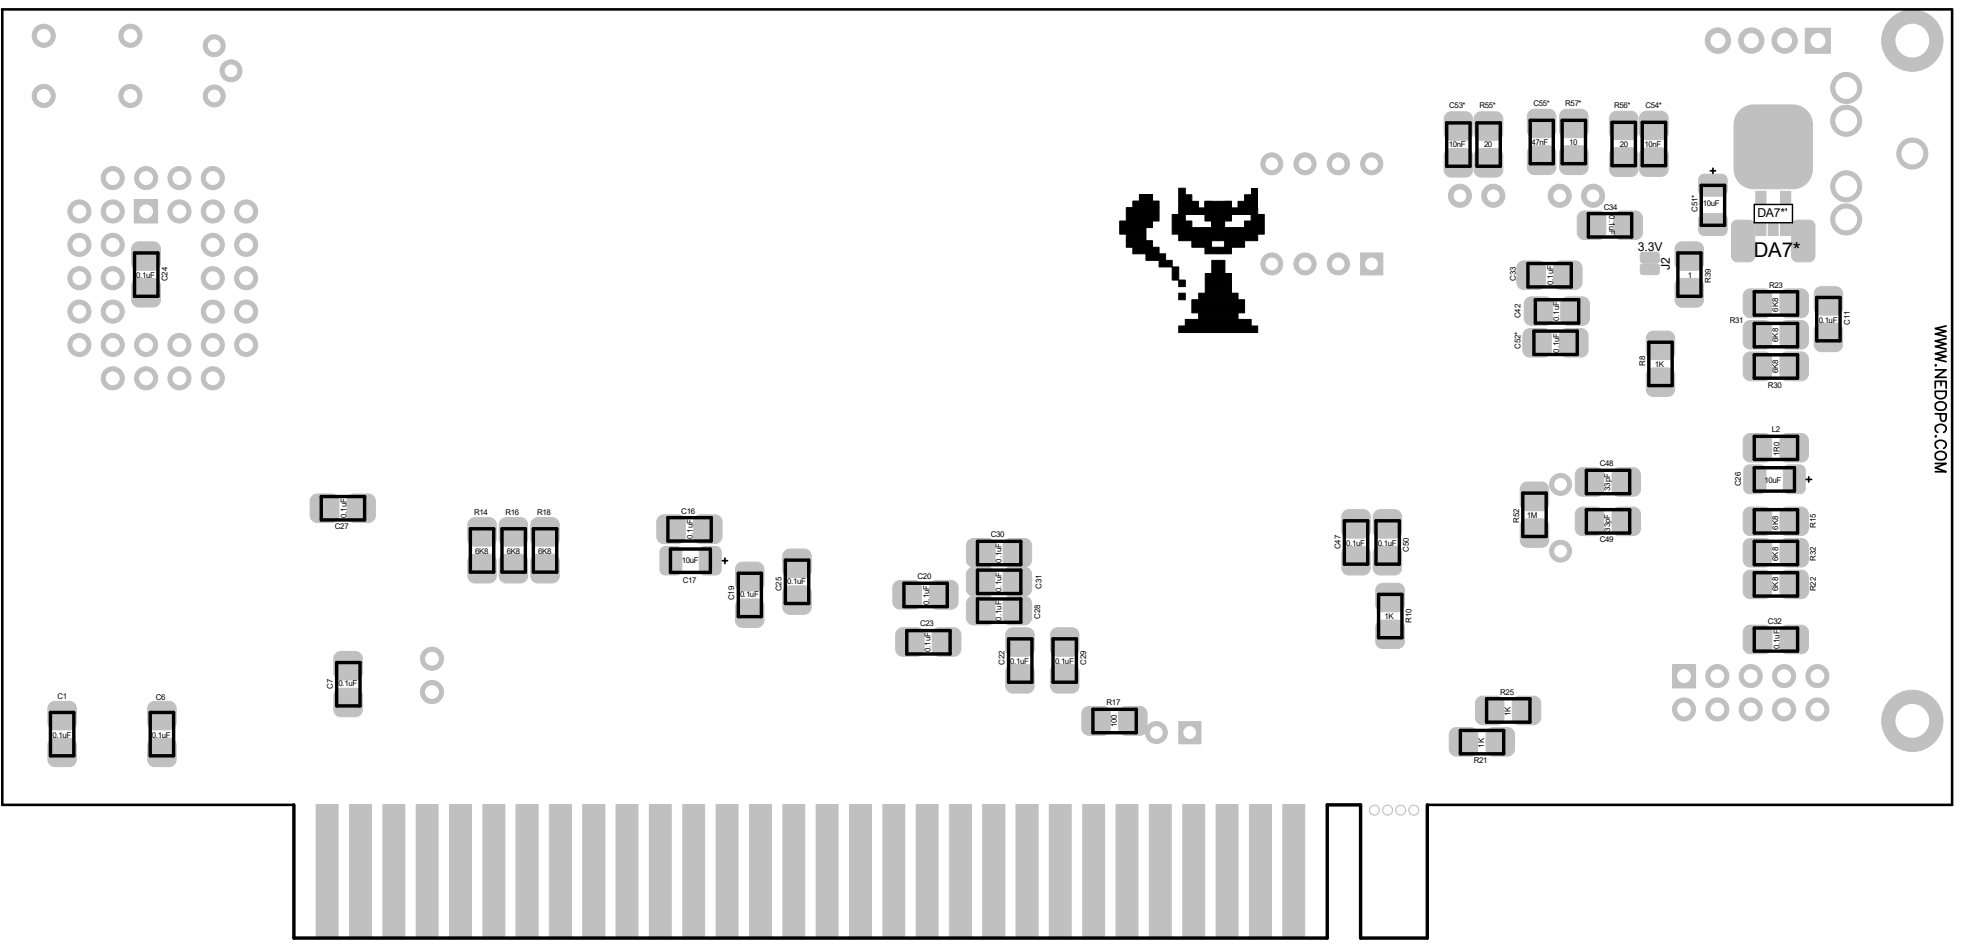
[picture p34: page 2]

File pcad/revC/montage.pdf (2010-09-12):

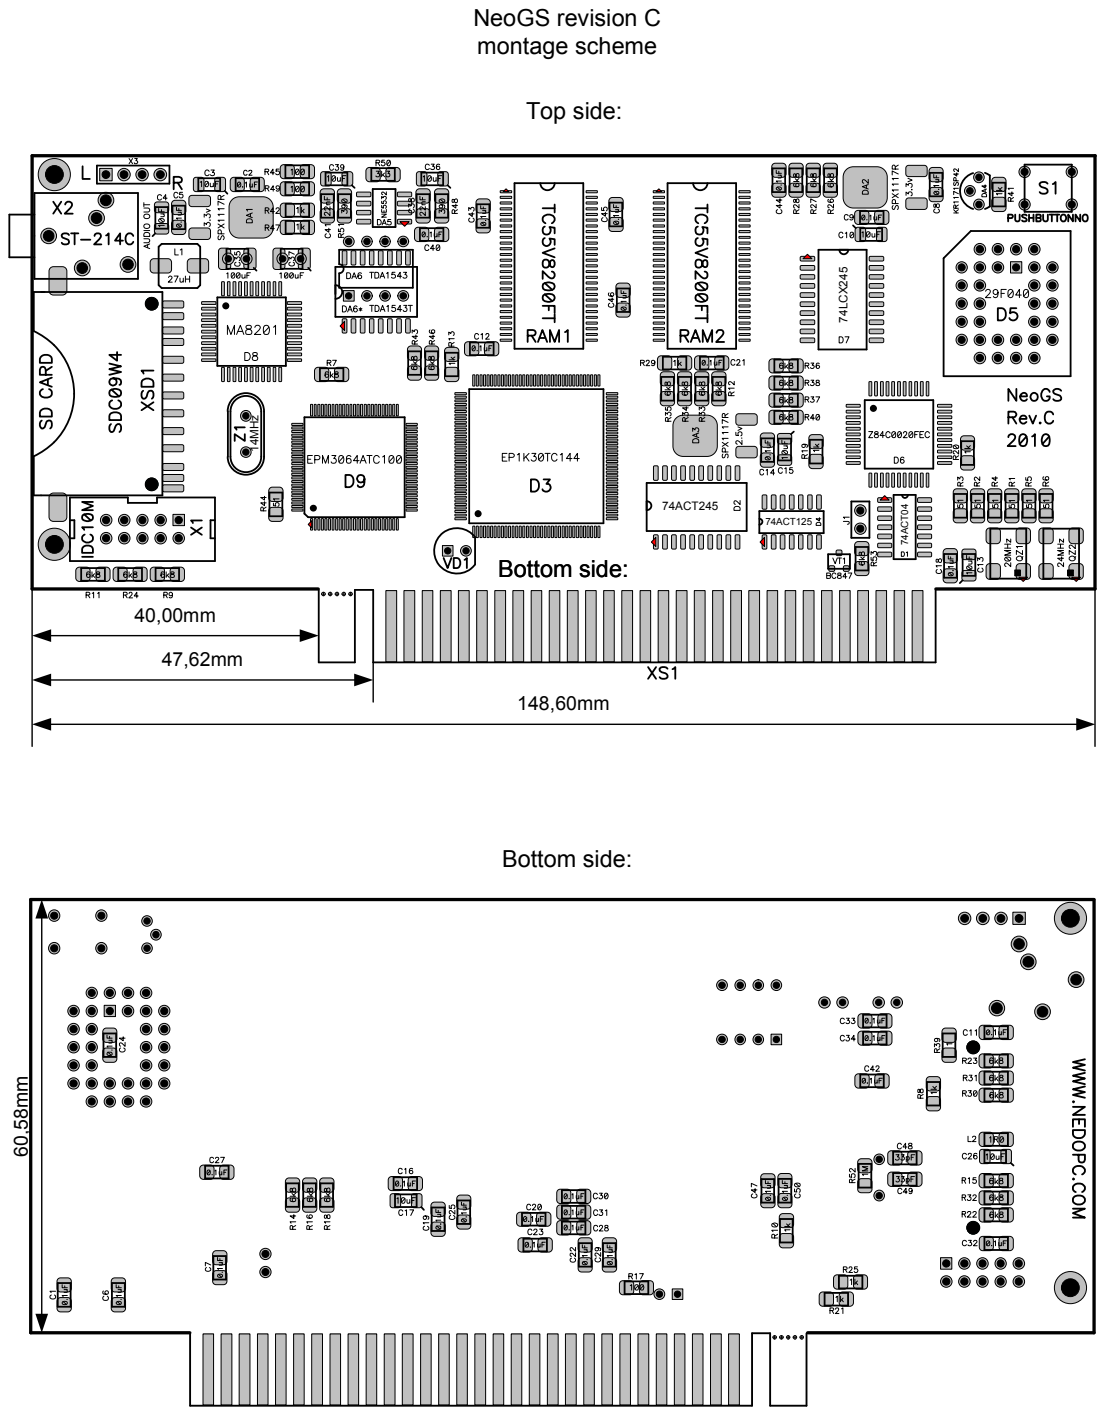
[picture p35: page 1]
14MHz; 74ACT245; 74ACT125; 74ACT04; 74LCX245; NeoGS revision C montage scheme; Top side:; Bottom side:

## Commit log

2009-11-21 Initial commit: FPGA part under development (added dma_sequencer, adding sd dma)
2009-11-26 Something added
    [NewGS.sch]
2009-12-06 port GSCFG0, bit 7 - inversion of samples
2009-12-20 added cpld variant for buffering Z80 busses to 3v memory
2010-02-12 start revision C
    [NeoGS.sch]
2010-03-14 epm3064atc100 add
    [NeoGS.sch]
2010-03-16 fixed revc/NeoGS.sch a bit; added some suggestions to revc/todo.txt
    [NeoGS.sch]
2010-03-17 start of big changes in cpld5_buf and revC schematics \(probably\)
    [NeoGS.sch]
2010-03-18 Some suggestions
    [NeoGS.sch]
2010-03-21 revC schematics updated, cpld5_buf updated for rev.C board: no checking, no pinmapping yet
    [NeoGS.sch]
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2010-04-14 rommap test done for rtl
    [NeoGS.sch]
2010-04-26 Добавил ужасм в тулзы и засвнил загрузчик, который надо еще немного подправить для обновления
2010-04-26 Залил сорцы прошивки gs105a. Со всеми внесенными патчами.
2010-05-12 Исправил некоторые ошибки в загрузчике
2010-05-15 CHRV, 15.05.2010: + SCH: заменил титульную надпись + SCH,LIB: добавил TDA1543T (в SO корпусе) как альтернатива DIP корпусу
    [NeoGS.sch]
2010-05-15 pin assigment (equal sch)
2010-05-15 сделал развязку для warmreset
    [NeoGS.sch]
2010-05-19 added correct ZX reset part to revC schematics
    [NeoGS.sch]
2010-06-02 begin routing
    [NeoGS.sch]
2010-07-26 updated pinout of CPLD for current .sch
2010-08-03 latest rev.C PCB from CHRV
2010-08-31 + PCB: complete + LIB: increase pads on OS7x5
2010-09-12 + SCH: исправил ошибки в наименовании элементов + SCH: добавил текст по логическим микросхемам + SCH: растащил немножко чертеж чтобы лучше печаталось + PCB: по просьбе резонита заменил дырки в слое b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
    [NeoGS.sch]
2010-09-12 yet unsuccessful try to adapt ramtest to revC board, where old ramtest does not work
2010-09-22 + PCB: Разрешил земляные вопросы в разводке.
2010-11-17 Залил доку на загрузчик нгса
2010-11-24 started refucktoring code and adding new features to FPGA. now fpga/current is head of development (not checked yet)
2010-11-25 fpga/current: added 4mb addressing
2010-11-25 fpga/current: split dma_sd and dma_fifo_oneshot
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2011-01-16 fpga/current: fresh build, z80/bootFPGA: fresh build (NOT CHECKED YET!)
2011-01-17 Залил асм. Добалены диры сборщика апдейтов (create_update) и нового флешера (flasher). Ридми в обоих дирах. Подновил доку на формат заголовка апдейта. Подправил доку на загрузчик.
2011-01-18 добавил: 4.3 Соответствие нумерации каналов Amiga и General Sound, немного расширил: 4.1.66 #46 Set FX Sample Seek First parameter 4.1.67 #47 Set FX Sample Seek Last parameter 4.1.65 #45 Set FX Sampl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
2011-01-19 Кое каие мелочи поменял, обновил апдейтер с новым фпга. Предыдущая переимеванная пока оставлена. Пересобрал сам апдейт и проверил.
2011-01-22 Добавил в прошивальщик паузу, а то после прошики нгс оболочка могла повисать. На прошивание не влияло, но смотрелось не фонтан.
2011-01-24 updated NGS_prm.odt and ports.inc: added DMA documentation and ports
2011-01-24 Перенес обработчик прерываний в другой адрес, освободил место под таблицу страниц. Таблица создается в зависимости от объема памяти. Версию обозвал 1.06. Zplayer и WP работают. Во флешере сделал окош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
2011-01-24 Исправил одну переменную в прошивке иначе для 4 метровых нгсов обнуляло одну страницу в таблице. Апдейт пересобрал.
2011-01-24 Перевел менюшке флешера на английский и добавил окошко о прошивании.
2011-01-30 Сделал отображалку версий прошитых страниц во флешере. В основной прошивке поменял номер версии где надо, менять надо было в 2 местах. Пересобрал обновление.
2011-02-09 Исправил даты, даты можно менять в файле create_update.a80 отдельно для самого обновления и для каждой страницы. Сейчас вбито только для страниц 0,1,7.
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2013-05-21 fixed interrupt bug, sd-mp3 dma seems to work in SDMP3_TEST config and sdmp3_test.s src
2013-05-25 Залил сорцы плеера 0.44, обновил инструментарий и кучку всякого разного.
2013-05-29 added npl044 modified to use sd and mp3 dma
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2013-06-07 Исправил ошибку потери адреса сохранения номеров секторов
2013-06-08 Еще пару исправлений
2013-06-18 Обновил основную прошиву до 1.09, обновил загрузчик, обновил плеер mp3/mod до 0.51, понаписал доки
2013-06-18 дописал текстовый файлик в папку docs где что искать
2014-04-24 Поправил сборщик прошивки. Теперь бинарик для фпга берется из соотвествующей диры.
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2014-05-18 ngs: added onlyclock version of CPLD for rev.C board
2014-08-08 Прошивка NeoGS 1.10 и Neo player light 0.52
2014-09-29 Версия плеера 0.53. Исправил баг смены карты при большом размере кластера.
2014-11-13 pgmflash: fixed scroll, removed device selection
2016-02-24 Добавил утилиту TapTool для работы с *.tap файлами и сделад версию tape версию плеера. Сам плеер версии 0.53
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2021-05-27 Обновил компилер асма, исходники асма в свн Pentevo
2021-05-28 Neo Player Light 0.54: поправлено зависание выхода/перезапуска при отсутствии карты в NeoGS. Flasher 0.22: - добавлено отображение номера версии основной прошивки. - поправлены сборочные батники. - д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
2021-05-28 Удалил из свн результаты сборки (4 ROM файла)
2022-07-17 Добавлено описание различий между ревизиями C и C3 от Тетроида
2023-04-22 Обновление плеера: - добавлена сборка (адаптация) для компьютера Sprinter в виде EXE файла. - мелкое исправления в FAT драйвер внутреннего плеера.
2023-04-26 Neo Player Light 0.57: - исправлено, не работало на картах более 4Gb. Переделан поиск директорий и файлов.
2024-09-03 Версия 0.58: - добавлена поддержка новых чипов. - переделан детект типа MP3 чипа. - добавлено несколько pdf по новым чипам.
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2025-01-16 исправлено ридми
2025-03-30 - start working with revision C-VS
    [NeoGS.sch]
2025-03-31 update sch and pcb (simplify scheme)
    [NeoGS.sch]
2025-04-01 update NeoGS rev C-VS
    [NeoGS.sch]
2025-04-02 Add microSD XSD1\* alternate to SD
    [NeoGS.sch]
2025-04-05 ngs\pcad\revC-VS\NeoGS.pcb: - replaced refdes and values - drawn cat
2025-04-06 NeoG C-VS: some corrections
    [NeoGS.sch]
2025-04-07 NeoGS C-VS: - add resistive load for VS10xx - add DA1' and DA7*' (LDO SOT23-5) like alternative DA1 and DA7* (LDO DPACK)
    [NeoGS.sch]
2025-04-16 add gerbers
    [NEOGS.DRL, NEOGS.GBL, NEOGS.GBO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]
2025-04-23 NeoGS revC-VS: - add montage list - add BOM
2025-04-26 sch rev C-VS: some fixes (c52* set ttf)
    [NeoGS.sch]
2025-05-20 Neo Player Light: - добавлена поддержка чипов VS1003, VS1053, VS1063. В основной прошивке добавлена поддержка 512к для работы на старом ГС. На старом ГС не проверялось ввиду отсутствия.
2025-05-20 Neo Player Light: перезаливка той же версии - поправлена цветовая полоска версии зависящая от MP3 чипа.
2025-05-20 revC-VS: add support SRAM memory with 16pin:CS2
    [NeoGS.sch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]
2025-05-22 revC-VS: - corrected descriptions on scheme; - updated soldering manual; - add photos.
    [NeoGS.sch]
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2026-02-07 Main ROM версия 1.11: - исправлено несоответствие версий основной прошивки. - пересобран файл обновления. - переделано определения количества страниц памяти, теперь определяет размер памяти 512К, 204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
2026-02-08 Flasher NeoGS v0.23: - в меню флешера пункт "Exit" переделан в "Reset NeoGS & Exit", при выборе программно сбрасывается NeoGS и производится выход в TR-DOS. - переделан сборщик проекта.
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
